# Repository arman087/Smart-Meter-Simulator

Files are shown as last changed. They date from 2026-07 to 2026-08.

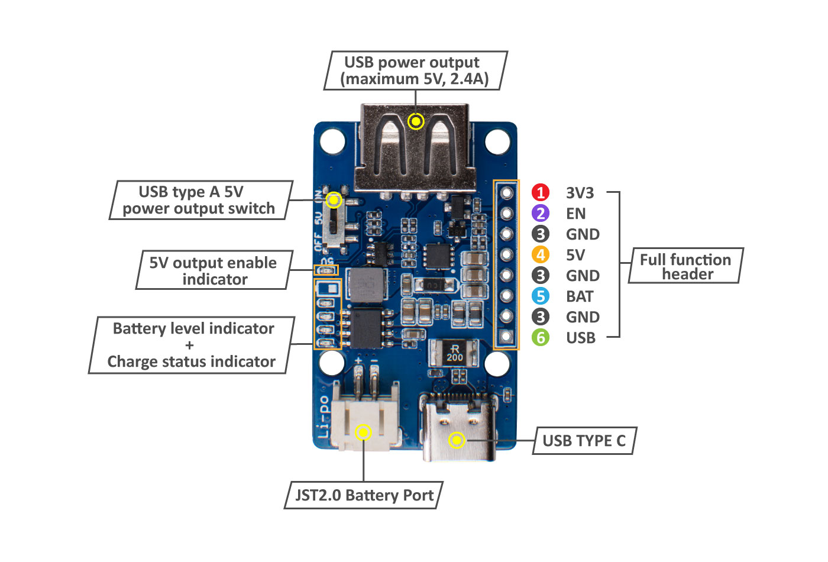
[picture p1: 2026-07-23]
mechanicals/lipo_rider_plus/pinout.jpg

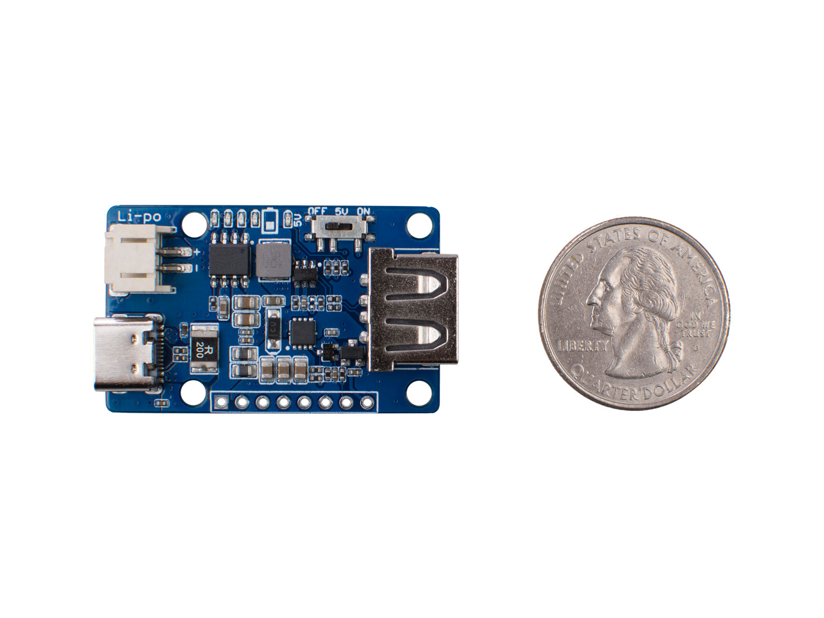
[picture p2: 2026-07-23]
mechanicals/lipo_rider_plus/front.jpg

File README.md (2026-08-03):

# Smart Meter Simulator

Portable lab board that **acts like a Dutch/Belgian DSMR smart meter P1 port**.  
Park it on battery in a building corner, plug in [P1 Ghost](https://github.com/arman087/P1_ghost), and test Ghost Wi‑Fi range without a real meter.

| This board (meter) | P1 Ghost / OSM (reader) |
|---|---|
| Female RJ12 | Male RJ12 |
| **Supplies** +5 V on pin 1 | Takes +5 V |
| **Senses** Data Request on pin 2 | Drives Request high |
| **Open-collector / opto** Data on pin 5 | Reads Data |

**MCU:** ESP32-C3-MINI-1 (Wi‑Fi on for config / OTA) · **P1 serial:** 115200 8N1 inverted open-drain  
**Telegram store:** microSD · **Build volume:** ~5 boards (JLCPCB)

**Why / how:** **[DESIGN_REPORT.md](DESIGN_REPORT.md)** · **Firmware:** **[FIRMWARE_GUIDE.md](FIRMWARE_GUIDE.md)** · **Pause / next:** **[NEXT_STEPS.md](NEXT_STEPS.md)** · **KiCad:** `my_design/Slimme_meter_Sim/`

---

## Progress (schematic + PCB — Aug 2026)

| Block | Status |
|---|---|
| USB-C → bq25185 → TPS61023 → **SYS_5V** | Drawn (`SCH_1_USB_5volt_sch`) |
| **TPS26625** eFuse → `P1_5V`, caps, green power LED, test points, RJ12 | Drawn |
| **SY8088** buck → **VCC_3V3** | Drawn |
| **ESP32-C3-MINI-1** on 3V3; EN RC; GPIO2/8 pull-ups; USB = GPIO18/19 | Drawn |
| RGB on GPIO10; Schottky-fed LED supply | Drawn |
| **6N137S** Data TX (GPIO21 / `ESP32_TX` → pin 5) + Request (`RJ12_pin2` → `ESP32_enable`) | Drawn |
| PCB placement / routing | In progress (saved in KiCad) |
| Assemble first board (stencil + hot air) | See [NEXT_STEPS.md](NEXT_STEPS.md) |
| Optional: Pi as alternate “brain” (own PSU; board keeps P1 power path) | Parked in [NEXT_STEPS.md](NEXT_STEPS.md) |
| microSD, ESD polish | Later |

Sheets: `SCH_1_USB_5volt_sch.kicad_sch` · `SCH_2_power_supplies.kicad_sch`

**Firmware pin polarities / UART invert:** see **[FIRMWARE_GUIDE.md](FIRMWARE_GUIDE.md)** (Request = active **LOW**, Data via OC opto).

---

## Locked power architecture

```
USB-C ──► bq25185 ──► VSYS / V+ (≈3.0–4.5 V) ──► TPS61023 ──► SYS_5V (+5 V)
              │                                      │
           LiPo (2-wire)              ┌──────────────┴──────────────┐
                                      ▼                             ▼
                               SY8088 → 3.3 V              TPS26625 (hiccup)
                                      ▼                             ▼
                                  VCC_3V3                        P1_5V → RJ12 pin1
                                  ESP32 / SD
```

| Net | What it is |
|-----|---|
| `VSYS` / `V+` | bq25185 system rail — **not** 5 V |
| `SYS_5V` | TPS61023 boost |
| `VCC_3V3` | SY8088 from `SYS_5V` |
| `P1_5V` | TPS26625 out (~250 mA DSMR-like) |

---

## What’s left: Request + Data optos (important)

**Do not** wire ESP32 UART TX (3.3 V push-pull) straight to RJ12 pin 5.

There are **two domains**:

1. **MCU side = 3.3 V** — ESP32 GPIO / UART only talks to the **LED** of each opto.  
2. **P1 side = 5 V** — RJ12 pins 1/2/5 live here (`P1_5V`, Request, Data). Opto **transistor** open-collector sits on this side.

### A) Data Request (pin 2 → GPIO) — “Ghost says start sending”

```
RJ12 pin2 (P1_REQ, ~5 V when active)
    │
    R_LED ──►| opto LED |── GND          ← 5 V / P1 side
                   ║
              opto transistor
                   ║
VCC_3V3 ── Rpu ── collector ──► ESP32 GPIO   ← 3.3 V side
                   emitter ── GND
```

- You **never drive** pin 2 from the MCU.  
- Use a **fast** opto (TLP2361 / 6N137 class — not slow PC817).  
- Firmware: GPIO high/low (document polarity) → start/stop telegram TX.

### B) Data out (GPIO TX → pin 5) — open-collector / opto

```
ESP32 TX (3.3 V) ── R_LED ──►| opto LED |── GND     ← 3.3 V side only
                                  ║
                             opto transistor
                                  ║
RJ12 pin5 (P1_DATA) ── collector     (open collector)
                         emitter ── GND
                         optional: 4.7 kΩ to P1_5V for bench without Ghost
```

- **UART pin stays at 3.3 V** — it only lights the opto LED.  
- **Pin 5 is the 5 V / OC world** — transistor pulls Data low; Ghost’s pull-up (or your 4.7 kΩ) makes high.  
- 115200 baud → **fast** opto.  
- Detail notes: `circuits/07_data_request_sense/` · `circuits/08_open_collector_data/`

---

## Subcircuits

| Folder | Status |
|---|---|
| [circuits/01_usb_c_input](circuits/01_usb_c_input) | USB data → ESP32 |
| [circuits/02_battery_and_power_mux](circuits/02_battery_and_power_mux) | bq25185 + TPS61023 |
| [circuits/03_5v_to_3v3](circuits/03_5v_to_3v3) | **SY8088** → 3.3 V |
| [circuits/04_p1_5v_current_limit](circuits/04_p1_5v_current_limit) | **TPS26625** + RILIM calc |
| [circuits/05_esp32_c3_mini](circuits/05_esp32_c3_mini) | ESP32-C3-MINI-1 |
| [circuits/06_rj12_connector](circuits/06_rj12_connector) | RJ12 meter jack |
| [circuits/07_data_request_sense](circuits/07_data_request_sense) | Pin 2 → opto → GPIO **← do next** |
| [circuits/08_open_collector_data](circuits/08_open_collector_data) | TX → opto OC → pin 5 **← do next** |
| [circuits/09_esd_protection](circuits/09_esd_protection) | USB + RJ12 ESD |
| [circuits/10_ui_led_button](circuits/10_ui_led_button) | RGB + optional button |
| [circuits/11_optional_isolation](circuits/11_optional_isolation) | Optos + optional iso DC-DC |
| [circuits/12_microsd](circuits/12_microsd) | microSD |

## References

- [P1 Companion Standard 5.0.2](https://www.netbeheernederland.nl/sites/default/files/2024-02/dsmr_5.0.2_p1_companion_standard.pdf)
- [TI slvaf94 — TPS2662](https://www.ti.com/lit/pdf/slvaf94)
- [TI bq25185](https://www.ti.com/product/BQ25185) · [TI TPS61023](https://www.ti.com/product/TPS61023)
- [arman087/P1_ghost](https://github.com/arman087/P1_ghost)

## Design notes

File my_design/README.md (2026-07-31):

# my_design

Working KiCad for the Smart Meter Simulator:

```
my_design/
  Slimme_meter_Sim/          ← product project (start here)
    SCH_1_USB_5volt_sch…     USB-C → bq25185 → TPS61023 → SYS_5V
```

## Power nets

```
USB-C → bq25185 → V+ / VSYS (3.0–4.5 V) → TPS61023 → +5V (SYS_5V)
```

- **bq25185** system rail = `VSYS` (schematic `V+`) — **not** 5 V  
- **TPS61023** is **required** — do not feed P1 or the 3.3 V regulator from `V+` alone  

## Docs

- [DESIGN_REPORT.md](../DESIGN_REPORT.md) — why / how so far  
- [DESIGN_GUIDE.md](../DESIGN_GUIDE.md) — architecture checklist  
- [PARTS_CHECKLIST.md](../PARTS_CHECKLIST.md)  

## Silicon refs

- https://www.ti.com/product/BQ25185  
- https://www.ti.com/product/TPS61023  
- https://www.ti.com/lit/pdf/slvaf94 (P1 foldback / TPS2662)

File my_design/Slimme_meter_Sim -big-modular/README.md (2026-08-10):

# Slimme meter Sim — big modular (hand-build)

**Active path:** this folder only.  
Parent `DESIGN_GUIDE.md` / root README are **not** source of truth for this build.

Portable **DSMR P1 meter-side** simulator: battery in a corner, Ghost on RJ12, Wi‑Fi range tests without a real meter.

---

## Locked modular plan (return-to-work)

| Piece | How it is built |
|---|---|
| **ESP32-S3** | **Module:** Espressif **ESP32-S3-DevKitC-1-N32R16V** (**WROOM-2**, 32 MB flash + 16 MB PSRAM) — same 2×22 headers, onboard 5 V→3.3 V LDO. Alt: **N16R8V** |
| **USB-C (charge)** | **Breakout module** → soldered/wired to main PCB (not a tiny USB-C footprint on your board) |
| **microSD** | **Breakout module** → SPI wires to DevKit (not onboard SD slot) |
| **Charger IC** | On **main PCB** — hand-solder (bigger package preferred) |
| **5 V boost** | On **main PCB** — hand-solder (**bigger package** preferred) |
| **eFuse / current limit** | On **main PCB** — **both** TPS2662 + TPS2553, select with jumper / 0 Ω |
| **Optos + RJ12** | On **main PCB** — **6N137 DIP-8** ×2, RJ12, ESD |

**Not on main PCB:** DevKit MCU, USB-C receptacle soldering challenge, SD cage soldering challenge.

---

## Power rules (do not loop-charge)

```
Main USB-C breakout ──► charger ──► LiPo / VSYS ──► boost ──► 5V_SYS
                                                              ├── eFuse → RJ12 pin 1
                                                              └── [SW] ──|>|──► DevKit "5V"

DevKit USB ──► program / first flash ONLY
               NEVER wired into the charger
```

| Rule | Why |
|---|-----|
| **Only main USB-C charges** | Avoids boost → DevKit 5V → charger fake-charge loop |
| **`[SW]` between 5V_SYS and DevKit `5V`** | Open while programming on DevKit USB; closed for normal run |
| **Diode on 5V_SYS → DevKit** | Extra reverse protection when switch is closed and habits slip |
| **After first flash** | Prefer Wi‑Fi / OTA; leave DevKit USB unused |

### Switch habit

| Mode | Switch `5V_SYS → DevKit` | USB |
|---|---|-----|
| First flash / recovery | **OPEN** | DevKit USB only |
| Field / normal | **CLOSED** | Main USB-C charge (or battery); talk over Wi‑Fi |

---

## Hand-solder focus (your three ICs)

1. **Charger** (e.g. path like bq25185-class / Adafruit #6106 as reference)  
2. **Boost** — bigger package / module-friendly footprint  
3. **eFuse** — see decision below  

Everything else painful (USB-C, SD) = **bought breakouts**.

---

## eFuse: populate **both**, select one

Put **TPS2662** (foldback / rich) **and** **TPS2553** (bigger / easy) on the same PCB. Only one path to RJ12 pin 1 is live.

```
5V_SYS ──┬──► TPS2662 ──┐
         │              ├── [jumper / 0 Ω / SW] ──► RJ12 pin1
         └──► TPS2553 ──┘
```

| Select | When |
|---|---|
| **TPS2662 path** | Reflow succeeded — use the “amazing” part |
| **TPS2553 path** | Tiny IC bridged / dead / skipped — still ship the board |

**Select hardware (pick one style in KiCad):**
- Two **0 Ω** positions (fit only one), or  
- **2.54 mm jumper** ( clearest for bring-up), or  
- SPDT switch (handy, slightly more drop/noise — fine for P1)

**Do not** leave both outputs paralleled with no select — fight / odd current paths.

Try the tiny IC with paste + hot plate; if it fails, open that path and close TPS2553. No board respin required.

---

## Tomorrow checklist

1. KiCad: power sheet — charger → VSYS → boost → `5V_SYS`  
2. KiCad: DevKit header footprint + **SW + diode** to DevKit `5V`  
3. KiCad: USB-C **breakout** connector footprint / pin header (VBUS, GND, maybe CC if needed)  
4. KiCad: SD **breakout** header (SPI + 3V3 + GND)  
5. KiCad: **both** eFuse footprints + **select jumper/0 Ω** → RJ12  
6. KiCad: 6N137 ×2 + ESD  

Detail: [ARCHITECTURE.md](ARCHITECTURE.md) · [PARTS_CHECKLIST.md](PARTS_CHECKLIST.md)

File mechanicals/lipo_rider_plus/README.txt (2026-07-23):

LIPO RIDER PLUS — DAUGHTERBOARD (CHOSEN POWER)
==============================================

Product
-------
Seeed Studio Lipo Rider Plus (SKU 106990290)
Wiki: https://wiki.seeedstudio.com/Lipo-Rider-Plus/
Buy:  Seeed / distributors — search "Lipo Rider Plus"

This is the project power solution: MCU charger/booster as a daughterboard.
Draw your own footprint if you prefer; files below are a reference.

Mounting on YOUR PCB
--------------------
Files in this folder:

1) Seeed_Lipo_Rider_Plus.kicad_mod
   KiCad footprint for the main board:
   - Board outline (~40.9 × 28.0 mm) from official Eagle .brd
   - 4× M3 clearance holes (3.2 mm) at official positions
   - 1×8 2.54 mm header pads matching J3

   How to use in KiCad:
   - Preferences → Manage Footprint Libraries → add this folder
     (or copy .kicad_mod into your project .pretty)
   - Place footprint; wire pads:
       1 USB   (sense only / optional)
       2 GND
       3 BAT   (optional monitor)
       4 GND
       5 5V    → SYS_5V
       6 GND
       7 EN    (pull to GND to cut 5V; leave open for ON)
       8 3V3   → VCC_3V3

   Stacking tip: solder a male 1×8 header on the Lipo Rider bottom,
   female 1×8 on the main PCB (or wire pads with short jumpers).
   Use M3 standoffs in the four holes.

2) Lipo_Rider_Plus_box.wrl
   Crude 3D placeholder box for KiCad 3D view (not accurate connectors).

3) sch_pcb/Lipo Rider Plus.brd + .sch
   Official Seeed Eagle design (source of outline / holes / header).

4) pinout.jpg / size.jpg / front.jpg
   Official photos from SeeedDocument/Lipo-Rider-Plus on GitHub.

Official / community 3D
-----------------------
- Official mechanical source: Eagle .brd in sch_pcb/ (best for holes).
- Community STEP (used by Printables case authors): search GrabCAD for
  "Lipo Rider Plus" (Joel vL). GrabCAD needs a free account to download.
- 3D-print case reference (mentions that STEP):
  https://www.printables.com/model/569285-seeed-lipo-rider-plus-case

There is NO official Seeed STEP in the public zip we found.
Use GrabCAD STEP for enclosure; use our .kicad_mod for PCB mounting.

Dimensions (from Eagle)
-----------------------
Board outline: 0 … 40.877 mm (X), 2.5 … 27.98 mm (Y) ≈ 41 × 25.5 mm body
Seeed marketing size: 2.5 cm × 4.1 cm

Mounting holes (drill 3.0 mm on module):
  (10.778, 5.04), (10.778, 25.567), (38.337, 5.04), (38.337, 25.567)

Header J3 centre: (23.114, 3.937), 8 pins @ 2.54 mm along X

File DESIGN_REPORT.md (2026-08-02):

# Smart Meter Simulator — Design report

**Status:** Power path through **TPS61023 → SYS_5V** is drawn in KiCad.  
**Working project:** `my_design/Slimme_meter_Sim/` (sheet `SCH_1_USB_5volt_sch`)  
**Date of this milestone:** July 2026

This note records **why** the board exists, **what** was decided, and **how** the first power sheet was built — so the design can be reviewed without guessing from the schematic alone.

---

## 1. Why this board exists

[P1 Ghost](https://github.com/arman087/P1_ghost) is a DSMR **P1 reader**. Developing and field-testing it against real doorstep meters is awkward: access, permission, and fixed locations.

The Smart Meter Simulator is the **meter side** of the RJ12 link:

| Role | Device |
|---|---|
| This board | Meter: female RJ12, **sources** +5 V, **senses** Data Request, **drives** Data |
| P1 Ghost / OSM | Reader: male RJ12, takes +5 V, drives Request, reads Data |

Typical use: battery-powered simulator in a building corner → Ghost on the cable → develop Ghost Wi‑Fi / range elsewhere. Telegrams come from **microSD**, not from a live meter.

Official behaviour follows the [DSMR P1 Companion Standard](https://www.netbeheernederland.nl/sites/default/files/2024-02/dsmr_5.0.2_p1_companion_standard.pdf) (115200 8N1, Request / Data / +5 V pin map, ~250 mA continuous on pin 1 with foldback on overload).

---

## 2. What we need from the power system

Three consumers share one portable board:

1. **ESP32-C3 + microSD (± OLED)** — need a solid **3.3 V**, ≥ **500 mA** headroom for Wi‑Fi bursts.  
2. **P1 port (RJ12 pin 1)** — must look like a real meter: regulated **~5 V**, current-limited with **foldback** (~250 mA continuous).  
3. **1S LiPo** — charge from USB when docked; run from battery in the field.

That forces a clear rail hierarchy:

```
USB-C ──► charger / power-path ──► VSYS (cell or ~4.5 V) ──► boost ──► SYS_5V (+5 V)
                                        │                              │
                                     LiPo                   ┌──────────┴──────────┐
                                                            ▼                     ▼
                                                     5 V → 3.3 V            eFuse / foldback
                                                            ▼                     ▼
                                                       VCC_3V3                 P1_5V → RJ12
```

**SYS_5V is the hub.** Both the MCU regulator and the P1 path take power from the boosted 5 V rail — not from the raw system / battery node.

---

## 3. Decisions that shaped the architecture

### 3.1 One PCB, not a power daughterboard

An early idea was a commercial USB / LiPo “rider” board stacked under the simulator. That was dropped:

- Extra connectors and mechanical stack for only ~5 boards  
- Harder to own the exact rails (true 5 V for P1, ≥500 mA for 3.3 V)  
- Charge / boost / MCU USB data want to live on **one** layout we control  

So charge, boost, MCU, SD, and RJ12 all go on the **main PCB**.

### 3.2 Charger: TI bq25185

Chosen for a compact **1S** design with:

- USB charge input and power-path so the board can run while charging  
- Battery undervoltage lockout (2-wire LiPo is enough)  
- Practical charge / input current around **1 A** — enough for ~250 mA P1 load plus a realistic 3.3 V budget  

**Important:** charger system pin **VSYS** (net `V+` in the schematic) is **not** 5 V. With USB it sits near ~4.5 V; on battery it tracks the cell (~3.0–4.2 V). That rail is only an intermediate supply for the boost.

### 3.3 Boost: TI TPS61023 → SYS_5V

Required, not optional:

| If we skip the boost… | What breaks |
|---|---|
| Feed RJ12 from VSYS | Ghost sees ~3–4 V on battery — not a DSMR-like P1 supply |
| Run a 3.3 V LDO from VSYS alone | No headroom when the cell is low → brown-out under Wi‑Fi |

TPS61023 takes VSYS and makes a fixed **+5 V** (`SYS_5V`). Feedback resistors were picked for 5.0 V (FB stack **732 kΩ / 100 kΩ**). Inductor **1 µH** class for this boost; bulk ceramics next to charger and boost per TI layout practice.

### 3.4 P1 current limit: TI TPS2662 (next sheet)

DSMR expects pin 1 to supply ~**250 mA** continuously and then **fold back** on overload — not only a hard trip. TI documents this use case for smart-meter user ports ([slvaf94](https://www.ti.com/lit/pdf/slvaf94)). That block sits **after** SYS_5V and is not drawn yet on the first sheet.

### 3.5 MCU and storage

| Choice | Reason |
|---|---|
| **ESP32-C3-MINI-1** | Small module, native USB, Wi‑Fi for config / OTA |
| **microSD** | Primary telegram library (Wi‑Fi is not the main store) |
| **No LoRa on simulator** | Out of scope; Ghost carries the radio story |

### 3.6 USB-C

Charge / power USB-C on the first sheet: JLCPCB / LCSC **C165948** (TYPE-C-31-M-12), 5.1 kΩ on CC for sink, D+/D− reserved for ESP32 GPIO18/19 when the MCU sheet lands. Charge current is set with ISET; a small slide switch parallels a second ISET resistor so the board can select ~**500 mA** or ~**1 A** charge without resoldering.

---

## 4. How the first sheet was built

KiCad project: **`my_design/Slimme_meter_Sim/`**  
Sheet: **`SCH_1_USB_5volt_sch.kicad_sch`**

### Done on this milestone

1. USB-C receptacle, CC resistors, input path into **bq25185**  
2. Battery **JST-PH** (S2B-PH-SM4-TB style), charge / status LEDs (CHG / FAULT / 5 V present)  
3. VSET / ILIM and ISET resistor network (including charge-current switch)  
4. **TPS61023** boost with inductor, FB divider, input/output ceramics  
5. Net **SYS_5V** as the feed for the next two supplies (3.3 V regulator + P1 eFuse)

Parts were chosen for **JLCPCB / LCSC** assembly where possible (0402/0603/0805/1206 passives, EasyEDA-exported footprints and 3D models under the project).

### Intentionally not on this sheet yet

- 5 V → 3.3 V regulator (`VCC_3V3`)  
- TPS2662 → `P1_5V` → RJ12  
- ESP32-C3, microSD, Request / Data optos, ESD, UI  

That matches the planned order: finish a measurable **5 V hub**, then hang MCU and P1 off it.

### Quick bring-up targets for sheet 1

1. USB plugged in → battery charges; CHG behaviour sane  
2. `V+` / VSYS present (~4.5 V on USB, tracks cell on battery)  
3. `SYS_5V` ≈ **5.0 V** on USB **and** on battery-only  

---

## 5. Power budget (design intent)

| Rail | Source | Intent |
|---|---|---|
| VSYS / `V+` | bq25185 | Intermediate only |
| `SYS_5V` | TPS61023 | Board 5 V hub (~1 A class IC; real load ≪ that) |
| `P1_5V` | TPS2662 from SYS_5V | ~250 mA continuous, foldback on fault |
| `VCC_3V3` | 5→3.3 from SYS_5V | ≥500 mA for Wi‑Fi |

Ghost on a 250 mA P1 budget: LoRa-only TX is comfortable; Wi‑Fi-only is tight; Wi‑Fi + LoRa TX together may need battery assist or mutually exclusive TX — that is a Ghost firmware constraint, not a reason to raise the meter pin above DSMR.

---

## 6. What “done so far” means

| Area | State |
|---|---|
| Problem / product role | Locked |
| Rail architecture (VSYS → SYS_5V → 3V3 + P1) | Locked |
| KiCad: USB → charge → boost → **SYS_5V** | **Drawn** (sheet 1) |
| KiCad: **TPS26625**, RJ12, caps, P1 LED, test points | **Drawn** (sheet 2) |
| KiCad: **SY8088** → 3.3 V, **ESP32-C3**, USB D+/D−, RGB LED | **Drawn** |
| PCB: components placed, not routed | In progress |
| KiCad: Request + Data **6N137S** optos | **Drawn** |
| Firmware pin / polarity notes | **[FIRMWARE_GUIDE.md](FIRMWARE_GUIDE.md)** |
| microSD / ESD polish / firmware app | Later |

Architecture checklist and KiCad order: [DESIGN_GUIDE.md](DESIGN_GUIDE.md) · Parts: [PARTS_CHECKLIST.md](PARTS_CHECKLIST.md) · Firmware: [FIRMWARE_GUIDE.md](FIRMWARE_GUIDE.md)

---

## 7. References (normative / silicon)

1. [DSMR P1 Companion Standard 5.0.2](https://www.netbeheernederland.nl/sites/default/files/2024-02/dsmr_5.0.2_p1_companion_standard.pdf) — Netbeheer Nederland  
2. [TI bq25185 datasheet](https://www.ti.com/product/BQ25185) — charge + power path  
3. [TI TPS61023 datasheet](https://www.ti.com/product/TPS61023) — VSYS → 5 V boost  
4. [TI slvaf94](https://www.ti.com/lit/pdf/slvaf94) — foldback on smart-meter user ports (TPS2662)  
5. [arman087/P1_ghost](https://github.com/arman087/P1_ghost) — reader under test  
6. [FIRMWARE_GUIDE.md](FIRMWARE_GUIDE.md) — pins, opto polarity, UART

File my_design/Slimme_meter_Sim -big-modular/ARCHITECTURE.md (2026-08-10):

# Architecture — big modular hand-build

## Goal

Battery-powered **P1 meter simulator**: replay telegrams, power Ghost (~250 mA @ 5 V), Wi‑Fi for config/OTA. No LoRa. No power-bank dependence.

## Module map

```
┌─────────────────────────────────────────────────────────────┐
│ MAIN PCB (you solder hard bits + through-hole)              │
│  USB-C breakout ──► charger IC ──► LiPo                     │
│                    └─► VSYS ──► boost IC ──► 5V_SYS         │
│  5V_SYS ──► TPS2662 ─┬─ [SEL jumper/0Ω] ──► RJ12 pin1       │
│           ──► TPS2553┘                                      │
│  5V_SYS ── [SW] ──|>|──► header to DevKit "5V"              │
│  6N137×2 · RJ12 · ESD · (opt INA)                           │
│  headers → SD breakout · headers → DevKit GPIO/UART         │
└─────────────────────────────────────────────────────────────┘
         │                         │
         ▼                         ▼
   ESP32-S3-DevKitC-1-N32R16V  microSD breakout
   (WROOM-2 MCU module)        (SPI module)
```

## Locked MCU module

**ESP32-S3-DevKitC-1-N32R16V** = **ESP32-S3-WROOM-2-N32R16V**  
(alt: **N16R8V** = WROOM-2 16 MB flash + 8 MB PSRAM)

| Need | How DevKit provides it |
|---|---|
| Pin access | Dual 2.54 mm headers (same as N8R8) |
| Memory | More flash/PSRAM than WROOM-1 — good for telegrams / buffers |
| 5 V → 3.3 V | Onboard LDO from `5V` pin **or** DevKit USB |
| Programming | DevKit USB (**switch OPEN**, not tied to charger) |
| Field power | Main `5V_SYS` via **switch + diode** into DevKit `5V` |

**WROOM-2 caveat:** **GPIO35, GPIO36, GPIO37** are used by Octal flash/PSRAM — **do not use** on the carrier (headers may still show them; leave unconnected).

Rejected for this path: CoreS3-as-brain, Thing Plus (no battery→5 V), Feather USB pin as VIN.

## Power path (correct)

```
[Main USB-C breakout] ──► charger VIN ──► battery / VSYS
                                              │
                                              ▼
                                           boost
                                              │
                                              ▼
                                           5V_SYS
                              ┌─────────────┼─────────────┐
                              ▼             ▼             ▼
                          TPS2662       TPS2553     [SW]─|>|─► DevKit 5V
                              │             │
                              └─────[SEL]───┘──► P1 / RJ12 pin1
```

`SEL` = jumper, 0 Ω, or switch — **exactly one** eFuse output connected to RJ12.

### Forbidden loop

Do **not** OR DevKit `5V` / DevKit USB VBUS into charger VIN while also feeding DevKit from `5V_SYS`. That makes:

`battery → boost → “fake USB” → charger → battery`

### Programming vs run

| State | `5V_SYS→DevKit` switch | Who powers ESP |
|---|---|---|
| Flash / serial recovery | OPEN | DevKit USB |
| Battery or main USB charge | CLOSED | `5V_SYS` → diode → DevKit LDO |

After bring-up: charge only on main USB-C; talk over Wi‑Fi.

## What stays modular (avoid tiny soldering)

| Function | Form |
|---|---|
| ESP32-S3 | DevKitC module |
| USB-C receptacle | Breakout → wire/header to charger VBUS/GND |
| microSD | Breakout → SPI to DevKit |

## What you hand-solder on main

| Block | Notes |
|---|---|
| Charger IC | Bigger package if available |
| Boost IC | Bigger package / generous pads |
| eFuse ×2 | **TPS2662** + **TPS2553**; jumper/0 Ω selects one path to RJ12 |
| Passives for those three | 0603/0805 preferred |
| 6N137 DIP | Socket or solder DIP |
| RJ12, ESD, switch, diode, headers | Through-hole friendly where possible |

## P1 / Ghost

| RJ12 | Role |
|---|---|
| Pin 1 | +5 V via eFuse (~250–300 mA limit) |
| Pin 2 | Request → opto → GPIO |
| Pin 5 | Data ← opto OC from UART TX |
| GND | Shared with system for v1 (full float = later / optional iso DC-DC) |

## eFuse dual footprint (locked)

| Path | Part | Role |
|---|---|---|
| A | **TPS2662** | Foldback / preferred if solder OK |
| B | **TPS2553** | Fallback current limit if A fails or is DNP |

Bring-up: attempt A → if good, `SEL` = A. If bridges/shorts/skip, `SEL` = B.

Ghost works on either; foldback is nicer, not mandatory.

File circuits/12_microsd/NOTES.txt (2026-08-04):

12 — microSD (TELEGRAM STORE)
=============================

WHAT THIS BLOCK IS
------------------
Primary offline library of DSMR P1 telegrams for field replay.
Not SDRAM/PSRAM — those are volatile and the wrong tool.

Field flow:
  1. At home: copy .txt telegrams onto the card (or upload via Wi-Fi UI).
  2. In building: ESP32 reads file → plays on P1 when Request is active.

PART
----
Hirose DM3AT-SF-PEJM5 (Card1). SPI only. VCC_3V3 only (never 5 V).

LOCKED SPI MAP (see FIRMWARE_GUIDE.md)
--------------------------------------
  SD_SCK  → GPIO0  → connector CLK  (pin 5)
  SD_MOSI → GPIO1  → connector CMD  (pin 3)
  SD_MISO → GPIO3  → connector DAT0 (pin 7)
  SD_CS   → GPIO6  → connector DAT3 (pin 2)

  VDD pin4 → VCC_3V3 + 10 µF + 100 nF
  VSS pin6 + shell pins → GND
  DAT1/DAT2 → NC (or 10 kΩ to 3V3)
  SW_A / SW_B → unused for v1 (no SD_CD GPIO)

Optional 33–47 Ω series on SPI lines.

FIRMWARE
--------
- FatFS, folder e.g. /telegrams/*.txt
- Detect card via SD.begin() / mount errors (no CD switch)
- MODE (GPIO9) or Wi-Fi UI selects file

KICAD
-----
Away from ESP32 antenna keep-out. Short SPI traces; GND under connector.

TEST
----
Mount card → list files over USB serial.
Select telegram → with Request active, Ghost receives valid frame.

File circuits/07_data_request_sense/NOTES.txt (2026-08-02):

07 — DATA REQUEST SENSE (pin 2 → MCU)
=====================================

WHAT THIS BLOCK IS
------------------
When Ghost / OSM wants telegrams, it drives RJ12 pin 2 HIGH (~4–5.5 V).
MCU must DETECT that and start UART TX. When pin 2 goes high‑Z, stop.

You NEVER drive pin 2 from the MCU.

TWO VOLTAGE DOMAINS (this is the whole point of the opto)
----------------------------------------------------------
  P1 / RJ12 side     ≈ 5 V   (Request comes from Ghost)
  MCU side           = 3.3 V (ESP32 GPIO only)

The opto LED sits on the 5 V Request path.
The opto transistor sits on the 3.3 V GPIO path.
They only couple by light — GPIO never sees 5 V.

EXAMPLE WIRING
--------------
  RJ12 pin2 (P1_REQ)
       │
      Rser (size for ~5–10 mA LED; start ~470 Ω–1 kΩ, check CTR)
       │
       ▼
    opto LED anode
    opto LED cathode ── GND

    opto collector ──┬── Rpu (10 kΩ) ── VCC_3V3
                     └── ESP32 GPIO (e.g. free input)
    opto emitter ── GND

Polarity: document whether GPIO is HIGH or LOW when Request is active
(depends on transistor wiring). Firmware gates TX on that level.

PARTS
-----
**Locked pick (same type for Request + Data): high-speed logic opto with open-collector output**

| Qty | Part | Brand | Why |
|-----|---|---|-----|
| **2** | **6N137** (SMD: e.g. **6N137SDM**) | **onsemi** (or Vishay / Broadcom HCPL-2611) | **10 MBd**, open-collector VO — correct for pin 5 Data; Request uses VO + pull-up to 3.3 V |
| 1 | Optional dual | **Vishay VO2630** / Broadcom **HCPL-2631** | Same speed, **two channels in one IC** |

Search LCSC: `6N137SDM` or `6N137` SOIC-8. Prefer **onsemi / Vishay / Broadcom** — not no-name.

**Premium modern SMD (Toshiba)** — great for Request, **not** alone on pin 5:
  Toshiba **TLP2361** — LCSC **[C123773](https://www.lcsc.com/product-detail/C123773.html)** — 15 Mbps, 2.7–5.5 V VCC.
  Output is **totem-pole (inverted)** → fine into a GPIO; for Data add **BSS138** (drain → pin5) so you stay open-drain.

Do **not** use PC817 / EL817 for Data @ 115200.

Always put **100 nF** between VCC and GND of each 6N137 / TLP2361, right at the package.

KICAD
-----
Nets: P1_REQ, P1_REQ_MCU.
Place near RJ12. Silk: REQ.

TEST
----
Float pin2 → MCU idle (no TX).
Apply ~5 V on pin2 → MCU sees Request → start send. Remove → stop.

FIRMWARE
--------
See ../../FIRMWARE_GUIDE.md
Locked nets: RJ12_pin2 → 330 Ω → U9 → ESP32_enable (10 kΩ to 3V3).
Request active = ESP32_enable LOW. Tie that net to a free GPIO and record it in FIRMWARE_GUIDE.md.

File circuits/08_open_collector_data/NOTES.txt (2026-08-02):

08 — OPEN-COLLECTOR / OPTO DATA (MCU TX → pin 5)
================================================

WHAT THIS BLOCK IS
------------------
DSMR Data (RJ12 pin 5) is open-collector:
  - Meter / simulator only PULLS LOW
  - Ghost / OSM pull-up (1–10 kΩ to ~5 V) makes HIGH
Real meters use an optocoupler on this path.

5 V vs 3.3 V — ANSWER
---------------------
ESP32 UART TX stays on **3.3 V**. It does NOT drive pin 5 directly.

  • 3.3 V domain: ESP32 TX → series R → opto LED → GND
  • 5 V / P1 domain: opto transistor collector → RJ12 pin 5 (OC)
                     emitter → GND
                     optional 4.7 kΩ pin5 → P1_5V for bench without Ghost

So: “Data uses 5 V” means the **RJ12 wire** is in the 5 V OC world.
Your MCU pin never becomes a 5 V output.

EXAMPLE WIRING
--------------
  ESP32 TX (GPIO, 3.3 V UART)
       │
      R_LED (~220–470 Ω; set LED current for CTR + speed)
       │
       ▼
    opto LED ── GND

    RJ12 pin5 (P1_DATA) ── collector (open collector)
    emitter ── GND
    optional: 4.7 kΩ from pin5 to P1_5V

Idle: TX such that LED is OFF → transistor OFF → pin5 pulled high by Ghost.
Mark: TX such that LED ON → transistor ON → pin5 LOW.

Firmware: inverted UART is common on P1 — if gibberish, toggle invert.
Send only while Request (circuit 07) is active.

PARTS
-----
**Same as Request — open-collector high-speed opto:**

| Qty | Part | Brand | LCSC search |
|-----|---|---|---|
| 1 (of 2 total) | **6N137SDM** (or 6N137) | **onsemi** | `6N137SDM` |
| alt dual | VO2630 / HCPL-2631 | Vishay / Broadcom | one IC for Req+Data |

6N137 VO is **open collector** → wire collector to RJ12 pin5 (and optional 4.7k to P1_5V). Perfect DSMR match.

Toshiba **TLP2361** ([C123773](https://www.lcsc.com/product-detail/C123773.html)) is faster/nicer SMD but **totem-pole** — do **not** tie VO to pin5; use TLP2361 → BSS138 → pin5 instead.

Bypass: **100 nF** on opto VCC–GND.
Do NOT use slow PC817 for Data.

MOSFET bring-up fallback (no opto):
  ESP32 TX → gate; source → GND; drain → pin5 (+ 4.7k to P1_5V)
  BSS138 / 2N7002

KICAD
-----
Nets: MCU_P1_TX, P1_DATA.
Place near RJ12. Never route ESP32 TX copper onto pin5.

TEST
----
4.7k to P1_5V on pin5, scope: idle HIGH; "U" stream → clean edges.
Ghost + Request high → valid telegram.

FIRMWARE
--------
See ../../FIRMWARE_GUIDE.md
Locked nets: ESP32_TX (GPIO21 / TXD0) → 220 Ω → U8 → RJ12_Tx_pin5.
UART 115200 8N1; likely TX invert. Gate on Request (ESP32_enable LOW).

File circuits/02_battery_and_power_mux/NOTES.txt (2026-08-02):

02 — POWER: bq25185 + TPS61023 (MAIN PCB)
==========================================

CHOSEN SOLUTION
---------------
Integrate TI **bq25185** (charge + power path) and TI **TPS61023**
(VSYS → fixed +5 V) on the main simulator PCB.

Working schematic: ../../my_design/Slimme_meter_Sim/SCH_1_USB_5volt_sch.kicad_sch

Two ICs — **keep both**:

  1) bq25185  — USB charge, power path, battery BUVLO, VSYS out
  2) TPS61023 — boost VSYS → fixed +5 V (SYS_5V)

Do **not** omit the boost. Do **not** use a stacked LiPo “rider” board
as the primary power design.

NETS (IMPORTANT)
----------------
  VBUS / VIN   USB-C (and optional DC pads — omit if unused)
  VBAT         1S LiPo (2-wire OK; IC has charge terminate + BUVLO)
  VSYS / V+    bq25185 system rail
                 • ~4.5 V with USB
                 • ~3.0–4.2 V on battery only
                 • THIS IS NOT 5 V
  SYS_5V       TPS61023 output — regulated +5 V → rest of board
  EN           boost enable (pull-up to V+; can GPIO later)

POWER FLOW
----------
    USB-C ──► bq25185 ──► V+ / VSYS ──► TPS61023 ──► SYS_5V
                   │                         │
                LiPo                    ┌────┴────┐
                                        ▼         ▼
                                   circuit 03  circuit 04
                                   VCC_3V3     TPS2662 → P1_5V

WHY KEEP TPS61023
-----------------
- RJ12 / Ghost need ~5 V on battery (V+ alone is often 3.3–4.2 V).
- 5→3.3 LDO needs headroom; from a near-empty cell V+ cannot make 3.3 V.

INCLUDE / OMIT
--------------
Include: USB-C charge, JST/battery, bq25185, TPS61023, input protection,
         ISET/VSET, boost inductor + FB resistors, status LEDs as needed.
Omit: unused solar/DC terminal; green 5 V terminal block (use nets).
Layout: keep inductor and charger ceramics tight to the ICs (TI guidance).

SELECTABLE CHARGE CURRENT (ISET)
--------------------------------
Wanted: 250 / 500 / 1000 mA — only one at a time.
ICHG ≈ 300 / RISET → 1.20 kΩ / 604 Ω / 301 Ω.

**One SP3T slide (3 channels, mutually exclusive):**
  SHOU HAN MSK13C02 — LCSC C2681567
  https://www.lcsc.com/product-detail/C2681567.html
  COM→ISET; each throw→one RISET→GND.

**Or 1×3 header + one jumper** (same exclusive idea).

Not three separate switches. Not 2×5. Not ILIM/VSET.

MAIN PCB ALSO HAS
-----------------
- Separate (or carefully shared) USB-C for ESP32 D+/D− (circuit 01)
- 5→3.3 (circuit 03), TPS2662 (circuit 04), etc.

TEST
----
USB charge: CHG LED; VBAT rises to ~4.2 V.
Battery only: SYS_5V still ≈ 5 V; V+ tracks cell.
Fault / empty: boost or load drops cleanly (BUVLO) — no silent deep discharge mess.
Ghost on RJ12 gets ~5 V via TPS2662.

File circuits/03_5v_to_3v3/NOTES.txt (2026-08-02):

03 — 5 V → 3.3 V REGULATOR (MCU RAIL)
=====================================

WHY THIS EXISTS
---------------
ESP32-C3 with Wi-Fi needs a solid **≥500 mA** 3.3 V rail.

Take **SYS_5V** from the **TPS61023** boost (circuit 02) — not from
bq25185 `V+`/`VSYS` (that rail is only 3.0–4.5 V and collapses near
empty battery, so a 3.3 V LDO from V+ will brown out).

FLOW
----
    SYS_5V (+5 V from TPS61023)
         ──► SY8088 (or other ≥500 mA buck) ──► VCC_3V3 ──► ESP32, microSD, logic

NECESSARY PIECES
----------------
1. Regulator IC — **SY8088** locked on Slimme_meter_Sim sheet 2.
2. Input ceramic near VIN (e.g. 10 µF).
3. Output ceramic + bulk near VOUT (e.g. 10 µF + 100 nF).
4. Extra 100 nF at ESP32 VDD pins (circuit 05).

CANDIDATE PARTS (pick one family and lock PN)
---------------------------------------------
**Chosen:** SY8088A-AC (or project MPN on sheet 2) — 5→3.3 buck.

Alternatives if restuffing:
  - AP2112K-3.3 LDO (simpler, more heat)
  - Other ≥500 mA bucks with JLCPCB stock

KICAD
-----
Nets: SYS_5V → VIN; VCC_3V3 → ESP32 / SD / UI.
Keep switcher inductors away from antenna keep-out if using a buck.
Thermal relief / copper for LDO if used.

TEST
----
SYS_5V ≈ 5 V → VCC_3V3 ≈ 3.3 V.
Enable Wi-Fi + SD read: rail stays ≥ 3.2 V (scope/multimeter).
No reset loops under TX peaks.

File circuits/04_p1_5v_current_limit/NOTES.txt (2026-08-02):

04 — P1 +5 V WITH FOLDBACK (DSMR-ALIGNED)
=========================================

WHAT THIS IS
------------
RJ12 pin 1 must SOURCE +5 V like a Dutch P1 meter:

  Continuous     IL_CONT ≈ 250 mA
  Overload trip  ≈ 260–300 mA window (DSMR)
  Foldback       on sustained fault / short → ISC ≤ 50 mA
  Then recover when the fault is gone

Official rules: Netbeheer Nederland P1 Companion Standard v5.0.2 §5.3
(power supply + foldback). Signal side (Request / Data) uses optocouplers
and open-collector Data — that is separate (circuits 07 / 08).

Do **not** cite random GitHub “simulators”. Use the standard + TI’s
P1 protection design.

THE PART THAT MATCHES THIS
--------------------------
**TI TPS2662** eFuse (adjustable ~25 mA … 880 mA)

TI wrote this **for smart-meter P1 +5 V**:

  App note (PDF): https://www.ti.com/lit/pdf/slvaf94
  Title: Fold Back Current Limiting on User Ports of Smart Meters
         (TPS2662; ILIM near DSMR continuous; foldback ~tens of mA on fault).

  Product: https://www.ti.com/product/TPS2662

Buy DigiKey / Mouser: search **TPS2662**.
Optional: TPS2662 EVM to learn, then copy onto the simulator PCB.

HOW IT FITS YOUR BOARD
----------------------
  TPS61023 → SYS_5V (+5 V)   ← circuit 02 (after bq25185 V+)
       │
       ├─► 5→3.3 (circuit 03) → MCU
       │
       ▼
  TPS2662 eFuse  (ILIM ≈ 250–300 mA, foldback path per slvaf94)
       │
       ▼
  P1_5V ──► (± isolated DC-DC, circuit 11) ──► RJ12 pin 1
  (+ bulk ceramic near the jack for OSM inrush)

Do NOT feed TPS2662 from V+/VSYS — that is not a stable 5 V rail.

TI’s note also shows a brief “boost ILIM at startup” trick with an MCU
GPIO so Ghost can charge its caps without sitting forever in foldback.
Optional but smart if Ghost has large bulk caps.

OTHER OPTIONS (WEAKER MATCH)
----------------------------
- Generic 5 V eFuse (TPS2595, STEF05): current **limit**, often not true
  DSMR foldback to ≤50 mA. OK for crude lab, not “as in the standard”.
- Classic LM317 foldback resistor network: educational, not preferred.

KICAD
-----
Place TPS2662 on SYS_5V → P1_5V. Follow slvaf94 schematic (RILIM, soft-start,
FLT, optional MCU ILIM boost). Thick P1_5V / GND to RJ12.

OPTIONAL: JUMPER-SELECT RILIM (LAB)
----------------------------------
IOL ≈ 6.636 / RILIM_kΩ  (amps). Exclusive jumper — one resistor only:

  250 mA → 26.7 kΩ   ← default / DSMR-like
  500 mA → 13.3 kΩ
 1000 mA → 6.65 kΩ

UVLO=4 V / OVP=9 V divider (not EVM 18/30 V values):
  R1=158 kΩ, R2=37.4 kΩ, R3=30.1 kΩ
  Calculator: calc_tps2662_resistors.py

See PARTS_CHECKLIST § B6. Production: hard-wire 26.7 kΩ, no header.

TEST
----
Open: P1_5V ≈ 5 V.
~200 mA load: stays ≥ ~4.9 V.
Hard short pin1–pin6: current collapses into foldback (~tens of mA),
not stuck at 250 mA heating forever; recovers when short removed.

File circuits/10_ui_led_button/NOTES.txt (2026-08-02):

10 — UI: LED + BUTTON (± OLED)
==============================

WHAT THIS BLOCK IS
------------------
Field feedback without a laptop: Request active, sending, SD error,
which telegram / profile, battery/charger status (if sensed).

NECESSARY PIECES
----------------
1. At least one LED + series resistor from GPIO.
2. One tactile button to GND + pull-up (profile select / next file).
3. Avoid boot-strapping pins for the button.

OPTIONAL (RECOMMENDED FOR FIELD USE)
------------------------------------
4. 0.96" OLED SSD1306 I2C — show profile name, REQ, SD OK.
   Power from VCC_3V3; SDA/SCL to free GPIOs.
5. 2×5 2.54 mm male pin header for debug / jumpers / ribbon
   (PEC05DAAN class — see PARTS_CHECKLIST § F5).

RECOMMENDED PARTS
-----------------
- 0603 LED + 1k–3.3k
- 6×6 mm tactile switch
- Optional: SSD1306 0.96" module or bare panel + footprint
- Debug header: any LCSC 2×5P 2.54 mm vertical male pin header
  (BOOMELE / XFCN / Wcon). Do not buy Sullins PEC05DAAN for JLCPCB —
  same footprint, higher price. Search "2x5P 2.54mm" Pin Headers;
  confirm open Dupont pins (not IDC shroud, not R/A, not female).

KICAD
-----
Silk labels for LED meaning. OLED away from antenna if possible.

2×5 debug header (built-in libs, no custom download):
  Symbol:     Connector_Generic:Conn_02x05_Odd_Even
  Footprint:  Connector_PinHeader_2.54mm:PinHeader_2x05_P2.54mm_Vertical

TEST
----
LED toggles; button logged; OLED shows selected telegram name.

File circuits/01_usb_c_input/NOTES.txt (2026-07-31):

01 — USB-C INPUT (ESP32 DATA / FLASH)
====================================

WHAT THIS BLOCK IS
------------------
Board USB-C for **D+/D−** (flash + serial to ESP32-C3).
System 5V / 3.3V / battery charging come from **circuit 02**
(bq25185 + TPS61023 → SYS_5V) — not from a separate power board.

You may share one USB-C carefully with charge, or use a second
receptacle for data-only; do not fight the SYS_5V rail.

NECESSARY PIECES
----------------
1. USB-C receptacle (16-pin mid-mount is fine; 6-pin power-only is NOT enough
   if you want USB data).
2. CC1 / CC2 pulldowns 5.1 kΩ to GND (tells charger / host we are a UFP sink).
3. VBUS → fuse or polyfuse (optional but good) → USB_5V net.
4. ESD diode array on D+ / D- (and preferably VBUS).
5. Series resistors ~22–27 Ω on D+/D- (Espressif reference style) optional.
6. Decoupling: 10 µF + 100 nF on USB_5V near the connector.

RECOMMENDED PARTS (lab / module-friendly)
-----------------------------------------
- Connector: TYPE-C-31-M-12 or Molex/Amphenol 16-pin SMD (reuse Ghost footprint).
- ESD: USBLC6-2SC6 (same as P1 Ghost) or TPD2E001 / PESD5V0x1Bx.
- Optional ready module for bring-up: any USB-C breakout with CC 5.1 kΩ
  pulldowns wired to a breadboard first.

DO NOT FORGET
-------------
ESP32-C3 USB mapping is fixed:
  D- = GPIO18
  D+ = GPIO19
(Wrong pins = no USB device.)

HUMAN / SIMILAR REFERENCES
--------------------------
- Espressif ESP32-C3 hardware design guidelines (USB section):
  https://docs.espressif.com/projects/esp-hardware-design-guidelines/
- Your own P1 Ghost sheet: USB-C + USBLC6 (last check report 02_USB_C_input).
- USB-C breakout guides (CC = 5.1k to GND for sink).

KICAD
-----
- Symbol/footprint: reuse EasyEDA import from P1 Ghost USB-C.
- Official Espressif KiCad libs (for later MCU sheet):
  https://github.com/espressif/kicad-libraries

TEST
----
Plug cable → USB_5V ≈ 5.0 V. Host should enumerate only after MCU is powered
and USB pins are wired correctly.

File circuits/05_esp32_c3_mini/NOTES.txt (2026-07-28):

05 — ESP32-C3-MINI-1 (MCU CORE)
===============================

WHAT THIS BLOCK IS
------------------
Brain: replay telegrams from microSD on P1, Wi-Fi for config/OTA,
USB for first flash/logs, GPIO for Request, UART into Data opto.

NECESSARY PIECES
----------------
1. ESP32-C3-MINI-1 module (N4 / N4U — built-in antenna).
2. VDD decoupling per datasheet (100 nF + bulk near pins) from VCC_3V3.
3. EN pin: RC reset (e.g. 10 kΩ pull-up + 1 µF to GND).
4. Native USB: GPIO18 = D-, GPIO19 = D+ (circuit 01).
5. Antenna keep-out: no ground pour under antenna area.
6. Strap awareness (GPIO8, GPIO9, etc.).

POWER
-----
VCC_3V3 from circuit 03 (from SYS_5V / TPS61023) — never from bq25185 V+/VSYS alone.

PIN PLAN (starter)
------------------
- USB D-/D+     : IO18 / IO19
- UART TX       : → Data opto (circuit 08/11)
- Request sense : GPIO IN ← Request opto (circuit 07/11)
- SPI           : microSD (circuit 12)
- I2C optional  : OLED (circuit 10)
- LED / button  : free GPIOs (circuit 10)

RECOMMENDED PARTS
-----------------
- ESP32-C3-MINI-1-N4 (or N4U)
- Do NOT invent chip-down for v1

REFERENCES
----------
- Espressif ESP32-C3-MINI-1 datasheet + HW guidelines
- https://github.com/espressif/kicad-libraries
- P1 Ghost MCU sheet — reuse keep-out / EN RC

KICAD
-----
Import Espressif footprint. Silk: antenna end clear of metal.

TEST
----
USB enumerates → blink → Wi-Fi STA joins → SD file list → P1 replay.

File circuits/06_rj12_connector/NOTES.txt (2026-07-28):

06 — RJ12 CONNECTOR (P1 METER JACK)
===================================

WHAT THIS BLOCK IS
------------------
Physical DSMR P1 port. On the METER / simulator you use a FEMALE 6P6C
(RJ12) jack. OSM (Ghost) plugs in with a male RJ12 cable.

PINOUT (DSMR) — meter side
--------------------------
 1  +5V         SOURCE via TPS2662 foldback (SYS_5V → P1_5V)
 2  Data Request  INPUT sense (circuit 07)
 3  Data GND    → system GND
 4  n.c.        leave open
 5  Data        open-collector OUT (circuit 08)
 6  Power GND   → system GND

NECESSARY PIECES
----------------
1. RJ12 / 6P6C PCB jack (same family as Ghost is ideal for cable compatibility).
2. Silk labels 1…6 matching the standard (check datasheet pin 1 orientation —
   easy to mirror!).
3. Short fat traces for pins 1 and 6; star GND to digital section if noisy.
4. Optional: shroud / panel cutout note for enclosure.

RECOMMENDED PARTS
-----------------
- KH-PCB-6P6C or equivalent 6P6C vertical / right-angle (Ghost used KH-PCB-6P6C)
- Ready breakout for bench: TinyTronics "RJ12 to Dupont" adapters
  https://www.tinytronics.nl (search RJ12)

REFERENCES
----------
- P1 Companion Standard 5.0.2 — Table 5-1 pin assignment + §5.3 power / foldback
- P1 Ghost last check report 07_USB_sense_RJ12.txt (reader view — invert roles)

KICAD
-----
Reuse Ghost RJ12 footprint from EasyEDA import if pin numbers match
the datasheet. Double-check pin 1 with continuity on a scrap jack.

TEST
----
Continuity: PCB net P1_5V ↔ jack pin 1, etc.
Cable into Ghost: Ghost sees 5 V on its pin 1 when simulator powered.

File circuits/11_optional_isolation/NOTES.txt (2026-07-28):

11 — P1 ISOLATION (OPTOS — IN SCOPE)
===================================

STATUS
------
For this build, optocouplers on Request + Data are **in scope**
(DSMR-like meter behaviour). Full floating P1 ground needs an
isolated 5V DC-DC as well.

THE CORE RULE ABOUT USB DATA
----------------------------
USB D+ / D− need a **shared ground** with the PC when using board USB.
You cannot float USB GND without a USB isolator and still flash.

So: MCU/USB domain can stay common; isolate **RJ12** if you want
protection / realism.

SIGNAL ISOLATION (REQUIRED FOR THIS BUILD)
------------------------------------------
1. Opto / digital isolator: RJ12 pin2 (Request) → ESP32 GPIO
2. Opto / digital isolator + OC: ESP32 TX → RJ12 pin5 (Data)

Parts — **115200 baud needs speed**:
  Prefer: TLP2361, 6N137, Si86xx, ADuM1201-class
  Avoid for Data: PC817 (often too slow)

TRUE GALVANIC ISOLATION (OPTIONAL EXTRA)
----------------------------------------
3. Isolated 5V DC-DC: SYS_5V or P1 path → P1_5V_ISO (≥300 mA; 1W modules
   are often only ~200 mA — check current; may need 2W / higher)
4. Separate GND vs GND_ISO pours; RJ12 pins 3/6 on GND_ISO
5. PCB slot / keep-out under barrier

If you skip (3): shared ground + optos = DSMR-like signals, **not**
full isolation.

USB ISOLATION (SEPARATE TOPIC)
------------------------------
Only if you want PC GND ≠ board GND while using USB data:
  ADuM3160 / ISOUSB211 / external USB isolator dongle.
Not required for v1.

KICAD
-----
Label domains clearly. Place optos near RJ12.
If iso DC-DC: barrier, creepage, silk GND vs GND_ISO.

TEST
----
Request 5V → MCU GPIO toggles through opto.
Data streaming → Ghost valid telegram at 115200.
If iso claimed: ohmmeter USB GND open from RJ12 GND.

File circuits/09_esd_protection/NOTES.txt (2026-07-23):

09 — ESD PROTECTION (USB + RJ12)
================================

WHAT THIS BLOCK IS
------------------
Lab cables get plugged a lot. ESD kills USB PHYs and MOSFET gates.
Cheap insurance: TVS / ESD arrays on exposed connectors.

NECESSARY PIECES
----------------
1. USB: dedicated ESD on D+ / D- (and optionally VBUS).
2. RJ12: clamp pins 1, 2, 5 (power + signals). Pins 3/6 are GND.
3. Short path from TVS to connector GND pad (low inductance).

RECOMMENDED PARTS
-----------------
USB:
  - USBLC6-2SC6 (used on P1 Ghost) — perfect reuse
  - or TPD2E2U06 / PESD5V0x1UL

RJ12 / general:
  - PESD5V0L2BT / PESD5V0S1UL on P1_REQ and P1_DATA
  - SMAJ5.0A or similar on P1_5V if you want beefier power clamp
  - Multi-channel ESD arrays (e.g. TPD4E05U06) if you like one chip

Modules: not really needed — discrete TVS are tiny and cheap.
If you want zero thinking: "USB ESD protector breakout" for USB only.

HUMAN / SIMILAR REFERENCES
--------------------------
- IEC 61000-4-2 mentions in DSMR P1 safety section (context).
- TI / ST ESD app notes for USB 2.0 high-speed routing.
- P1 Ghost schematic: USBLC6 next to USB-C.

KICAD
-----
Place ESD within a few mm of the connector. Via to GND plane under TVS.

TEST
----
No easy home test for ESD rating. Continuity: TVS not shorted;
signal edges still clean at 115200 on Data.

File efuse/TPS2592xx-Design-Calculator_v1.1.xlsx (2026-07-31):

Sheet: Calculation Sheet
TPS2592xx Design Calculation Tool
Constants Cells | Input/SelectCells | Calculation Cells |  |  | Recommended Value
 | Calculated, but can be over-ridden by user
Parameter | Description | Value | Units | Tolerance |  |  |  |  | Version | VOVC (V) | Max Rdson (mΩ) @ 25 degC | Max Rdson (mΩ) @ 125 degC
12V or 5V version | Select among TPS25923x/4x/5x/6x for Over Voltage Clamp | TPS25923 |  |  | 6.1 |  |  |  | TPS25923 | 6.1 | 37 | 48
VIN (max) | Maximum system input voltage (magnitude) | 5.00 | V | % |  |  |  |  | TPS25924 | 15 | 37 | 48
UVset | Power Failure Detection Threshold (VIN Falling) | 4.00 | V |  |  |  |  |  | TPS25925 | 6.1 | 39 | 50
Cout | Load Capacitance | 10.0 | uF | 10.0% |  |  |  |  | TPS25926 | 15 | 39 | 50
Rlstart | Load at start-up (assumed to be resistive) | 4.0 | Ohm |  | 5.7 |  |  |  | TPS25927 | No Clamp | 37 | 48
Imax | Maximum continuous load current (magnitude) | 0.8 | A
Ilimit | Current Limit, 20% higher than maximum continuous load current | 0.96 | A
UVLO set point calculations
R1: Pullup at UVLO Pin | Select a value > 100K to keep I_R12 low | 1000.0 | kOhm | 1.0% |  |  |  | 1000
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

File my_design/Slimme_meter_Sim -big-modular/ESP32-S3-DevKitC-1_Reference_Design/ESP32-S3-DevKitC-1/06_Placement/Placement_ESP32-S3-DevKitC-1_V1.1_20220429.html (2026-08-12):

Create in 2022/4/29 上午 10:58:12 Total components = 48 component(s)

Component Report
NO. | RefDes | PartDecal | Pins | Layer | Orient | PositionX | PositionY | IsSMD
1 | C1 | C0603 | 2 | Top | 90 | 6.528 | 39.675 | Yes
2 | C2 | C0402 | 2 | Top | 270 | 7.036 | 35.611 | Yes
3 | C3 | C0603 | 2 | Top | 0 | 12.725 | 13.059 | Yes
4 | C6 | C0402 | 2 | Top | 0 | 12.497 | 40.437 | Yes
5 | C7 | C0603 | 2 | Top | 180 | 7.290 | 33.833 | Yes
6 | C8 | C0402 | 2 | Top | 90 | 8.306 | 35.611 | Yes
7 | C9 | C0402 | 2 | Top | 270 | 6.147 | 35.611 | Yes
8 | C10 | C0603 | 2 | Top | 180 | 7.290 | 37.389 | Yes
9 | C11 | C0603 | 2 | Top | 180 | 7.239 | 22.428 | Yes
10 | C12 | C0402 | 2 | Top | 270 | 8.255 | 20.523 | Yes
11 | C13 | C0402 | 2 | Top | 0 | 6.248 | 11.459 | Yes
12 | C14 | C0402 | 2 | Top | 180 | 19.075 | 11.459 | Yes
13 | C15 | C0603 | 2 | Top | 0 | 12.725 | 14.834 | Yes
14 | D1 | SOD123 | 2 | Top | 180 | 10.439 | 8.950 | Yes
15 | D2 | SOD523 | 2 | Top | 270 | 4.590 | 9.000 | Yes
16 | D3 | SOD523 | 2 | Top | 270 | 5.994 | 9.000 | Yes
17 | D4 | SOD523 | 2 | Top | 270 | 7.010 | 9.000 | Yes
18 | D5 | LED0603 | 2 | Top | 270 | 19.101 | 34.976 | Yes
19 | D6 | LED3535B | 4 | Top | 270 | 7.493 | 29.083 | Yes
20 | D7 | SOD123 | 2 | Top | 0 | 14.884 | 8.950 | Yes
21 | D8 | SOD523 | 2 | Top | 270 | 17.550 | 9.000 | Yes
22 | D9 | SOD523 | 2 | Top | 270 | 19.070 | 9.000 | Yes
23 | D10 | SOD523 | 2 | Top | 270 | 20.090 | 9.000 | Yes
24 | J1 | CON22X1_2P54_OBLATE | 22 | Bottom | 270 | 1.270 | 61.300 | No
25 | J2 | USB_5P_MICRO_F_ML | 11 | Top | 90 | 6.000 | 4.967 | Yes
26 | J3 | CON22X1_2P54_OBLATE | 22 | Bottom | 270 | 24.130 | 61.300 | No
27 | J4 | USB_5P_MICRO_F_ML | 11 | Top | 90 | 19.400 | 4.967 | Yes
28 | Q1 | SOT23-3 | 3 | Top | 90 | 17.780 | 29.083 | Yes
29 | Q2 | SOT23-3 | 3 | Top | 90 | 12.573 | 29.083 | Yes
30 | R5 | R0402 | 2 | Top | 180 | 10.465 | 40.437 | Yes
31 | R7 | R0402 | 2 | Top | 0 | 18.669 | 21.031 | Yes
32 | R8 | R0402 | 2 | Top | 180 | 13.970 | 25.781 | Yes
33 | R9 | R0402 | 2 | Top | 0 | 18.669 | 19.761 | Yes
34 | R10 | R0402 | 2 | Top | 0 | 16.383 | 25.781 | Yes
35 | R11 | R0402 | 2 | Top | 270 | 19.101 | 38.405 | Yes
36 | R12 | R0402 | 2 | Top | 180 | 18.669 | 25.781 | Yes
37 | R13 | R0402 | 2 | Top | 180 | 11.684 | 25.781 | Yes
38 | R14 | R0402 | 2 | Top | 180 | 6.731 | 17.856 | Yes
39 | R16 | R0402 | 2 | Top | 180 | 6.731 | 18.745 | Yes
40 | R17 | R0402 | 2 | Top | 180 | 8.890 | 25.781 | Yes
41 | R18 | R0402 | 2 | Top | 180 | 6.731 | 21.031 | Yes
42 | R19 | R0402 | 2 | Top | 0 | 6.731 | 20.015 | Yes
43 | R24 | R0603 | 2 | Top | 90 | 8.179 | 39.675 | Yes
44 | SW1 | SW4-4P2X3P2X2P5-SMT | 4 | Top | 180 | 7.525 | 13.959 | Yes
45 | SW2 | SW4-4P2X3P2X2P5-SMT | 4 | Top | 180 | 17.905 | 13.959 | Yes
46 | U2 | SOT223 | 4 | Top | 270 | 10.338 | 36.373 | Yes
47 | U3 | QFN28_0P5_5 | 29 | Top | 270 | 13.589 | 20.142 | Yes
48 | U4 | ESP32-S3-WROOM_NEW | 41 | Top | 0 | 3.750 | 61.650 | Yes

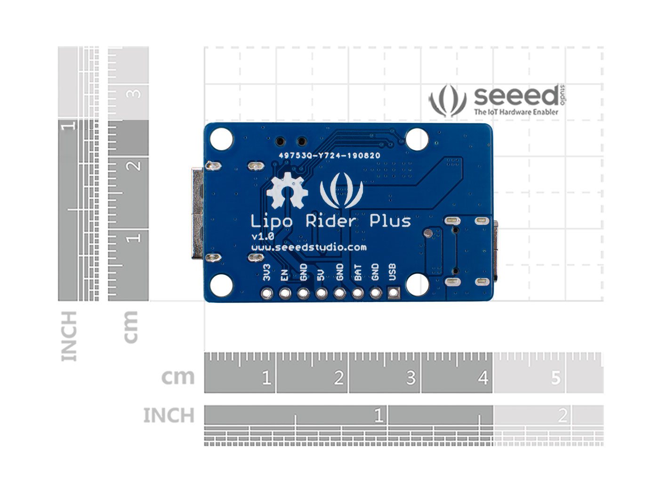
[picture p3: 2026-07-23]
mechanicals/lipo_rider_plus/size.jpg

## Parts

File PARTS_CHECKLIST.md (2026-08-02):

# Parts checklist — choose in KiCad / DigiKey / JLCPCB

Use this while picking footprints and filling the schematic.  
Architecture is locked in [DESIGN_GUIDE.md](DESIGN_GUIDE.md) and [README.md](README.md).

**Legend:** ✅ buy / pick now · 🔧 design on PCB · ○ optional · ✗ skip

---

## A. Power (integrate on main PCB)

| # | Item | Example | Notes | Status |
|---|---|---|---|---|
| A1 | Charger IC | **bq25185** | USB charge, power path, BUVLO | 🔧 |
| A2 | 5 V boost | **TPS61023** + 1 µH + FB | Boosts `V+`/`VSYS` → `SYS_5V`. **Do not omit** | 🔧 |
| A3 | Charge USB-C | e.g. LCSC C165948 | CC 5.1 kΩ; optional share data with ESP32 | 🔧 |
| A4 | Battery connector | JST-PH or pads for 2-wire LiPo | bq25185 manages charge + UVLO | ✅ |
| A5 | 1S LiPo | 1000–3000 mAh | 2-wire OK | ✅ |
| A6 | microSD card | 8–32 GB, FAT32 | Telegram library | ✅ |

Working schematic: `my_design/Slimme_meter_Sim/` · Story: [DESIGN_REPORT.md](DESIGN_REPORT.md)

**Nets:** `VBUS` → bq25185 → `V+`/`VSYS` (3.0–4.5 V) → TPS61023 → `SYS_5V` (+5 V)

### A7 — Selectable charge current (bq25185 ISET)

**You want:** **250 / 500 / 1000 mA**, only **one** path on at a time.  
That means **one** 3-channel selector (SP3T) or **one** jumper — not three switches.

Formula: **ICHG ≈ 300 / RISET**. Use **±1%** resistors.

| Target ICHG | RISET | Part (1%) | LCSC |
|---|---|---|---|
| **250 mA** | **1.20 kΩ** | 1200 Ω | search `1200R 1% 0603` |
| **500 mA** | **604 Ω** | 604 Ω | [C32183](https://www.lcsc.com/product-detail/C32183.html) |
| **1000 mA** | **301 Ω** | 301 Ω | search `301R 1% 0603` |

#### Option A — one SP3T slide (recommended)

**One** switch, three throws, hardware guarantees only one channel:

| Part | LCSC |
|---|---|
| **SHOU HAN MSK13C02** (SP3T) | **[C2681567](https://www.lcsc.com/product-detail/C2681567.html)** |

```
                    ┌── throw1 ── 1.20 kΩ ── GND   → 250 mA
  ISET ── COM ──────┼── throw2 ── 604 Ω   ── GND   → 500 mA
                    └── throw3 ── 301 Ω   ── GND   → 1000 mA
```

Silk: `0.25A / 0.5A / 1A`.

#### Option B — 1×3 header + one Dupont jumper

Same idea as a jumper block: common = ISET; move **one** jumper to pick the current.

KiCad: `Conn_01x03` + `PinHeader_1x03_P2.54mm_Vertical`  
LCSC: search `2.54mm 1x3P` male pin header.

Do **not** change ILIM/VSET (13 kΩ) — that is not ICHG.

---

## B. Rails after SYS_5V

| # | Block | Candidate parts | Pick criteria | Circuit |
|---|---|---|---|---|
| B1 | **5 V → 3.3 V** | AP2112K-3.3, or buck ≥500 mA | From **`SYS_5V`**, not from `V+` | `03` |
| B2 | Bulk / ceramics on 3V3 | 10 µF + 100 nF near ESP32 | Espressif guidelines | `03`/`05` |
| B3 | **TPS2662** P1 eFuse | **TPS2662x** | [slvaf94](https://www.ti.com/lit/pdf/slvaf94) ILIM ≈ 250–300 mA | `04` |
| B4 | TPS2662 support | RILIM, soft-start C, FLT, ceramics | Per datasheet | `04` |
| B5 | P1 bulk near RJ12 | 47–100 µF + 100 nF | Ghost inrush | `04`/`06` |
| B6 | **Selectable P1 ILIM** ○ | Jumper + RILIM set | Lab only — see below | `04` |

### B6 — Selectable P1 current limit (TPS2662 RILIM) — optional

Formula: **IOL ≈ 6.636 / RILIM** with RILIM in **kΩ**, IOL in **A**.  
DSMR continuous target ≈ **250 mA** → RILIM ≈ **26.5 kΩ** (use **26.7 kΩ** 1%).

| Target IOL | RILIM (calc) | Use (E96 1%) |
|---|---|---|
| 100 mA | 66.4 kΩ | **66.5 kΩ** |
| 150 mA | 44.2 kΩ | **44.2 kΩ** |
| 250 mA | 26.5 kΩ | **26.7 kΩ** (default / production) |
| 300 mA | 22.1 kΩ | **22.1 kΩ** |

Same exclusive-jumper pattern as ISET: common = `ILIM` pin, one jumper only.  
Production boards can stuff only **26.7 kΩ** and omit the header.

---

## C. MCU + USB + storage

| # | Block | Candidate parts | Notes | Circuit |
|---|---|---|---|---|
| C1 | MCU | **ESP32-C3-MINI-1-N4** or **N4U** | Module | `05` |
| C2 | EN reset | 10 kΩ + 1 µF | | `05` |
| C3 | Decoupling | 100 nF + bulk | | `05` |
| C4 | Flash USB-C | Receptacle + **2× 5.1 kΩ** CC | May be 2nd connector | `01` |
| C5 | USB ESD | **USBLC6-2SC6** | D+/D− | `01`/`09` |
| C6 | **microSD** | Push-push holder, SPI | | `12` |

**Not needed:** external SDRAM / PSRAM.

---

## D. RJ12 P1 interface

| # | Block | Candidate parts | Notes | Circuit |
|---|---|---|---|---|
| D1 | RJ12 jack | 6P6C **female** | Meter side | `06` |
| D2 | Request opto | TLP2361 / 6N137 / Si86xx | Not PC817 @ 115200 | `07`/`11` |
| D3 | Data opto / OC | Fast opto ± FET | | `08`/`11` |
| D4 | Local Data pull-up | 4.7 kΩ → `P1_5V` | Bench | `08` |
| D5 | RJ12 ESD | Low-cap TVS on 1, 2, 5 | | `09` |

---

## E. Isolation

| # | Item | When | Circuit |
|---|---|---|---|
| E1 | Signal optos | **In scope** | `11` |
| E2 | Isolated 5 V DC-DC | True floating RJ12 GND | `11` ○ |

---

## F. UI / debug

| # | Item | Notes | Circuit |
|---|---|---|---|
| F1 | Status LED | REQ / TX / error | `10` |
| F2 | Button | Profile select | `10` |
| F3 | OLED | Optional | `10` ○ |
| F4 | Test points | `V+`, `SYS_5V`, `P1_5V`, `VCC_3V3`, `P1_REQ`, `P1_DATA` | — |
| F5 | **2×5 pin header** | Debug / jumpers / ribbon — see below | `10` |

### F5 — 2×5 male pin header (PEC05DAAN class)

Classic black “Dupont” style: **10-position (2×5)**, **2.54 mm (0.100")** pitch, dual-row, **vertical through-hole male** pin header. Used on the Smart Meter Simulator for ribbon cable or jumper access (GPIO / rails / bring-up).

You do **not** need the Sullins **PEC05DAAN** brand part (Western premium pricing). Any standard Asian LCSC equivalent that matches the same footprint is fine (usually a few cents).

**Search on LCSC:** `2x5P 2.54mm` or `Pin Header 10 Position 2.54mm Dual Row`  
Filter for **Pin Headers** (open male pins), **straight / vertical**, through-hole — not right-angle, not female sockets, not shrouded IDC box headers unless you specifically want IDC.

Brands that usually stock drop-ins: **BOOMELE**, **XFCN**, **Wcon** (e.g. BOOMELE `2.54-2*5P` in the pin-header category). Confirm photo = open Dupont pins before ordering (many LCSC SKUs share the same MPN string).

**KiCad (built-in — no custom lib):**

| | Library entry |
|--|---|
| Symbol | `Connector_Generic:Conn_02x05_Odd_Even` |
| Footprint | `Connector_PinHeader_2.54mm:PinHeader_2x05_P2.54mm_Vertical` |

That places the exact 2×5 TH grid for a standard ribbon or Dupont jumpers.

---

## G. Explicitly skip

| Item | Why |
|---|-----|
| Omitting **TPS61023** | `V+` is not 5 V; Ghost fails on battery |
| Feeding P1 from `V+` / VSYS | Undervoltage vs DSMR |
| 3.3 V LDO from `V+` only | Browns out when cell ≈ 3.2 V |
| LoRa | Not needed |
| Stacked LiPo rider as primary | Superseded by integrated bq25185 + TPS61023 |
| External SDRAM | Wrong tool |
| Wi‑Fi as primary telegram store | Use microSD |

---

## H. KiCad net names

```
VBUS / VIN     charge USB (and optional DC)
VBAT           LiPo
V+ / VSYS      bq25185 pin 1 (3.0–4.5 V) — not P1 5V
SYS_5V         TPS61023 +5 V
VCC_3V3        from 5→3.3
P1_5V          TPS2662 output
GND / GND_ISO
P1_REQ / P1_REQ_MCU / MCU_P1_TX / P1_DATA
USB_D+ / USB_D-
SD_*
```

---

## I. KiCad order

1. bq25185 + TPS61023 (`02`) — sheet 1 in Slimme_meter_Sim  
2. 5→3.3 (`03`)  
3. TPS2662 (`04`)  
4. USB-C data (`01`)  
5. ESP32 (`05`)  
6. microSD (`12`)  
7. RJ12 + optos (`06`/`11`/`07`/`08`)  
8. ESD + UI (`09`/`10`)  

---

## J. Rough buy / BOM starters

- [ ] bq25185 + TPS61023 + inductor/passives (see Slimme_meter_Sim sheet 1)  
- [ ] 1S LiPo + JST  
- [ ] ESP32-C3-MINI-1-N4(U)  
- [ ] TPS2662  
- [ ] 5→3.3 regulator ≥500 mA  
- [ ] USB-C ×1 or ×2 + USBLC6  
- [ ] RJ12 6P6C female  
- [ ] High-speed optos ×2  
- [ ] microSD holder + card  
- [ ] LED, button, optional OLED  
- [ ] 2×5 2.54 mm male pin header (LCSC pin-header equiv. of PEC05DAAN)  
- [ ] Optional: iso 5V DC-DC  

Detail: `circuits/*/NOTES.txt`

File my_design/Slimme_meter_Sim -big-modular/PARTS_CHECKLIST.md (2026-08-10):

# Parts — big modular hand-build

## Modules (buy assembled)

| Item | Notes |
|---|---|
| **ESP32-S3-DevKitC-1-N32R16V** | DigiKey **1965-ESP32-S3-DEVKITC-1-N32R16V-ND** — WROOM-2; males usually pre-soldered |
| **Male 1×22 header ×2** (spare / if DevKit bare) | Würth **61302211121** or 3M **929647-01-22-EU** — TH, 2.54 mm, vertical |
| **Female 1×22 socket ×2** (on main PCB) | Samtec **SSW-122-01-T-S** or Würth **61302211821** — TH, 2.54 mm; place rows **25.4 mm** apart |
| **USB-C breakout** | VBUS + GND to charger input only (not DevKit charge path) |
| **microSD breakout** | SPI; 3.3 V from DevKit `3V3` |
| LiPo 3.7 V | ≥2000 mAh recommended for multi-hour Ghost + Wi‑Fi |
| Optional: TPS2662 tiny carrier | Only if you keep foldback but refuse QFN on main |

## On main PCB — must hand-solder

| Item | Role | Package preference |
|---|---|---|
| Charger IC (bq25185-class or equiv.) | USB → LiPo / VSYS | Largest available that still fits design |
| Boost IC (TPS61023-class or equiv.) | VSYS → **5V_SYS** | Bigger / hand-friendly |
| **TPS2662** + **TPS2553** | Dual eFuse; select one to RJ12 | Tiny QFN + SOT-23-6 |
| Jumper / 0 Ω / SPDT | Selects which eFuse feeds RJ12 | 2.54 mm jumper clearest |
| Schottky or ideal diode | 5V_SYS → DevKit `5V` | SOD-123 / SMA fine |
| Switch or jumper | Disconnect 5V_SYS from DevKit while flashing | Slide SW or 2.54 mm jumper |
| **6N137** DIP-8 ×2 | Request + Data | DIP / socket |
| RJ12 6P6C female | Meter jack | Through-hole |
| ESD (e.g. USBLC6 / PESD) | RJ12 | Whatever you can solder |
| Headers | DevKit, SD breakout, USB breakout | 2.54 mm |

### eFuse — buy **both** (dual footprint)

| Part | Role |
|---|---|
| **TPS2662** (exact variant + footprint in KiCad) | Primary attempt — foldback |
| **TPS2553DBVR** (SOT-23-6) | Fallback — current limit ~250–300 mA |
| 2.54 mm jumper **or** 0 Ω 0805 ×2 (fit one) **or** SPDT | `SEL` — never parallel both outputs |

Optional reference while PCB evolves: Adafruit **#6106** (charger+boost only).

## Do not put on main PCB (this revision)

- USB-C receptacle footprint (use breakout)
- microSD card cage (use breakout)
- ESP32 module reflow (use DevKitC)

## Do not wire

- DevKit USB VBUS / DevKit `5V` → charger VIN (creates charge loop when boost runs)
- Hard tie `5V_SYS` to DevKit `5V` with no switch (fight when programming)

## Firmware / bring-up order

1. Switch **OPEN** → flash DevKit over its USB  
2. Switch **CLOSED** → run from battery / main USB-C  
3. Enable Wi‑Fi config; stop using DevKit USB day-to-day  
4. SD breakout: load telegrams at home; field = replay only

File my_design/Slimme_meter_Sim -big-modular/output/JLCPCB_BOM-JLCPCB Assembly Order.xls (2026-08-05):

JLCPCB BOM Tool - BOM Matching
BOM name：JLCPCB_BOM-JLCPCB Assembly Order.xlsx |  |  | Download Time：2026-08-06 07:03:47 |  |  |  | * Our matching results are updated in real-time, but stock and prices may change. If it's been over 24 hours, please re-match before placing your order.
PCB Assembled Qty：5 |  |  | Est. Total Price：82.3317
Your BOM |  |  |  |  | Matched Parts |  |  |  |  |  |  | Order Information
Top Designator | Bottom Designator | Comment | Footprint | JLCPCB Part # | Matches | Part # | Manufacturer | Footprint | Description | Category | Warning | JLCPCB Part # | Product link | Lib Type | Qty | Source | Total Price ($)
3V3,RJ12_5V1 |  | RH-5117 | TESTPOINT-TH_BD3.2-D1.6 |  | Unconfirmed | RH-5117 | ronghe | - | 2.5mm Blue Pin Type (Through-Board) - Test Points / Test Rings ROHS | Test Points / Test Rings | 1.There may be multiple types of parts, but one type of part has been matched. Please check.; | C5199807 | https://jlcpcb.com/partdetail/ronghe-RH5117/C5199807 | Extended | 12 | 12 JLCPCB | 0.9864
BATT_POWER_ON_SW1,USB_POWER_ON_SW1 |  | ST-0-102-C04-N008-RS | SW-TH_ST-0-102-C04-N008-RS |  | Unconfirmed | ST-0-102-C04-N008-RS | YUEN FUNG | 弯插,8.3x5.2mm | -25℃~+85℃ 125V 3A 5.2mm 8.3mm Cylinder Lever PC Pin Right Angle SPDT 弯插,8.3x5.2mm Toggle Switches ROHS | Toggle Switches | 1.There may be multiple types of parts, but one type of part has been matched. Please check.; | C1788491 | https://jlcpcb.com/partdetail/YUENFUNG-ST_0_102_C04_N008RS/C1788491 | Extended | 8 | 8 JLCPCB | 6.3512
BT1 |  | BH-18650-B1BA002 | BATTERY-SMD_18650-1S-L77.1-W20.7-1 |  | Select by System | BH-18650-B1BA002 | MYOUNG | SMD | -25~85℃ 18650 Battery holder Gold plating Phosphor bronze - ROHS | Button And Strip Battery Connector |  | C2988620 | https://jlcpcb.com/partdetail/MYOUNG-BH_18650B1BA002/C2988620 | Extended | 0 | 0 JLCPCB | 0
C1,C2,C3,C4,C5,C6,C11,C13,C14,C16,C22,C27,C30 |  | FS31X226M160EPG | C1206 |  | Select by System | FS31X226M160EPG | PSA(Prosperity Dielectrics) | 1206 | 16V 22uF X7R ±20% 1206 Multilayer Ceramic Capacitors MLCC - SMD/SMT ROHS | Multilayer Ceramic Capacitors MLCC - SMD/SMT |  | C3036083 | https://jlcpcb.com/partdetail/3585391-FS31X226M160EPG/C3036083 | Extended | 52 | 52 JLCPCB | 7.8988
C7 |  | C1206C225K3RACTU | C1206 |  | Select by System | C1206C225K3RACTU | KEMET | 1206 | 2.2uF 25V X7R ±10% 1206 Multilayer Ceramic Capacitors MLCC - SMD/SMT ROHS | Multilayer Ceramic Capacitors MLCC - SMD/SMT |  | C2167942 | https://jlcpcb.com/partdetail/KEMET-C1206C225K3RACTU/C2167942 | Extended | 6 | 6 JLCPCB | 0.915
C8 |  | GRM188R71H223KA01D | C0603 |  | Select by System | GRM188R71H223KA01D | Murata Electronics | 0603 | 22nF 50V X7R ±10% 0603 Multilayer Ceramic Capacitors MLCC - SMD/SMT ROHS | Multilayer Ceramic Capacitors MLCC - SMD/SMT |  | C77056 | https://jlcpcb.com/partdetail/MurataElectronics-GRM188R71H223KA01D/C77056 | Extended | 20 | 20 JLCPCB | 0.71
C9,C10 |  | GRM32ER71J106KA12L_C437568 | C1210 |  | Select by System | GRM32ER71J106KA12L | Murata Electronics | 1210 | 10uF 63V X7R ±10% 1210 Multilayer Ceramic Capacitors MLCC - SMD/SMT ROHS | Multilayer Ceramic Capacitors MLCC - SMD/SMT |  | C437568 | https://jlcpcb.com/partdetail/436023-GRM32ER71J106KA12L/C437568 | Extended | 8 | 8 JLCPCB | 7.1904
C12,C17 |  | CL05A105KA5NQNC | C0402 |  | Select by System | CL05A105KA5NQNC | Samsung Electro-Mechanics | 0402 | 1uF 25V X5R ±10% 0402 Multilayer Ceramic Capacitors MLCC - SMD/SMT ROHS | Multilayer Ceramic Capacitors MLCC - SMD/SMT |  | C52923 | https://jlcpcb.com/partdetail/53938-CL05A105KA5NQNC/C52923 | Basic | 20 | 20 JLCPCB | 0.32
C15,C18,C19,C20,C21,C23,C24,C25,C28,C29,C31 |  | CL05B104KO5NNNC | C0402 |  | Select by System | CL05B104KO5NNNC | Samsung Electro-Mechanics | 0402 | 100nF 16V X7R ±10% 0402 Multilayer Ceramic Capacitors MLCC - SMD/SMT ROHS | Multilayer Ceramic Capacitors MLCC - SMD/SMT |  | C1525 | https://jlcpcb.com/partdetail/1877-CL05B104KO5NNNC/C1525 | Basic | 54 | 54 JLCPCB | 0.2916
CARD1 |  | DM3AT-SF-PEJM5 | SD-SMD_DM3AT-SF-PEJM5 |  | Select by System | DM3AT-SF-PEJM5 | HRS(Hirose) | SMD | -25℃~+85℃ 1.68mm Connector and Ejector MicroSD Card (TF Card) No Push-Push SMD SD Card / Memory Card Connector ROHS | SD Card / Memory Card Connector |  | C114218 | https://jlcpcb.com/partdetail/HRS_Hirose-DM3AT_SFPEJM5/C114218 | Extended | 4 | 4 JLCPCB | 5.6928
CN1 | CN2 | S2B-PH-SM4-TB | CONN-SMD_P2.00_S2B-PH-SM4-TB-LF-SN |  | Select by System | S2B-PH-SM4-TB(LF)(SN) | JST | SMD,P=2mm,卧贴 | -25℃~+85℃ 1 100V 1x2P 2 2A 2P 2mm 5.5mm 7.9mm 8.6mm Auxiliary Solder Pin Beige Copper alloy PA PH Surface Mount, Right Angle Tin UL94V-0 SMD,P=2mm,卧贴 Wire To Board Connector ROHS | Wire To Board Connector |  | C295747 | https://jlcpcb.com/partdetail/JST-S2B_PH_SM4_TB_LF_SN/C295747 | Extended | 8 | 8 JLCPCB | 1.708
D1 |  | NSR0320MW2T1G | SOD-323_L1.8-W1.3-LS2.5-RD |  | Select by System | NSR0320MW2T1G | onsemi | SOD-323 | -55℃~+125℃ 1 Independent 1A 20V 500mV@900mA 50uA@15V 5A SOD-323 Schottky Diodes ROHS | Schottky Diodes |  | C48192 | https://jlcpcb.com/partdetail/onsemi-NSR0320MW2T1G/C48192 | Extended | 9 | 9 JLCPCB | 1.1124
D2,D3 |  | SMBJ5.0A-13-F | SMB_L4.6-W3.6-LS5.3-RD |  | Select by System | SMBJ5.0A-13-F | Diodes Incorporated | SMB | -55℃~+150℃ 5V 600W@8.3ms 65.2A 7.23V 800uA 9.2V TVS Unidirectional SMB ESD and Surge Protection (TVS/ESD) ROHS | ESD And Surge Protection (TVS/ESD) |  | C110528 | https://jlcpcb.com/partdetail/DiodesIncorporated-SMBJ5_0A_13F/C110528 | Extended | 10 | 10 JLCPCB | 1.138
D4 |  | B5819W_C8598 | SOD-123_L2.7-W1.6-LS3.7-RD-1 |  | Select by System | B5819W SL | Jiangsu Changjing Electronics Technology Co., Ltd. | SOD-123 | 1A 40V 600mV@1A 9A Independent SOD-123 Schottky Diodes ROHS | Schottky Diodes |  | C8598 | https://jlcpcb.com/partdetail/9093-B5819WSL/C8598 | Basic | 20 | 20 JLCPCB | 0.588
D5 |  | RCLAMP0524P_C907837 | DFN2510-10_L2.5-W1.0-P0.50-BL |  | Select by System | RCLAMP0524P | TECH PUBLIC | DFN2510-10 | -55℃~+125℃ 0.35pF、0.8pF 17V 4.5A 5V 6.8V 80nA ESD Four channels IEC 61000-4-2 Unidirectional DFN2510-10 ESD and Surge Protection (TVS/ESD) ROHS | ESD And Surge Protection (TVS/ESD) |  | C907837 | https://jlcpcb.com/partdetail/TECHPUBLIC-RCLAMP0524P/C907837 | Extended | 8 | 8 JLCPCB | 0.3216
GND1,TP3 |  | RH-5002 | TESTPOINT-TH_BD2.5-D1.2_RH-5002 |  | Unconfirmed | RH-5002 | ronghe | - | 2.5mm Pin Type (Through-Board) White - Test Points / Test Rings ROHS | Pogo Pin Spring Probe Connector | 1.There may be multiple types of parts, but one type of part has been matched. Please check.; | C5199802 | https://jlcpcb.com/partdetail/ronghe-RH5002/C5199802 | Extended | 12 | 12 JLCPCB | 1.0884
L1,L2 |  | MDTA32251B-2R2M | IND-SMD_L3.2-W2.5-BRL3225T100M |  | Select by System | MDTA32251B-2R2M | KOHERelec | 1210 | 2.2uH 3.7A 4.4A 58mΩ Molded Inductor ±20% 1210 Power Inductors ROHS | Power Inductors |  | C22388372 | https://jlcpcb.com/partdetail/KOHERelec-MDTA32251B2R2M/C22388372 | Extended | 8 | 8 JLCPCB | 2.4088
LED1,LED2 |  | 0603Green509-620mcd | LED0603-RD |  | Select by System | KT-0603G | Hubei KENTO Elec | 0603 | -40℃~+85℃ 1.6mm x 0.8mm square LED 100mW 120° 3.1V 430mcd 513nm~528nm 525nm 5mA Discrete Diode Emerald Green Water Clear 0603 LED Indication - Discrete ROHS | LED Indication - Discrete |  | C12624 | https://jlcpcb.com/partdetail/Hubei_KENTOElec-KT0603G/C12624 | Extended | 20 | 20 JLCPCB | 0.242
LED3 |  | DY-S505016/RGBC/6812F-NL-1T | LED-SMD_4P-L5.0-W5.0-BR |  | Select by System | DY-S505016/RGBC/6812F-NL-1T | TONYU | SMD5050-4P | -40℃~+80℃ 1.2kHz 1.6mm 100mcd~300mcd、100mcd~300mcd、900mcd~1200mcd 1mA 2000V 3.7V~5.5V 5.4mm 5mm 800Kbit/s R:620nm~625nm、G:520nm~530nm、B:460nm~470nm SMD5050-4P RGB LEDs(Built-in IC) ROHS | RGB LEDs(Built-In IC) |  | C524052 | https://jlcpcb.com/partdetail/TONYU-DY_S505016_RGBC_6812F_NL1T/C524052 | Extended | 6 | 6 JLCPCB | 0.6954
LED1_RED1 |  | KT-0603R | LED-SMD_L1.6-W0.8-R-RD |  | Select by System | KT-0603R | Hubei KENTO Elec | 0603 | -40℃~+85℃ 1.6mm x 0.8mm square LED 1.8V~2.4V 120° 20mA 300mcd 40mW 615nm~630nm 645nm Discrete Diode Red Water Clear 0603 LED Indication - Discrete ROHS | LED Indication - Discrete |  | C2286 | https://jlcpcb.com/partdetail/Hubei_KENTOElec-KT0603R/C2286 | Basic | 20 | 20 JLCPCB | 0.148
LED3_ORANGE1 |  | KT-0603O | LED0603-RD |  | Select by System | KT-0603O | Hubei KENTO Elec | 0603 | -40℃~+85℃ 1.6mm x 0.8mm square LED 1.8V~2.4V 120° 175mcd 20mA 40mW 598nm~608nm 612nm Discrete Diode Orange Water Clear 0603 LED Indication - Discrete ROHS | LED Indication - Discrete |  | C111340 | https://jlcpcb.com/partdetail/Hubei_KENTOElec-KT0603O/C111340 | Extended | 20 | 20 JLCPCB | 0.232
R1,R2 |  | AR02BTC5101 | R0402 |  | Select by System | AR02BTC5101 | Viking Tech | 0402 | -55℃~+155℃ 25V 5.1kΩ 62.5mW Thin Film Resistor ±0.1% ±25ppm/℃ 0402 Chip Resistor - Surface Mount ROHS | Chip Resistor - Surface Mount |  | C317922 | https://jlcpcb.com/partdetail/VikingTech-AR02BTC5101/C317922 | Extended | 20 | 20 JLCPCB | 0.566
R3,R4,R9,R47 |  | RC0603JR-071KL | R0603 |  | Select by System | RC0603JR-071KL | YAGEO | 0603 | -55℃~+155℃ 100mW 1kΩ 75V Thick Film Resistor ±100ppm/℃ ±5% 0603 Chip Resistor - Surface Mount ROHS | Chip Resistor - Surface Mount |  | C14676 | https://jlcpcb.com/partdetail/YAGEO-RC0603JR071KL/C14676 | Extended | 26 | 26 JLCPCB | 0.1274
R5,R25,R26,R27,R29,R32,R33,R34,R35,R36,R38,R41,R42,R43,R44,R45,R46 |  | AR02BTC1002 | R0402 |  | Select by System | AR02BTC1002 | Viking Tech | 0402 | -55℃~+155℃ 10kΩ 25V 62.5mW Thin Film Resistor ±0.1% ±25ppm/℃ 0402 Chip Resistor - Surface Mount ROHS | Chip Resistor - Surface Mount |  | C317926 | https://jlcpcb.com/partdetail/VikingTech-AR02BTC1002/C317926 | Extended | 76 | 76 JLCPCB | 2.356
R6 |  | 0402WGF1302TCE | R0402 |  | Select by System | 0402WGF1302TCE | UNI-ROYAL(Uniroyal Elec) | 0402 | -55℃~+155℃ 13kΩ 50V 62.5mW Thick Film Resistor ±1% ±100ppm/℃ 0402 Chip Resistor - Surface Mount ROHS | Chip Resistor - Surface Mount |  | C25754 | https://jlcpcb.com/partdetail/26497-0402WGF1302TCE/C25754 | Extended | 20 | 20 JLCPCB | 0.032
R7,R8 |  | 0603WAF6040T5E | R0603 |  | Select by System | 0603WAF6040T5E | UNI-ROYAL(Uniroyal Elec) | 0603 | -55℃~+155℃ 100mW 604Ω 75V Thick Film Resistor ±1% ±100ppm/℃ 0603 Chip Resistor - Surface Mount ROHS | Chip Resistor - Surface Mount |  | C32183 | https://jlcpcb.com/partdetail/33146-0603WAF6040T5E/C32183 | Extended | 20 | 20 JLCPCB | 0.03
R10,R12,R21,R22,R39,R40 |  | 0402WGF1003TCE | R0402 |  | Select by System | 0402WGF1003TCE | UNI-ROYAL(Uniroyal Elec) | 0402 | -55℃~+155℃ 100kΩ 50V 62.5mW Thick Film Resistor ±1% ±100ppm/℃ 0402 Chip Resistor - Surface Mount ROHS | Chip Resistor - Surface Mount |  | C25741 | https://jlcpcb.com/partdetail/26484-0402WGF1003TCE/C25741 | Basic | 34 | 34 JLCPCB | 0.0782
R11 |  | FRC0402F7323TS | R0402 |  | Select by System | FRC0402F7323TS | FOJAN | 0402 | -55℃~+155℃ 50V 62.5mW 732kΩ Thick Film Resistor ±1% ±100ppm/℃ 0402 Chip Resistor - Surface Mount ROHS | Chip Resistor - Surface Mount |  | C5159692 | https://jlcpcb.com/partdetail/FOJAN-FRC0402F7323TS/C5159692 | Extended | 20 | 20 JLCPCB | 0.042
R13 |  | CR0603-FX-3012ELF | R0603 |  | Select by System | CR0603-FX-3012ELF | BOURNS | 0603 | -55℃~+155℃ 100mW 30.1kΩ 50V Thick Film Resistor ±1% ±100ppm/℃ 0603 Chip Resistor - Surface Mount ROHS | Chip Resistor - Surface Mount |  | C203506 | https://jlcpcb.com/partdetail/BOURNS-CR0603_FX3012ELF/C203506 | Extended | 20 | 20 JLCPCB | 0.172
R14 |  | CRCW06037K50FKEA | R0603 |  | Select by System | CRCW06037K50FKEA | Vishay Intertech | 0603 | -55℃~+155℃ 100mW 7.5kΩ 75V Thick Film Resistor ±1% ±100ppm/℃ 0603 Chip Resistor - Surface Mount ROHS | Chip Resistor - Surface Mount |  | C844808 | https://jlcpcb.com/partdetail/VishayIntertech-CRCW06037K50FKEA/C844808 | Extended | 8 | 8 JLCPCB | 0.064
R15 |  | RS-03K1332FT | R0603 |  | Select by System | RS-03K1332FT | FH (Guangdong Fenghua Advanced Tech) | 0603 | -55℃~+155℃ 100mW 13.3kΩ 50V Thick Film Resistor ±1% ±100ppm/℃ 0603 Chip Resistor - Surface Mount ROHS | Chip Resistor - Surface Mount |  | C321713 | https://jlcpcb.com/partdetail/302618-RS03K1332FT/C321713 | Extended | 20 | 20 JLCPCB | 0.064
R16 |  | AR03FTC2672 | R0603 |  | Select by System | AR03FTC2672 | Viking Tech | 0603 | -55℃~+155℃ 26.7kΩ 50V 62.5mW Thin Film Resistor ±1% ±25ppm/℃ 0603 Chip Resistor - Surface Mount ROHS | Chip Resistor - Surface Mount |  | C234417 | https://jlcpcb.com/partdetail/VikingTech-AR03FTC2672/C234417 | Extended | 20 | 20 JLCPCB | 0.218
R17 |  | HRC0603F2673ENTN | R_0603_1608Metric |  | Select by Customer | HRC0603F2673ENTN | HWA CHN | 0603 | 0603 Chip Resistor - Surface Mount ROHS |  |  | C55098397 | https://jlcpcb.com/partdetail/HWACHN-HRC0603F2673ENTN/C55098397 | Extended | 20 | 20 JLCPCB | 0.024
R18 |  | CR0603-FX-3742ELF | R0603 |  | Select by System | CR0603-FX-3742ELF | BOURNS | 0603 | -55℃~+155℃ 100mW 37.4kΩ 50V Thick Film Resistor ±1% ±100ppm/℃ 0603 Chip Resistor - Surface Mount ROHS | Chip Resistor - Surface Mount |  | C203565 | https://jlcpcb.com/partdetail/BOURNS-CR0603_FX3742ELF/C203565 | Extended | 20 | 20 JLCPCB | 0.156
R19 |  | RS-03K1583FT | R0603 |  | Select by System | RS-03K1583FT | FH (Guangdong Fenghua Advanced Tech) | 0603 | -55℃~+155℃ 100mW 158kΩ 50V Thick Film Resistor ±1% ±100ppm/℃ 0603 Chip Resistor - Surface Mount ROHS | Chip Resistor - Surface Mount |  | C321734 | https://jlcpcb.com/partdetail/302639-RS03K1583FT/C321734 | Extended | 20 | 20 JLCPCB | 0.062
R20,R30 |  | ERJP03F3300V | R0603 |  | Select by System | ERJP03F3300V | PANASONIC | 0603 | -55℃~+155℃ 200mW 330Ω Thick Film Resistor ±1% ±200ppm/℃ 0603 Chip Resistor - Surface Mount ROHS | Chip Resistor - Surface Mount |  | C427299 | https://jlcpcb.com/partdetail/PANASONIC-ERJP03F3300V/C427299 | Extended | 12 | 12 JLCPCB | 0.5232
R23 |  | RT0402FRE07309RL | R0402 |  | Select by System | RT0402FRE07309RL | YAGEO | 0402 | -55℃~+155℃ 309Ω 50V 62.5mW Thin Film Resistor ±1% ±50ppm/℃ 0402 Chip Resistor - Surface Mount ROHS | Chip Resistor - Surface Mount |  | C327013 | https://jlcpcb.com/partdetail/YAGEO-RT0402FRE07309RL/C327013 | Extended | 20 | 20 JLCPCB | 0.276
R24 |  | SCR0402F68R1 | R0402 |  | Select by System | SCR0402F68R1 | VO | 0402 | -55℃~+155℃ 50V 62.5mW 68.1Ω Thick Film Resistor ±1% ±100ppm/℃ 0402 Chip Resistor - Surface Mount ROHS | Chip Resistor - Surface Mount |  | C3015640 | https://jlcpcb.com/partdetail/VO-SCR0402F68R1/C3015640 | Extended | 20 | 20 JLCPCB | 0.012
R28 |  | 0402WGF3300TCE | R0402 |  | Select by System | 0402WGF3300TCE | UNI-ROYAL(Uniroyal Elec) | 0402 | -55℃~+155℃ 330Ω 50V 62.5mW Thick Film Resistor ±1% ±100ppm/℃ 0402 Chip Resistor - Surface Mount ROHS | Chip Resistor - Surface Mount |  | C25104 | https://jlcpcb.com/partdetail/25847-0402WGF3300TCE/C25104 | Basic | 20 | 20 JLCPCB | 0.164
R37 |  | 0603WAF2200T5E | R0603 |  | Select by System | 0603WAF2200T5E | UNI-ROYAL(Uniroyal Elec) | 0603 | -55℃~+155℃ 100mW 220Ω 75V Thick Film Resistor ±1% ±100ppm/℃ 0603 Chip Resistor - Surface Mount ROHS | Chip Resistor - Surface Mount |  | C22962 | https://jlcpcb.com/partdetail/23689-0603WAF2200T5E/C22962 | Basic | 20 | 20 JLCPCB | 0.176
RJ1 |  | KH-PCB-6P6C | RJ45-TH_KH-PCB-6P6C |  | Select by System | KH-PCB-6P6C | Shenzhen Kinghelm Elec | 弯插 | -45℃~+85℃ 1 Gold Non-LED Non-PoE Phosphor bronze RJ45 Jack Right Angle Unshielded 弯插 Ethernet Connectors / Modular Connectors (RJ45 RJ11) ROHS | Ethernet Connectors / Modular Connectors (RJ45 RJ11) |  | C2683354 | https://jlcpcb.com/partdetail/Shenzhen_KinghelmElec-KH_PCB6P6C/C2683354 | Extended | 4 | 4 JLCPCB | 0.448
SW1 |  | MSK12C02 | SW-TH_MSK12C02 |  | Select by System | MSK12C02 | SHOU HAN | SMD,8x2.8mm | -20℃~+70℃ 1.4mm 10000 times 12V 2.8mm 50mA 8mm SMD(SMT) Tab SPDT Surface Mount, Right Angle SMD,8x2.8mm Slide Switches ROHS | Slide Switches |  | C431540 | https://jlcpcb.com/partdetail/SHOUHAN-MSK12C02/C431540 | Extended | 8 | 8 JLCPCB | 0.4496
SW2,SW3 |  | TS665CJ | SW-TH_4P-L6.0-W6.0-P4.50-LS6.5 |  | Select by System | TS665CJ | SHOU HAN | 插件-4P,6x6mm | -25℃~+70℃ 12V 2.5N 50,000 cycles 50mA 5mm 6mm 6mm Black No PC Pin Round Button SPST Through Hole Without Bracket 插件-4P,6x6mm Tactile Switches ROHS | Tactile Switches |  | C393938 | https://jlcpcb.com/partdetail/SHOUHAN-TS665CJ/C393938 | Extended | 9 | 9 JLCPCB | 0.1737
SW4 |  | SK-1500-L1? | SW-SMD_6P-P1.50_L2.7-W11.2 |  | Select by System | SK-1500-L1 | XKB Connection | SMD,11.2x2.7mm | -40℃~+85℃ 1.4mm 10000 times 11.2mm 12V 2.7mm 50mA Black Rectangular Columnar SMD(SMT) Tab SP4T Surface Mount, Right Angle SMD,11.2x2.7mm Slide Switches ROHS | Slide Switches |  | C319025 | https://jlcpcb.com/partdetail/XKBConnection-SK_1500L1/C319025 | Extended | 4 | 4 JLCPCB | 1.0896
U1 |  | USBLC6-2SC6-ES | SOT-23-6_L2.9-W1.6-P0.95-LS2.8-BR |  | Select by System | USBLC6-2SC6-ES | ElecSuper | SOT-23-6L | -40℃~+85℃ 0.6pF 15V 1uA 2 4.5A 5V 6V 70W@8/20us ESD IEC 61000-4-2 Unidirectional SOT-23-6L ESD and Surge Protection (TVS/ESD) ROHS | ESD And Surge Protection (TVS/ESD) |  | C5180249 | https://jlcpcb.com/partdetail/ElecSuper-USBLC6_2SC6ES/C5180249 | Extended | 10 | 10 JLCPCB | 0.276
U2 |  | BQ25185DLHR | WSON-10_L2.2-W2.0-P0.40-BL-EP_TI_DLH0010A |  | Select by System | BQ25185DLHR | Texas Instruments | WSON-10-EP(2.2x2) | -40℃~+125℃ 1 1A 2.2V 3V~18V 4.4V 4uA Charging IC Lithium Battery、LiFePO4 Battery Support WSON-10-EP(2.2x2) Battery Management ROHS | Battery Management |  | C19725033 | https://jlcpcb.com/partdetail/TexasInstruments-BQ25185DLHR/C19725033 | Extended | 4 | 4 JLCPCB | 6.4544
U3 |  | TPS61023DRLR | SOT-563_L1.6-W1.2-P0.50-LS1.6-BR |  | Select by System | TPS61023DRLR | Texas Instruments | SOT-563 | -40℃~+125℃@(TJ) 1 1MHz 2.2V~5.5V 3A 3uA 500mV~5.5V Adjustable Boost Boost Built-in Overcurrent Protection、Light load efficient mode、Load disconnect Yes SOT-563 DC-DC Converters ROHS | DC-DC Converters |  | C919459 | https://jlcpcb.com/partdetail/TexasInstruments-TPS61023DRLR/C919459 | Extended | 5 | 5 JLCPCB | 1.279
U4 |  | TPS26625DRCR | VSON-10_L3.0-W3.0-P0.50-TL-EP-1 |  | Select by System | TPS26625DRCR | Texas Instruments | SON-10(3x3) | -40℃~+125℃ 0.9mm 1 3mm 3mm 4.5V~60V 478mΩ Integrated FET Surface Mount SON-10(3x3) Surge Protection Devices (SPDs) ROHS | Surge Protection Devices (SPDs) |  | C2862873 | https://jlcpcb.com/partdetail/TexasInstruments-TPS26625DRCR/C2862873 | Extended | 4 | 4 JLCPCB | 8.9588
U5,U11,U12,U13 |  | C1206C105K3RACAUTO | C1206 |  | Select by System | C1206C105K3RACAUTO | KEMET | 1206 | 1uF 25V X7R ±10% 1206 Multilayer Ceramic Capacitors MLCC - SMD/SMT ROHS | Multilayer Ceramic Capacitors MLCC - SMD/SMT |  | C2167173 | https://jlcpcb.com/partdetail/KEMET-C1206C105K3RACAUTO/C2167173 | Extended | 20 | 20 JLCPCB | 1.98
U6 |  | SY8088AAC | SOT-23-5_L3.0-W1.7-P0.95-LS2.8-BR |  | Select by System | SY8088AAC | Silergy Corp | SOT-23-5 | -40℃~+85℃@(TA)、-40℃~+125℃@(TJ) 1 1.5MHz 1A 2.5V~5.5V 40uA Adjustable Buck Buck Built-in Yes SOT-23-5 DC-DC Converters ROHS | DC-DC Converters |  | C79313 | https://jlcpcb.com/partdetail/SilergyCorp-SY8088AAC/C79313 | Extended | 6 | 6 JLCPCB | 0.5958
U7 |  | ESP32-C3-MINI-1-H4X | WIFIM-SMD_ESP32-C3-MINI-1 |  | Select by System | ESP32-C3-MINI-1-H4X | Espressif Systems | SMD,16.6x13.2mm | -104dBm -40℃~+105℃ 2.4GHz 20.5dBm 350mA 3V~3.6V 82mA ESP32-C3FH4 On-board PCB Antenna UART、SPI、I2C、GPIO、I2S、USB SMD,16.6x13.2mm WiFi Modules ROHS | WiFi Modules |  | C41349510 | https://jlcpcb.com/partdetail/43083447-ESP32_C3_MINI_1H4X/C41349510 | Extended | 4 | 4 JLCPCB | 11.5664
U8,U9,U10 |  | 6N137S_C20612601 | SOP-8_L9.7-W6.5-P2.54-LS10.3-BL |  | Select by System | 6N137S | AOTE | SMD-8P | -40℃~+85℃ 1 1.33V 100ns 100ns 10Mbps 10kV/us 2.7V~5.5V 20mA 50mA 5V 5kV 5mA DC SMD-8P Logic Output Optoisolators ROHS | Logic Output Optoisolators |  | C20612601 | https://jlcpcb.com/partdetail/AOTE-6N137S/C20612601 | Extended | 12 | 12 JLCPCB | 3.1416
USBC1 |  | TYPE-C-31-M-12 | USB-C_SMD-TYPE-C-31-M-12_1 |  | Select by System | TYPE-C-31-M-12 | Korean Hroparts Elec | SMD | -30℃~+80℃ 1 10,000 cycles 16P 20V 5A 7.35mm Female Surface Mount, Right Angle Type-C SMD USB Connectors ROHS | USB Connectors |  | C165948 | https://jlcpcb.com/partdetail/Korean_HropartsElec-TYPE_C_31_M12/C165948 | Extended | 4 | 4 JLCPCB | 0.7372

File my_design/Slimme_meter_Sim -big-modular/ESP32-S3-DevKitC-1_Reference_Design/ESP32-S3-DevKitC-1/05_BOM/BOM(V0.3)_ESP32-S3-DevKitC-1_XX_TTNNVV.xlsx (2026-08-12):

BOM(V0.3)_ESP32-S3-DevKitC-1
Item Number | Quantity | Part Reference | Value | PCB Footprint | Part Type | Description | Manufacturer | Manufacturer Part #
1 | 3 | C2,C8,C9 | 0.1uF/50V(10%) | C0402 | Capacitor | MLCC, X5R, H0.5, -55℃~85℃ | EYANG | C0402X5R104K500NTC
 |  |  |  |  | Capacitor | MLCC, X5R, H0.5, -55℃~85℃ | Sumsang | CL05A104KB5NNNC
 |  |  |  |  | Capacitor | MLCC, X7R, H0.5, -55℃~125℃ | muRata | GRM155R71H104KE14D
2 | 2 | C6,C12 | 1uF/16V(10%) | C0402 | Capacitor | MLCC, X6S, H0.5, -55℃~105℃ | muRata | GRM155C81C105KE11D
3 | 5 | C1,C3,C7,C10,C11 | 10uF/25V(20%) | C0603 | Capacitor | MLCC, X5R, H0.8, -55℃~85℃ | muRata | GRM188R61E106MA73D
4 | 5 | R7,R8,R9,R13,R17 | 0(1%) | R0402 | Resistor | Thick Film Resistors, SMD, 0(1%), 1/16w, H0.35, -55℃~155℃ | UniOhm | 0402WGF0000TCE
 |  |  |  |  | Resistor | Thick Film Resistors, SMD, 0(1%), 1/16w, H0.35, -55℃~155℃ | YAGEO | RC0402FR-070RL
5 | 1 | R24 | 0(1%) | R0603 | Resistor | Thick Film Resistors, SMD, 1, 1/10w, H0.45, -55℃~155℃ | UniOhm | 0603WAF0000T5E
 |  |  |  |  | Resistor | Thick Film Resistors, SMD, , 1/10w, H0.45, -55℃~155℃ | YAGEO | RC0603FR-070RL
6 | 1 | R16 | 1K(1%) | R0402 | Resistor | Thick Film Resistors, SMD, 1K(1%), 1/16w, H0.35, -55℃~155℃ | UniOhm | 0402WGF1001TCE
 |  |  |  |  | Resistor | Thick Film Resistors, SMD, 1K(1%), 1/16w, H0.35, -55℃~155℃ | YAGEO | RC0402FR-071KL
7 | 1 | R11 | 5.1K(1%) | R0402 | Resistor | Thick Film Resistors, SMD, 5.1K(1%), 1/16w, H0.35, -55℃~155℃ | UniOhm | 0402WGF5101TCE
 |  |  |  |  | Resistor | Thick Film Resistors, SMD, 5.1K(1%), 1/16w, H0.35, -55℃~155℃ | YAGEO | RC0402FR-075K1L
8 | 3 | R5,R10,R12 | 10K(1%) | R0402 | Resistor | Thick Film Resistors, SMD, 10K(1%), 1/16w, H0.35, -55℃~155℃ | UniOhm | 0402WGF1002TCE
 | 3 | R5,R10,R12 |  |  | Resistor | Thick Film Resistors, SMD, 10K(1%), 1/16w, H0.35, -55℃~155℃ | YAGEO | RC0402FR-0710KL
9 | 1 | R19 | 22.1K(1%) | R0402 | Resistor | Thick Film Resistors, SMD, 22.1K(1%), 1/16w, H0.35, -55℃~155℃ | UniOhm | 0402WGF2212TCE
 |  |  |  |  | Resistor | Thick Film Resistors, SMD, 22.1K(1%), 1/16w, H0.35, -55℃~155℃ | YAGEO | RC0402FR-0722K1L
10 | 1 | R18 | 47.5K(1%) | R0402 | Resistor | Thick Film Resistors, SMD, 47.5K(1%), 1/16w, H0.35, -55℃~155℃ | UniOhm | 0402WGF4752TCE
 |  |  |  |  | Resistor | Thick Film Resistors, SMD, 47.5K(1%), 1/16w, H0.35, -55℃~155℃ | UniOhm | 0402WGF4752TCE
11 | 2 | D1,D7 | 1N5819HW-7-F | SOD123 | Diode | Schottky Barrier Diodes,Vrms=40V,If=1.0A,Vf=0.45V,Ifsm=25A, H1.35, Tj-65℃~+125℃ | Diodes Incorporated | 1N5819HW-7-F
12 | 6 | D2,D3,D4,D8,D9,D10 | LESD5D5.0CT1G | SOD523 | Diode | ESD,Bidirectional,Vrwm=5.0V,Vbr=7.8V,Cd=15pF, H0.7, -40℃~+125℃ | LRC | LESD5D5.0CT1G
13 | 1 | D5 | RED LED | LED0603 | Diode | Light-Emitting Diode:Red LED, IF=25mA, VR=5V, 65mW, H0.6, -30℃~85℃ | NationStar | FC-DA1608HRK-620D
 |  |  |  |  | Diode | Light-Emitting Diode:Red LED, IF=20mA, VR=5V, 50mW, H0.6, -40℃~85℃ | 贝益达电子 | BD-PT0603R6C-C01-4T
14 | 1 | D6 | SK68XXMINI-HS | LED3535B | Diode | Light-Emitting Diode: 1-wire RGB: Intelligent Control LED Integrated Light Source, 3535, H1.9, -25℃~85℃ | Worldsemi | WS2812B-Mini-V3
15 | 2 | J1,J3 | CON22X1 | CON22X1_2P54 | Connector | Male Pin Header, 单排排针, 22Pins, 间距 2.54mm, 镀金 1U | - | -
16 | 2 | J2,J4 | MICRO USB | USB_5P_MICRO_F_ML | Connector | Micro USB 5P,Female, 4-DipLeg, H3.0, -30℃~+85℃ | 敏乐 | 1110-205001
 |  |  |  |  | Connector | Micro USB 5P,Female, B Type, 插板7.2有柱, 脚长1.1, 四脚全插, 加长0.75（卷边）, H2.61, -30℃~+80℃ | U-wilcome | I42-0531-3121
17 | 2 | Q1,Q2 | L8050QLT1G | SOT23-3 | Transistor | NPN,Ic.max=0.8A,Vbe(sat)=0.5V@Ic=800mA&Ib=80mA, H1.11, Tj-55℃~+150℃ | LRC | L8050QLT1G
18 | 2 | SW1,SW2 | NTC013-AT1J-A160T | SW4-4P2X3P2X2P5-SMT | Tact Switch | Tact Switch: SMT, 4P, operation force 1.57N, Stem Black Color, 4.2x3.2x2.5, SMD, -40℃~85℃ | TAIWAN MISAKI | NTC013-AT1J-A160T
19 | 1 | U2 | SGM2212-3.3XKC3G/TR | SOT223 | Power ICs | LDO,Input.max=20V,Iout.max=800mA,Fixed-Output=3.3V,Vdrop=0.42V@Iout=0.8A,H1.8,-40~+125°C | SG Micro | SGM2212-3.3XKC3G/TR
20 | 1 | U3 | CP2102N-A02-GQFN28 | QFN28_0P5_5 | Interface ICs | USB-TO-UART,USB2.0 full speed,data rate up to 3Mbaud,H0.8, -40°C~+85°C | SiliconLabs | CP2102N-A02-GQFN28
21 | 1 | U4 | ESP32-S3-WROOM-1 | ESP32-S3-WROOM_NEW | Module | 根据客供模组型号进行贴件 | Espressif Systems | ESP32-S3-WROOM-1/ESP32-S3-WROOM-2
22 | 1 | PCB | - | - | - | ESP32-S3-DevKitC-1_V1.1_20220429, 2L, 62.74*25.4*1.6mm, 哑光黑色阻焊, 白色字符, 化学沉金,USB 走线 90R 阻抗管控 | - | -

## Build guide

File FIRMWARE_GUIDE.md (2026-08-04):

# Firmware guide — Smart Meter Simulator

**Audience:** firmware / bring-up for ESP32-C3 on this PCB.  
**Hardware:** `my_design/Slimme_meter_Sim/` · Architecture: [DESIGN_GUIDE.md](DESIGN_GUIDE.md) · Story: [DESIGN_REPORT.md](DESIGN_REPORT.md)  
**Pin map status:** locked for next PCB rev (Aug 2026 design session) — confirm nets in KiCad match this file before coding.

P1 behaviour follows [DSMR P1 Companion Standard 5.0.2](https://www.netbeheernederland.nl/sites/default/files/2024-02/dsmr_5.0.2_p1_companion_standard.pdf): **115200 8N1**, Request-gated TX, **open-collector Data**.

**MCU:** ESP32-C3-MINI-1-H4X (stay on C3 — no S3 / dual MCU for this rev).

---

## 1. Role of this firmware

This board is the **meter**. [P1 Ghost](https://github.com/arman087/P1_ghost) is the **reader**.

| Event | Firmware must… |
|---|---|
| Ghost drives RJ12 **pin 2** Request high | Detect Request → **start** sending telegrams on Data |
| Ghost releases Request | **Stop** TX |
| Sending bits on **pin 5** | Only **pull Data low** for 0; idle/1 = high‑Z (Ghost pull-up) |
| Idle | Do not drive pin 2; do not push 5 V onto pin 5 |

Telegrams: **microSD** (primary). Wi‑Fi / USB CDC = config / OTA / UI (no LCD).

---

## 2. Locked pin / net map (ESP32-C3-MINI-1)

### 2.1 Full GPIO table

| Function | Net label | GPIO | Direction | Notes |
|---|---|---|---|---|
| USB D− | `USB_D-` | **18** | USB | Native USB flash / CDC |
| USB D+ | `USB_D+` | **19** | USB | Same |
| P1 Data TX | `ESP32_TX` | **21** | OUT (UART0 TX) | → 220 Ω → 6N137S (U8) |
| P1 Request in | `ESP32_enable` | **5** | IN | From 6N137S (U9); **active LOW** |
| RGB DIN | `Smart_RGB_LED_DIN` | **10** | OUT | WS-class LED |
| Strap | — | **2** | — | **10 kΩ to VCC_3V3** — do not use for app I/O at boot |
| Strap | — | **8** | — | **10 kΩ to VCC_3V3** — leave alone |
| BOOT / MODE | — | **9** | IN | Button to GND; pull-up. Bootloader if held at reset; **MODE** after boot |
| Chip reset | — | **EN** | — | RC + **RST** button to GND (not a GPIO) |
| SD SCK | `SD_SCK` | **0** | OUT | SPI |
| SD MOSI | `SD_MOSI` | **1** | OUT | SPI |
| SD MISO | `SD_MISO` | **3** | IN | SPI |
| SD CS | `SD_CS` | **6** | OUT | SPI (moved off GPIO4 for ADC) |
| Battery ADC | `BAT_ADC` | **4** | Analog | Divider mid-point (ADC1 only on GPIO0–4) |
| eFuse fault | `ESP32_FLT_Efuse` | **20** | IN | From 6N137S (U10) VO; **active LOW** = fault |
| Spare | — | **7** | — | Free / test pad (optional `SD_CD` later) |

### 2.2 Suggested `#define` block

```c
// USB: GPIO18 / GPIO19 (native) — no defines needed for CDC

#define PIN_P1_TX          21   // ESP32_TX → opto U8
#define PIN_P1_REQUEST     5    // ESP32_enable — active LOW
#define PIN_RGB            10

#define PIN_BOOT_MODE      9    // BOOT at reset; MODE button in app
// EN = hardware RST only

#define PIN_SD_SCK         0
#define PIN_SD_MOSI        1
#define PIN_SD_MISO        3
#define PIN_SD_CS          6

#define PIN_BAT_ADC        4    // ADC1
#define PIN_EFUSE_FLT      20   // ESP32_FLT_Efuse — active LOW

#define PIN_SPARE          7
```

### 2.3 Explicitly not used (do not soft-control)

| Idea | Why not |
|---|---|
| GPIO → main power / boost EN | Chicken-and-egg; use mechanical **BAT** switch |
| GPIO → eFuse SHDN / P1 5 V enable | Ghost needs P1 5 V always available to boot and Request |
| Soft eFuse enable | HW pull-up keeps eFuse on; chip protects itself |
| LCD / shared SPI / 2nd ESP32 | Dropped for this rev |
| SD card-detect GPIO | Optional; poll `SD.begin()` / mount instead |
| Mux of STAT1/STAT2 | LEDs on charger are enough for charge *state* |

USB CDC and UART0 are **independent** on C3: program over USB; P1 Data uses **UART0 TX (GPIO21)** only.

---

## 3. Buttons and strapping

| Button | Connection | Firmware |
|---|---|---|
| **RST** | Momentary EN → GND (+ existing RC POR) | Hardware reset only |
| **BOOT / MODE** | Momentary GPIO9 → GND (+ pull-up to 3V3) | Hold + RST → download; after boot = user MODE |

Straps at reset (must be HIGH for normal boot):

- **GPIO2**, **GPIO8**: fixed 10 kΩ pull-ups — **no switches** on these pins  
- **GPIO9**: HIGH = normal boot; LOW = download  

Do **not** hang loads that pull GPIO2/8/9 low at power-up.

---

## 4. Optocouplers — polarity (critical)

Parts: **AOTE 6N137S** (LCSC C20612601). Open-collector `VO`. Shared board GND.

### 4.1 Data out — U8 (ESP32 → RJ12 pin 5)

```
GPIO21 ── 220 Ω ── LED ── GND
VCC/EN = SYS_5V + 100 nF
VO ──► RJ12 pin 5     ← no pull-up on this PCB (Ghost pulls up)
```

| ESP32 TX | LED | pin 5 |
|---|-----|---|
| LED on | On | **LOW** (0) |
| LED off | Off | Open → Ghost pull-up HIGH |

Firmware: UART0 **115200 8N1** on GPIO21; expect **TX invert** (opto inverts). **TX only while Request active.**

### 4.2 Request in — U9 (RJ12 pin 2 → ESP32)

```
RJ12 pin2 ── 330 Ω ── LED ── GND
VO ──► ESP32_enable ── 10 kΩ to VCC_3V3 ──► GPIO5
```

| Ghost Request | `ESP32_enable` / GPIO5 |
|---|---|
| Idle | **HIGH** |
| Active | **LOW** |

**Request active = GPIO5 LOW.** Start/stop telegram stream on that.

### 4.3 eFuse FLT — U10 (TPS26625 → ESP32)

Keep eFuse `FLT` on **5 V** domain (100 kΩ pull-up to `SYS_5V`). Do **not** wire FLT directly to a GPIO.

```
SYS_5V ── 330 Ω ── 6N137 anode (pin 2)
Efuse_FLT ────────── 6N137 cathode (pin 3)   ← same net as TPS26625 FLT
6N137 VCC/EN = SYS_5V + 100 nF
VO (pin 6) ──► ESP32_FLT_Efuse ── 10 kΩ to VCC_3V3 ──► GPIO20
```

| eFuse | LED | `ESP32_FLT_Efuse` / GPIO20 |
|---|-----|---|
| OK | off | **HIGH** |
| Fault | on | **LOW** |

Firmware: fault = GPIO20 **LOW** → RGB warning / stop TX / log over USB.

---

## 5. microSD (Hirose DM3AT-SF-PEJM5)

Connector: **Card1** / DM3AT-SF-PEJM5. SPI only. Power **VCC_3V3** only.

| Card pin | Name | Net | ESP32 |
|---|---|-----|---|
| 1 | DAT2 | NC (or 10 kΩ to 3V3) | — |
| 2 | CD/DAT3 | `SD_CS` | GPIO6 |
| 3 | CMD | `SD_MOSI` | GPIO1 |
| 4 | VDD | `VCC_3V3` + 10 µF + 100 nF | — |
| 5 | CLK | `SD_SCK` | GPIO0 |
| 6 | VSS | GND | — |
| 7 | DAT0 | `SD_MISO` | GPIO3 |
| 8 | DAT1 | NC (or 10 kΩ to 3V3) | — |
| 9 | SW_B | GND or NC | — |
| 10–14 | shell / SW_A | GND; SW_A unused (no `SD_CD`) | — |

Optional 33–47 Ω series on SCK/MOSI/MISO/CS. Keep away from antenna keep-out.

Firmware:

```c
SPI.begin(PIN_SD_SCK, PIN_SD_MISO, PIN_SD_MOSI, PIN_SD_CS);
SD.begin(PIN_SD_CS);
// FatFS path e.g. /telegrams/*.txt
```

No card-detect GPIO: mount at boot / on demand; fail → RGB / USB message. Hot-plug not required for v1.

---

## 6. Battery voltage (`BAT_ADC`)

**Purpose:** approximate SoC / “charge me” on RGB. Not a fuel gauge.  
STAT1/STAT2 LEDs on bq25185 already show charge *state* — do not mux them into the MCU.

### 6.1 Circuit (place divider next to ESP32)

Sense **after** mechanical BAT power switch (no drain when BAT OFF):

```
Battery(+) ──[SW_BAT]── BAT_SENSE ──► bq25185 BAT
                              │
                              └── 100 kΩ (1%) ──●── BAT_ADC ──► GPIO4
                                                 │
                                                 ├── 100 kΩ (1%) ── GND
                                                 └── 100 nF ────── GND
```

Equal **100 kΩ / 100 kΩ** → \(V_{ADC} = V_{BAT}/2\) → 4.2 V → **2.1 V**.  
**1%** resistors are enough (ADC error dominates; 0.1% not needed).  
Cap is **in parallel with the bottom resistor**, at the ADC pin.

### 6.2 Firmware hints

- Use **ADC1** on GPIO4.  
- Low threshold example: Vbat ≲ 3.5 V → \(V_{ADC}\) ≲ 1.75 V → blink RGB “charge me”.  
- Calibrate once against a DMM if you want better %.

---

## 7. Mechanical power switches (not GPIOs)

| Switch | Net path | Part class |
|---|---|---|
| **SW_BAT** | Cell + → switch → bq25185 **BAT** | Metal mini toggle e.g. ST-0-102 / Dailywell 3 A |
| **SW_USB** | USB-C VBUS → `5V_usb` → switch → `5V_usb_1` → bq25185 **IN** | Same |

Example USB wiring: COM/throw between `5V_usb` and `5V_usb_1`; frame/support pin → **GND**. Do not switch CC or USB D+/D−.

Do **not** use MSK12C02 (50 mA ISET switch) on these paths.

---

## 8. RJ12 meter-side map

| Pin | Net | Firmware |
|-----|-----|---|
| 1 | `P1_5V` | After TPS26625 — no GPIO |
| 2 | `RJ12_pin2` | Request → U9 → GPIO5 |
| 3 | GND | — |
| 4 | NC | — |
| 5 | `RJ12_Tx_pin5` | Data ← U8 ← GPIO21 |
| 6 | GND | — |

---

## 9. Power / eFuse notes

| Rail | Use |
|---|-----|
| `SYS_5V` | Boost 5 V; SY8088, opto VCC, RGB path |
| `VCC_3V3` | ESP32, SD, logic pull-ups, `ESP32_FLT_Efuse` pull-up |
| `P1_5V` | TPS26625 out → RJ12 pin 1 (~250 mA) |

- TPS26625 **SHDN**: hardware enabled (e.g. 100 kΩ to 5 V) — **no MCU pin**.  
- FLT → opto → GPIO20 only (see §4.3).  
- SY8088AAC (~1 A) is enough for C3 + SD + Wi‑Fi for this design.

---

## 10. Suggested bring-up order

1. USB CDC hello (GPIO18/19).  
2. RST + BOOT (GPIO9) work; normal boot with GPIO9 released.  
3. RGB on GPIO10.  
4. GPIO5 Request: active LOW with Ghost or bench 5 V on pin 2.  
5. UART0 TX GPIO21 + invert; gate on Request.  
6. `ESP32_FLT_Efuse` GPIO20 (force fault / overload test).  
7. SD mount + list `/telegrams`.  
8. `BAT_ADC` vs DMM; low-batt RGB.  
9. MODE on GPIO9 (short/long) + Wi‑Fi config UI.

### Quick test without Ghost

- Request: drive RJ12 pin 2 into the opto LED path → GPIO5 LOW.  
- Data: optional bench **4.7 kΩ** pin 5 to `P1_5V`; remove for normal Ghost use.

---

## 11. Checklist for the firmware author

- [ ] Flash via USB (GPIO18/19); BOOT+RST for recovery.  
- [ ] P1 UART **GPIO21**, 115200 8N1, invert as needed.  
- [ ] Request **GPIO5**, active LOW; TX only while LOW.  
- [ ] SD SPI 0/1/3/6; FatFS telegrams.  
- [ ] FLT **GPIO20**, active LOW.  
- [ ] BAT ADC **GPIO4**; low-batt indication.  
- [ ] GPIO9 = MODE in app; never leave low at reset unintentionally.  
- [ ] Never drive GPIO2/8 against strap pull-ups at boot.  
- [ ] No 5 V into any ESP32 GPIO.  
- [ ] No software enable of P1 eFuse or main power.

---

## 12. Related circuit notes

| Topic | File |
|---|---|
| Request sense | [circuits/07_data_request_sense/NOTES.txt](circuits/07_data_request_sense/NOTES.txt) |
| Data OC / opto | [circuits/08_open_collector_data/NOTES.txt](circuits/08_open_collector_data/NOTES.txt) |
| ESP32 | [circuits/05_esp32_c3_mini/NOTES.txt](circuits/05_esp32_c3_mini/NOTES.txt) |
| P1 eFuse | [circuits/04_p1_5v_current_limit/NOTES.txt](circuits/04_p1_5v_current_limit/NOTES.txt) |
| microSD | [circuits/12_microsd/NOTES.txt](circuits/12_microsd/NOTES.txt) |
| Parts | [PARTS_CHECKLIST.md](PARTS_CHECKLIST.md) |

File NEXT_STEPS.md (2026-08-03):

# Next steps (paused Aug 2026)

ESP32-C3 design path is largely locked in docs + KiCad. Come back here when continuing.

---

## Do first (stay on ESP32)

1. Finish PCB routing / DRC in `my_design/Slimme_meter_Sim/`.
2. Lock `ESP32_enable` (Request sense) to a specific GPIO in schematic + [FIRMWARE_GUIDE.md](FIRMWARE_GUIDE.md).
3. Order PCB **with stencil** (JLCPCB or similar).
4. Assemble ~1 board:
   - **Hot air + stencil** for the five ICs (bq25185, TPS61023, TPS26625, SY8088, ESP32-C3 module / QFN-class parts + optos as needed).
   - Iron for connectors, RJ12, through-hole / larger parts.
5. Optional DIY ease: upsize passives **0402 → 0603 / 0805 / 1206** before the next fab spin (not required if stencil + paste are good).
6. Bring-up: USB charge → SYS_5V → 3V3 → UART telegrams on Request → Ghost on RJ12 @ ~250 mA P1 limit.
7. Later: microSD telegrams, ESD polish, Wi‑Fi config/OTA.

**Assembly note:** Stencil + paste + hot air is the realistic path for the power ICs. Full hand-iron on every fine-pitch pad is painful; one focused day with paste and airflow is enough for a first board.

---

## Parked idea: Raspberry Pi as the “brain”

Not replacing the P1 power test bed — only the MCU / software side if ESP32 firmware + SD feel too heavy.

### Architecture (two power domains)

| Side | Power | Role |
|---|---|---|
| **This board** | Battery/USB → **bq25185** → **TPS61023** → **TPS26625** → RJ12 | Real **P1 5 V @ ~250 mA** so Ghost + charger/boost path can be tested |
| **Raspberry Pi 4 or 5** | Own wall PSU **or** Pi UPS HAT (battery) | Runs easy software (Python); drives Request / Data GPIO |

- BQ / boost / eFuse stay. They are **not** for the Pi.
- Pi is **not** fed from `VCC_3V3` or the small boost.
- Connect only **signals + shared GND** (headers / cable): GPIO → Data TX opto LED; Request opto → GPIO.
- Opto VCC still from board **SYS_5V**.
- On a Pi-only spin you can drop ESP32 + possibly SY8088; keep P1 power path.

### Pi battery (EU shops)

Pi itself has no built-in battery. Buy Pi + UPS HAT, e.g.:

- [Kubii — SunFounder PiPower 5](https://www.kubii.com/en/poe-hat-tarjetas-de-expansion/5160-pipower-5-hats-for-raspberry-pi-3272496326866.html) (FR/EU)
- Amazon.nl / Amazon.de — Geekworm X120x UPS for Pi 5
- Kiwi Electronics (NL), BerryBase (DE), Nettigo (PL)

That UPS powers **only the Pi**. Board battery path stays for P1 / Ghost tests.

### When to use this idea

- Lab / desk: want Python + large telegram files, less C++ pain.
- Portable field Ghost range test: prefer **ESP32** on this board (Pi is bulkier and its UPS is a second power system).

Decision later — ESP32 remains the default locked design until explicitly changed.

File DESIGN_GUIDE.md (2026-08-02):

# Smart Meter Simulator — Architecture & Design Guide

**Goal:** Portable **DSMR P1 meter-side** board so you can develop and field-test **P1 Ghost** (Wi‑Fi range, etc.) without asking to use real doorstep meters.

**MCU:** ESP32-C3-MINI-1 (Wi‑Fi **on** for config / OTA / talk-to-device)  
**Power (on main PCB):** **bq25185** (charge + `VSYS`/`V+`) + **TPS61023** (`V+` → **+5 V**) + **on-board 5→3.3 V** (≥500 mA)  
**P1 +5 V:** TI **TPS2662** foldback  
**Store:** **microSD** telegram files  
**Connector:** RJ12 6P6C female (meter side)  
**Signals:** Optocouplers on Request + Data; optional isolated DC-DC for true floating P1  
**Volume:** ~5 boards  
**Skip:** LoRa · feeding RJ12 from `V+` without the boost  

Part picking: **[PARTS_CHECKLIST.md](PARTS_CHECKLIST.md)**  
Design story: **[DESIGN_REPORT.md](DESIGN_REPORT.md)**  
KiCad: `my_design/Slimme_meter_Sim/`

---

## 1. What this board is (and is not)

| Role | Device | RJ12 side |
|---|---|---|
| **This project (Simulator)** | Acts as the **meter** | Female jack, **supplies** +5V, **senses** Data Request, **drives** Data (OC / opto) |
| P1 Ghost / OSM | Acts as the **reader** | Male plug, **takes** +5V, **drives** Data Request high, **reads** Data |

**Field use:** battery + simulator in a building corner → Ghost on RJ12 → you elsewhere checking **Ghost** Wi‑Fi. Simulator replays telegrams from **microSD**.

```
microSD telegrams ──► ESP32-C3 ──► opto / OC UART ──► RJ12 pin5 (Data)
                         ▲                               │
                    Request ◄── opto ◄── RJ12 pin2 ◄── Ghost
                         │
              SYS_5V ── TPS2662 ──► RJ12 pin1 ──► powers Ghost
```

---

## 2. Architecture (locked)

```
┌──────────────────────────────────────────────────────────────────────────┐
│                     SMART METER SIMULATOR PCB (one board)                │
│                                                                          │
│  USB-C ──► bq25185 ──► VSYS/V+ (3.0–4.5 V) ──► TPS61023 ──► SYS_5V     │
│                 │                              │                         │
│              LiPo JST           ┌──────────────┴──────────────┐          │
│                                 ▼                             ▼          │
│                          5V→3.3V (≥500 mA)              TPS2662          │
│                                 ▼                             ▼          │
│                            VCC_3V3 ── ESP32              P1_5V → RJ12    │
│                                   + microSD ± OLED                       │
│                                                                          │
│  Board USB-C (D+/D−) ─────────────────────────────► ESP32 flash         │
│  RJ12 pin2 ──► Request opto ──► GPIO                                     │
│  ESP32 TX ──► Data opto / OC ──► RJ12 pin5                               │
└──────────────────────────────────────────────────────────────────────────┘
```

### Block checklist

| # | Block | Verdict |
|---|---|---|
| 1 | Board USB-C (D+/D− flash) | **Required** |
| 2 | ESP32-C3-MINI-1 + EN / caps | **Required** |
| 3 | **bq25185** charge + power path | **Required** |
| 4 | **TPS61023** `V+` → `SYS_5V` | **Required** — do **not** omit |
| 5 | On-board **5V→3.3V** (≥500 mA) | **Required** |
| 6 | **TPS2662** SYS_5V→P1_5V | **Required** — DSMR foldback |
| 7 | RJ12 6P6C | **Required** |
| 8 | Request + Data optos | **Required** |
| 9 | microSD | **Required** |
| 10 | ESD USB + RJ12 | **Required** |
| 11 | LED + button | **Recommended** |
| 12 | OLED | **Optional** |
| 13 | Isolated 5V DC-DC | **Optional** — true floating P1 |
| 14 | LoRa | **Skip** |
| 15 | Skip TPS61023 / use `V+` as P1 5 V | **Skip — wrong** |

---

## 3. Important rules

### 3.1 What `VSYS` / `V+` is (bq25185 pin 1)

Charger **VSYS** (schematic net `V+`) is **not** a 5 V rail.

| Condition | Typical voltage |
|---|---|
| USB / DC in | ~**4.5 V** regulated |
| Battery only | ~**3.0–4.2 V** (follows cell) |

**TPS61023** boosts `V+` → fixed **+5 V** (`SYS_5V`). Keep it so:

- RJ12 / Ghost always see real ~5 V on battery  
- Your 5→3.3 regulator always has headroom (LDO from a 3.2 V cell cannot make 3.3 V)

### 3.2 Power budgets

| Rail | Source | Budget |
|---|---|---|
| `V+` / VSYS | bq25185 | Intermediate only |
| `SYS_5V` | TPS61023 | ~**1 A** class IC; board load ≪ that |
| `P1_5V` | TPS2662 | ~**250 mA** continuous, foldback on fault |
| `VCC_3V3` | On-board regulator from `SYS_5V` | **≥500 mA** |

### 3.3 P1 +5V foldback

DSMR: ~250 mA continuous, overload ~260–300 mA, then **foldback**.  
**TPS2662** — [slvaf94](https://www.ti.com/lit/pdf/slvaf94).

### 3.4 Data Request / Data

- Pin 2 HIGH (~5 V) → start TX; release high‑Z to stop  
- Pin 5 open-collector / opto; 115200 8N1; use **fast** optos (not PC817)

### 3.5 Isolation

Optos in scope. True floating P1 needs isolated 5 V DC-DC + `GND_ISO`.

### 3.6 Storage & Wi‑Fi

| Path | Role |
|---|---|
| **microSD** | Primary telegram library |
| **Wi‑Fi** | Config / OTA — not primary telegram pipe |
| **USB-C** | First flash + serial |

---

## 4. RJ12 pin map (meter / simulator)

| Pin | Name | Simulator must… |
|-----|---|---|
| 1 | +5V | **Source** 5 V via TPS2662 |
| 2 | Data Request | **Sense** HIGH → enable TX |
| 3 | Data GND | System GND or `GND_ISO` |
| 4 | NC | Leave open |
| 5 | Data | **OC / opto** UART from MCU TX |
| 6 | Power GND | Same as pin 3 |

---

## 5. Reference circuit patterns

### 5.1 Power (main PCB)

```
USB-C ──► bq25185 ──► V+ / VSYS
              │            │
           VBAT/LiPo       └──► TPS61023 ──► SYS_5V
                                              ├─► 5→3.3 ──► VCC_3V3
                                              └─► TPS2662 ──► P1_5V ──► RJ12 pin1
```

Keep **both** charger and boost. Omit unused solar / DC terminal pads if not needed.

### 5.2–5.5

Request opto, Data opto OC, USB-C data (GPIO18/19), microSD SPI — see circuit NOTES and earlier patterns in `circuits/`.

---

## 6. ESP32-C3 pin assignment (locked for firmware)

Full detail: **[FIRMWARE_GUIDE.md](FIRMWARE_GUIDE.md)**

| GPIO / pin | Net | Function |
|---|-----|---|
| 18 / 19 | `USB_D-` / `USB_D+` | Native USB flash / CDC |
| **21 (`TXD0`)** | `ESP32_TX` | P1 Data TX → 6N137S (U8) → RJ12 pin 5 |
| (free input) | `ESP32_enable` | P1 Request from U9 — **active LOW** |
| 10 | `Smart_RGB_LED_DIN` | RGB LED data |
| 2 / 8 | — | Strapping; PCB pull-ups |
| 20 (`RXD0`) | — | Unused for P1 |

**Reminders:** Request LOW = start TX; UART may need **invert**; never 5 V on GPIO; no pull-up on pin 5 on this PCB.

---

## 7. KiCad order

| Step | Subcircuit | Done when… |
|---|---|---|
| 1 | Nets + bq25185 + TPS61023 (`02`) | `V+`, `SYS_5V`, charge, battery — **in progress in Slimme_meter_Sim** |
| 2 | 5→3.3 (`03`) | `VCC_3V3` stable under Wi‑Fi |
| 3 | Board USB-C (`01`) | Flash blink |
| 4 | ESP32 (`05`) | CDC + Wi‑Fi smoke |
| 5 | microSD (`12`) | Read telegram file |
| 6 | TPS2662 (`04`) | P1_5V; short → foldback |
| 7 | RJ12 + optos (`06`/`11`/`07`/`08`) | Ghost gets valid telegram |
| 8 | ESD + UI (`09`/`10`) | Bring-up checklist green |

---

## 8. Bring-up checklist

1. Charge USB → battery charges; `V+` present  
2. `SYS_5V` ≈ 5 V (boost on); battery-only still ≈ 5 V  
3. `VCC_3V3` ≈ 3.3 V; Wi‑Fi without brown-out  
4. Flash via board USB; SD lists files  
5. `P1_5V` ≈ 5 V; short → foldback, recovers  
6. Request → TX; Ghost receives telegram  

---

## 9. Relation to P1 Ghost

| Signal | Ghost | Simulator |
|---|---|---|
| Pin 1 +5V | Input | **Output** (TPS2662) |
| Pin 2 Request | Drives HIGH | **Sense** via opto |
| Pin 5 Data | UART RX path | **OC / opto** from TX |

---

## References

1. [DSMR P1 Companion Standard 5.0.2](https://www.netbeheernederland.nl/sites/default/files/2024-02/dsmr_5.0.2_p1_companion_standard.pdf)  
2. [TI slvaf94 — TPS2662](https://www.ti.com/lit/pdf/slvaf94)  
3. [TI bq25185](https://www.ti.com/product/BQ25185) · [TI TPS61023](https://www.ti.com/product/TPS61023)  
4. [PARTS_CHECKLIST.md](PARTS_CHECKLIST.md) · [DESIGN_REPORT.md](DESIGN_REPORT.md)  
5. [arman087/P1_ghost](https://github.com/arman087/P1_ghost)

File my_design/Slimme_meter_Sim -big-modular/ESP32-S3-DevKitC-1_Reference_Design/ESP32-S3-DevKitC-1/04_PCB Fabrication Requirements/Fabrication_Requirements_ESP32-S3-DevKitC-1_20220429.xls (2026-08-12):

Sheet: PCB Fabrication Requirements
PCB加工工艺要求说明书 PCB Fabrication Requirements |  |  |  |  |  |  |  |  |  |  | I. 板料及叠层可参考如下，板材 FR-4 TG150 无卤。PP 型号如有更换，请邮件通知。防止波纹布显露，选用的 PP 材料的 RC 含量不要低于50%。 Material and Stackup follow the design.FR-4 TG150 Halogen Free, If the PP model is changed, please inform us via email.To avoid texure condition,the resin content of PP material 7628 should not be lower than 50%.
文件名： File Name: |  | PCB_ESP32-S3-DevKitC-1_V1.1_20220429.pcb |  | 版本号： Version: |  | V1.1 | 物料名称： Material: | PCB |  |  | 层数 | 材质 | 钻孔结构 | 基铜厚度(OZ） | 各层厚度(mil)
PCB 加工要求： PCB Processing Requirements:
 |  |  |  |  |  |  |  |  |  |  | CM |  |  |  | 0.4 | 4 | 线宽/线距-距铜
 |  |  |  |  |  |  | 附图 Attachment |  |  |  | L1 | 基铜 |  | 0.33 | 1.18min |  | 9.4/5.6-5.8
 | 1.数 量： Order Quantity： |  | TBD | 块 PCS |  |  | 12.交货日期： Delivery Date:
 | 2.层 数： Number of Layers: |  |  |  |  |  |  |  |  |  |  | 芯板 |  |  | 57.9 | 4.47
 | 3.尺 寸： Dimension： |  | 62.74 |  | mm | 25.4 | mm |  | 详见 Gerber 文件尺寸 Refer to the Gerber file
 | 4.板 厚： Board Thickness： |  |  |  |  |  |  |  |  |  | L2 | 基铜 |  | 0.33 | 1.18min
 | 5.材 料： Material Type： |  |  |  | 其他材料： Other Material： |  |  |  |  |  |  |  |  |  |  | 3.6
 | 6.铜箔厚度： Copper Thickness： |  | 内层 Inner-Layer |  | 外层 Outer-Layer |  | 13.表面涂层： Surface Finishing： |  |  |  | SM |  |  |  | 0.4 | 4
 | 7.阻 焊： Solder Mask: |  |  |  | 颜 色： Color: | 油墨色号见颜色图表 | 14.加工厂商标记： Manufacturer's Marking： |  |  |  | 成品板厚：1.60+/-0.16mm
 | 8.字 符： Silkscreen: |  |  |  | 颜 色： Color: |  | UL 标记 UL Marking
 | 9.过孔处理方式： Through hole processing： |  |  |  |  |  | 制作日期 Manufature Date |  |  |  | II. 下图所示高亮走线需做 90 欧姆阻抗管控。叠层结构可参考右侧所示模型：
 | 10.测 试： Test：
 | 11.设计软件及其版本： Software Version:
 | 15.交货方式： Delivery Type： |  |  | 1 | 单元/片 Unit/PCS | 拼板交货允许报废 Panelization allows scrap |  |  |  | PCS/SET
 | 16.其 他： Others:
 | 17.层次排列： Layer Sequence： |  | L1_TOP, L2_BOTTOM
 | 说明(Notes)：
 | 1.两面盖油的双面塞孔，单面开窗的半塞孔，双面开窗的过孔在芯片背面塞孔。 Double-sided plug hole with oil cover on both sides, half-plug hole with open window on one side，non-plug hole with double-side window.
 | 2.如存在金手指或是 socket，需要进行镀硬金处理。并注意焊接时焊盘不可沾锡。 If there exists gold finger or socket, hard gold plating is needed. Besides, soldering tin should be avoided on the pad.
 | 其他特殊说明：按照 PCB 文件加工，并请注意按照上面的技术要求。
 | Other special specification: please fabricate based on the PCB file and pay attention to the above technical requirements.
 | EQ表 是常见问题总结，可以参考，加工工艺要求如下:
 | A. 沉金厚：金厚：半孔板 min 0.03um，非半孔板 min 0.0254um；镍厚按 min 2.54 um；
 | 测试沉金厚度面积为 2 - 10 平方 mm 的区域，连续测 10 次的平均值！
 | B. PTH 孔：±0.075 mm ；NPTH 孔：±0.05 mm；PTH 槽孔 ±5 mil；
 | C. 孔铜:通孔：15 um (min)；
 | D. 外形公差：±0.10 mm；
 | E. 板曲：≤ 0.75%；
 | F. 板厚公差：1 mm 以下公差： ±0.1 mm ； 1 mm 及以上公差： ±10%；
 | G. 阻焊油墨：10 - 40 um；
 | H. BGA & SMD：公差：±20%； 线宽 ＜ 4 mil 公差: ±1 mil, ≥ 4mil 公差：±20%；
 | I. 孔到边公差：±0.1 mm，孔到孔公差：±0.075 mm；
 | J. 内直角及小于 R 0.5 mm 的内角按 R 0.5 mm 制作；
 | K. 其他标准，按照 IPC-A-600 CLASS II 执行。 |  |  |  |  |  |  |  |  |  | III. Date Code 请填写在方框内，格式为 YYWW. Please fill in the data code in the box in the format of YYWW.

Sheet: Color
乐鑫产品PCB 颜色标准
Model | ESP-WROOM-02，ESP-WROOM-02D，ESP-WROOM-02U等ESP8266EX 系列 | ESP-WROOM-32，ESP32-WROVER，ESP32-WROOM-32U，ESP32-WROOM-32D，ESP32-PICO-KIT，ESP32-DevKitC，ESP32_LyraT，ESP-WROVER-KIT等ESP32系列
颜色 | PMS287 PMS288 PMS294 PMS295 PMS2945 PMS2955 | （哑光黑色）Black/PMS412/PMS419/PMS426/PMS433
色卡对照区域

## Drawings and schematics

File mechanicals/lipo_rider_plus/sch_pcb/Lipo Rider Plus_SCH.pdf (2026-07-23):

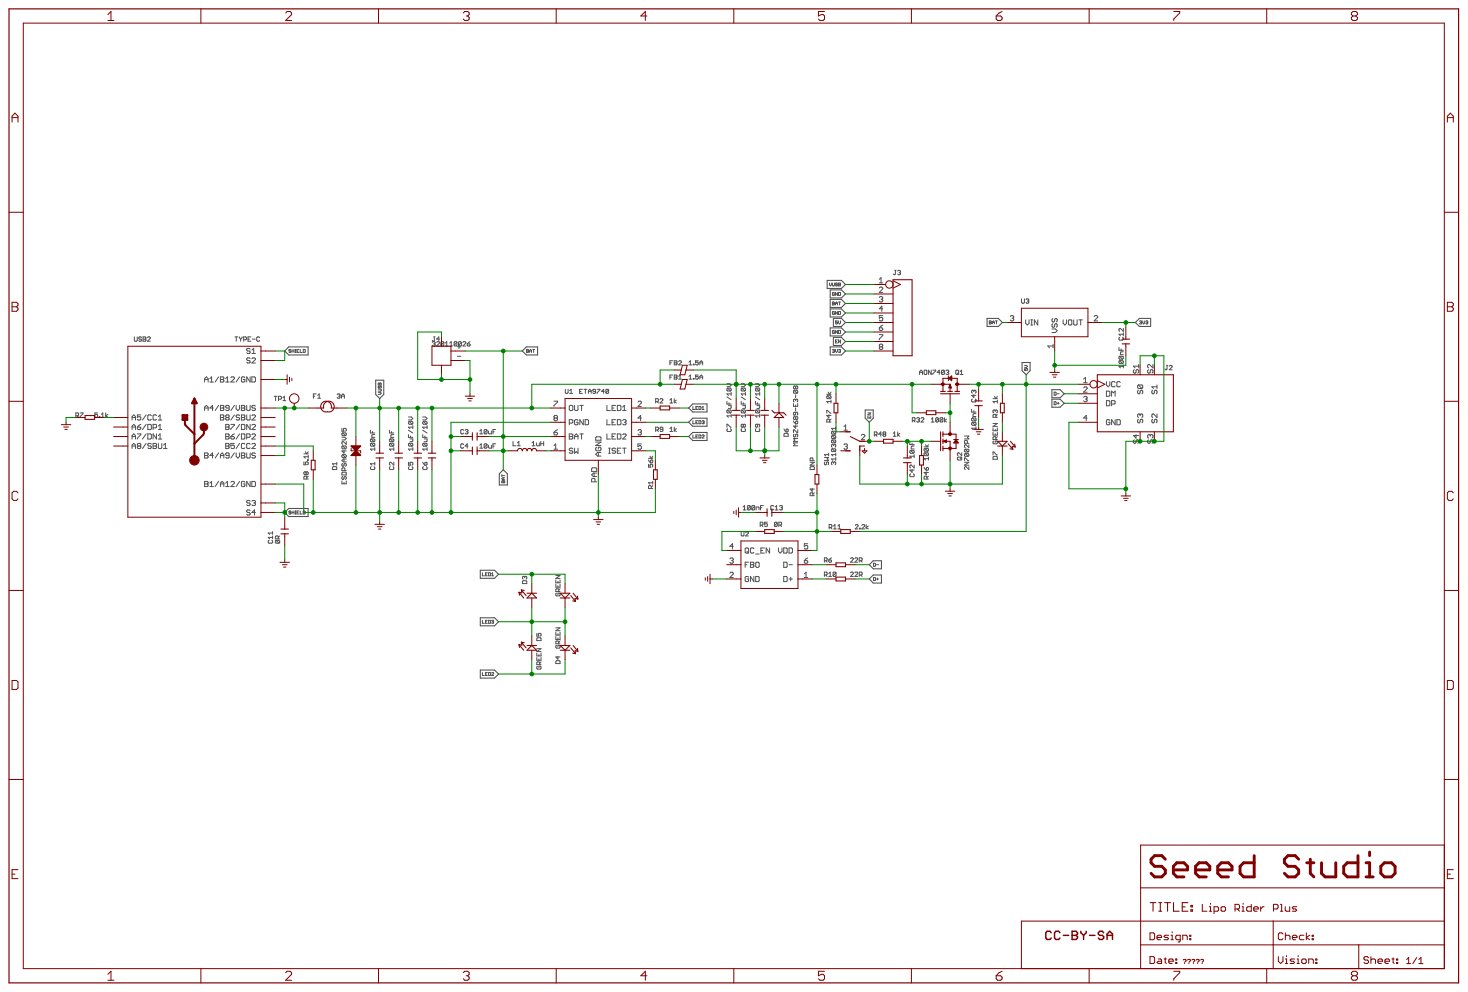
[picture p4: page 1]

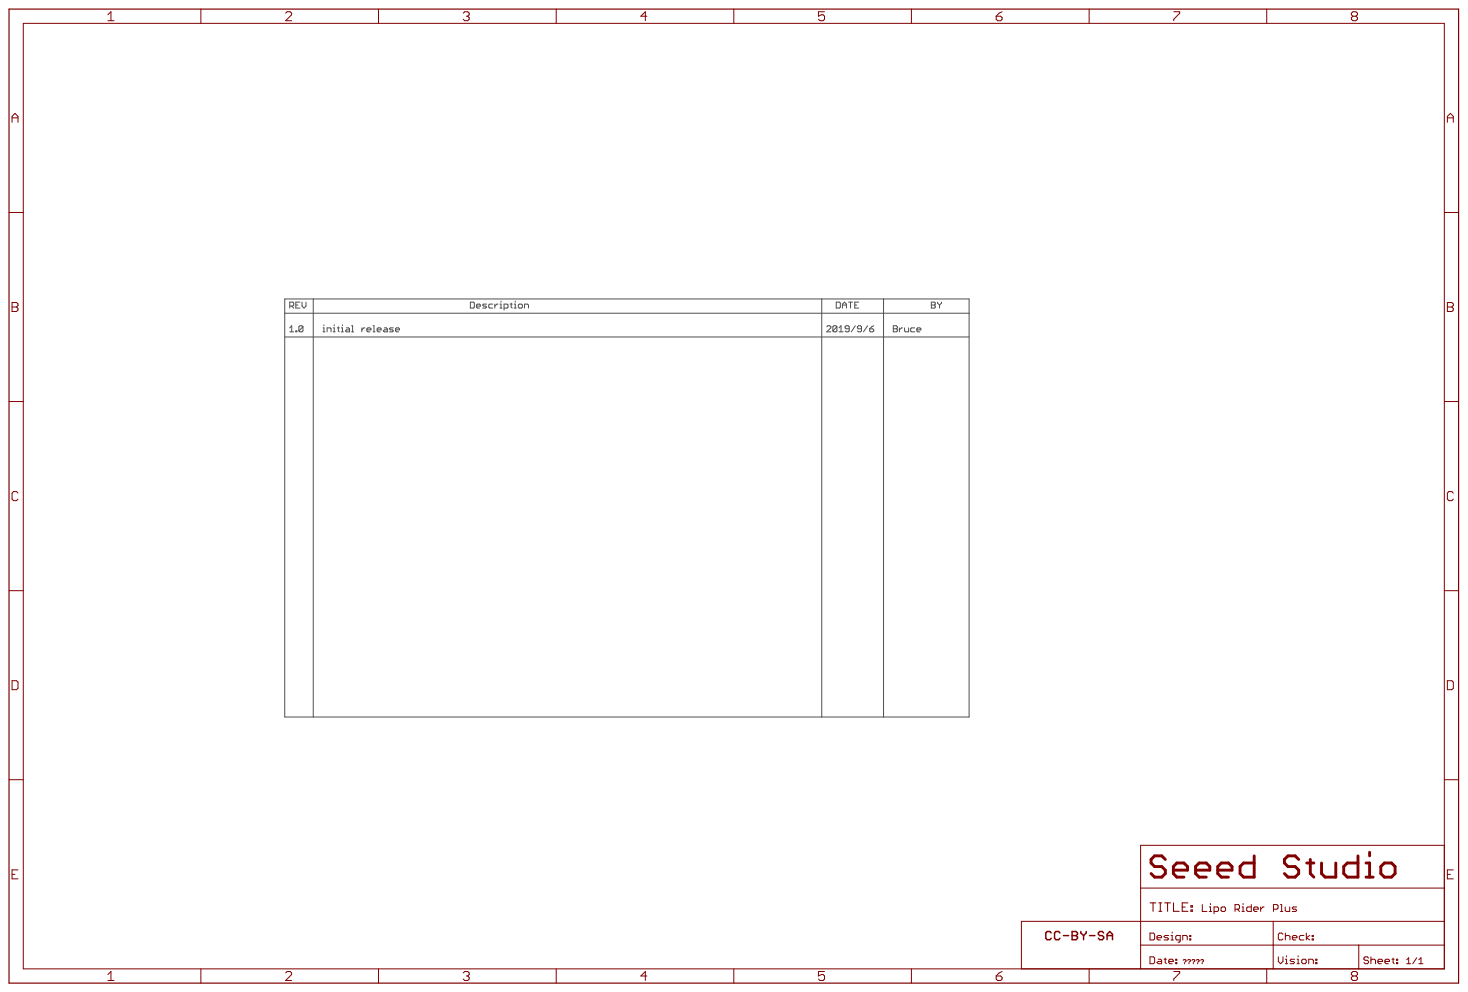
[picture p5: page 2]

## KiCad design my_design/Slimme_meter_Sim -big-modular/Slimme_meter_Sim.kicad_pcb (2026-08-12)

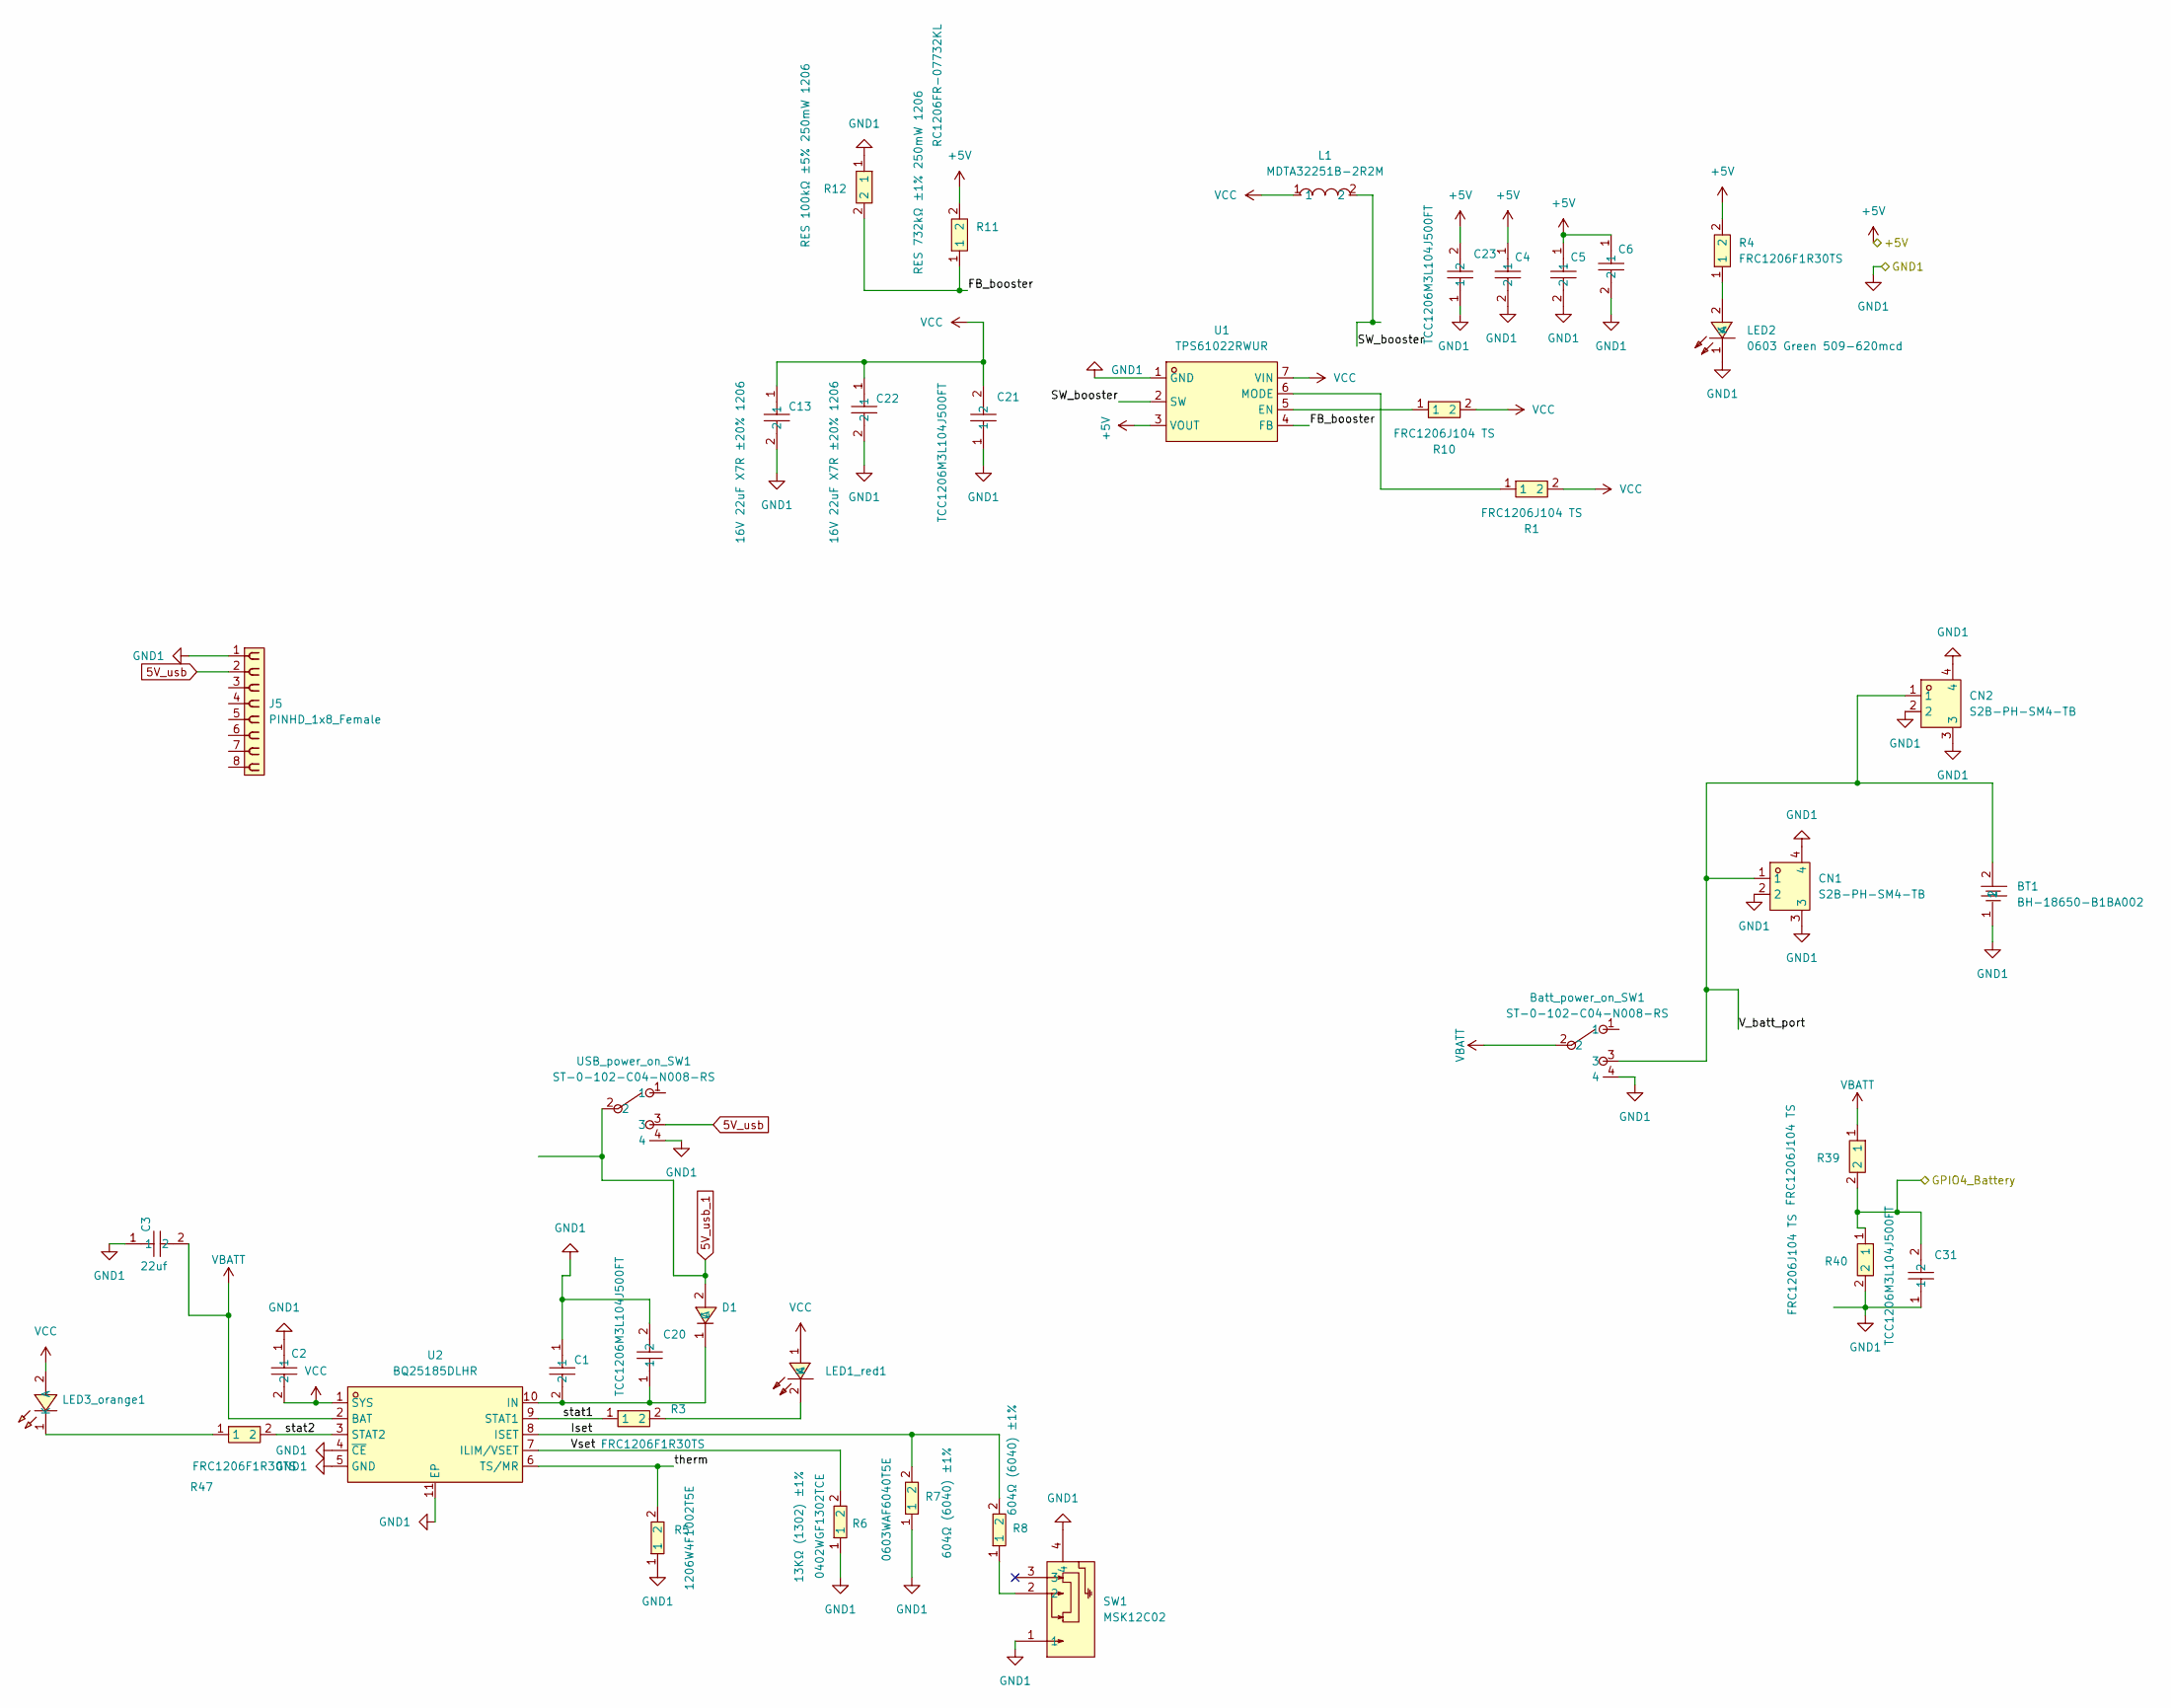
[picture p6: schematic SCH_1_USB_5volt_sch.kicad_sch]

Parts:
BT1: BH-18650-B1BA002; BATTERY-SMD_18650-1S-L77.1-W20.7-1; MPN BH-18650-B1BA002; LCSC Part C2988620
Batt_power_on_SW1: ST-0-102-C04-N008-RS; SW-TH_ST-0-102-C04-N008-RS; MPN ST-0-102-C04-N008-RS; LCSC Part C1788491
C1, C2, C3, C4, C5, C6, C13, C22: FS31X226M160EPG; C1206; MPN FS31X226M160EPG; LCSC Part C3036083
C20, C21, C23, C31: TCC1206M3L104J500FT; C1206; MPN TCC1206M3L104J500FT; LCSC Part C359189
CN1, CN2: S2B-PH-SM4-TB; CONN-SMD_P2.00_S2B-PH-SM4-TB-LF-SN; MPN S2B-PH-SM4-TB(LF)(SN); LCSC Part C295747
D1: NSR0320MW2T1G; SOD-323_L1.8-W1.3-LS2.5-RD; MPN NSR0320MW2T1G; LCSC Part C48192
J5: PINHD_1x8_Female; PinSocket_1x08_P2.54mm_Vertical
L1: MDTA32251B-2R2M; IND-SMD_L3.2-W2.5-BRL3225T100M; MPN MDTA32251B-2R2M; LCSC Part C22388372
LED1_red1: KT-0603R; LED-SMD_L1.6-W0.8-R-RD; MPN KT-0603R; LCSC Part C2286
LED2: 0603 Green 509-620mcd; LED0603-RD; MPN KT-0603G; LCSC Part C12624
LED3_orange1: KT-0603O; LED0603-RD; MPN KT-0603O; LCSC Part C111340
R1, R10, R12, R39, R40: FRC1206J104 TS; R1206; MPN FRC1206J104 TS; LCSC Part C2907421
R3, R4, R47: FRC1206F1R30TS; R1206; MPN FRC1206F1R30TS; LCSC Part C2907365
R5: 1206W4F1002T5E; R1206; MPN 1206W4F1002T5E; LCSC Part C17902
R6: 0402WGF1302TCE; R0402; MPN 0402WGF1302TCE; LCSC Part C25754
R7, R8: 0603WAF6040T5E; R0603; MPN 0603WAF6040T5E; LCSC Part C32183
R11: RC1206FR-07732KL; R1206; MPN RC1206FR-07732KL; LCSC Part C488960
SW1: MSK12C02; SW-TH_MSK12C02; MPN MSK12C02; LCSC Part C431540
U1: TPS61022RWUR; VQFN-7_L2.0-W2.0-P0.55-TL_RWU; MPN TPS61022RWUR; LCSC Part C915088
U2: BQ25185DLHR; WSON-10_L2.2-W2.0-P0.40-BL-EP_TI_DLH0010A; MPN BQ25185DLHR; LCSC Part C19725033
USB_power_on_SW1: ST-0-102-C04-N008-RS; SW-TH_ST-0-102-C04-N008-RS; MPN ST-0-102-C04-N008-RS; LCSC Part C1788491

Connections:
5V_usb: J5.2, USB_power_on_SW1.3
5V_usb_1: D1.2 (A), USB_power_on_SW1.2
+5V: C4.1, C5.1, C6.1, C23.2, R4.2, R11.2, U1.3 (VOUT); also elsewhere on the board
/SCH_1_USB_5volt/GPIO4_Battery: C31.2, R39.2, R40.1; also elsewhere on the board
/SCH_1_USB_5volt/Iset: R7.2, R8.2, U2.8 (ISET)
/SCH_1_USB_5volt/V_batt_port: BT1.2, Batt_power_on_SW1.3, CN1.1, CN2.1
/SCH_1_USB_5volt/Vset: R6.2, U2.7 (ILIM/VSET)
/SCH_1_USB_5volt/stat1: R3.1, U2.9 (STAT1)
/SCH_1_USB_5volt/stat2: R47.2, U2.3 (STAT2)
/SCH_1_USB_5volt/therm: R5.2, U2.6 (TS/MR)
GND: BT1.1, Batt_power_on_SW1.4, C1.1, C2.1, C3.1, C4.2, C5.2, C6.2, C13.2, C20.2, C21.1, C22.2, C23.1, C31.1, CN1.2, CN1.3, CN1.4, CN2.2, CN2.3, CN2.4, J5.1, LED2.1 (K), R5.1, R6.1, R7.1, R12.1, R40.2, SW1.1, SW1.4, U1.1 (GND), U2.4 (~CE), U2.5 (GND), U2.11 (EP), USB_power_on_SW1.4; also elsewhere on the board
unnamed: C1.2, C20.1, D1.1 (C), U2.10 (IN)
unnamed: LED1_red1.2 (K), R3.2
unnamed: LED2.2 (A), R4.1
unnamed: LED3_orange1.1 (K), R47.1
unnamed: R1.1, U1.6 (MODE)
unnamed: R8.1, SW1.2
unnamed 34: R10.1, U1.5 (EN); also elsewhere on the board
unnamed 35: R11.1, R12.2, U1.4 (FB); also elsewhere on the board
unnamed 36: L1.2, U1.2 (SW); also elsewhere on the board
VBATT: Batt_power_on_SW1.2, C3.2, R39.1, U2.2 (BAT)
VCC: C2.2, C13.1, C21.2, C22.1, L1.1, LED1_red1.1 (A), LED3_orange1.2 (A), R1.2, R10.2, U1.7 (VIN), U2.1 (SYS); also elsewhere on the board

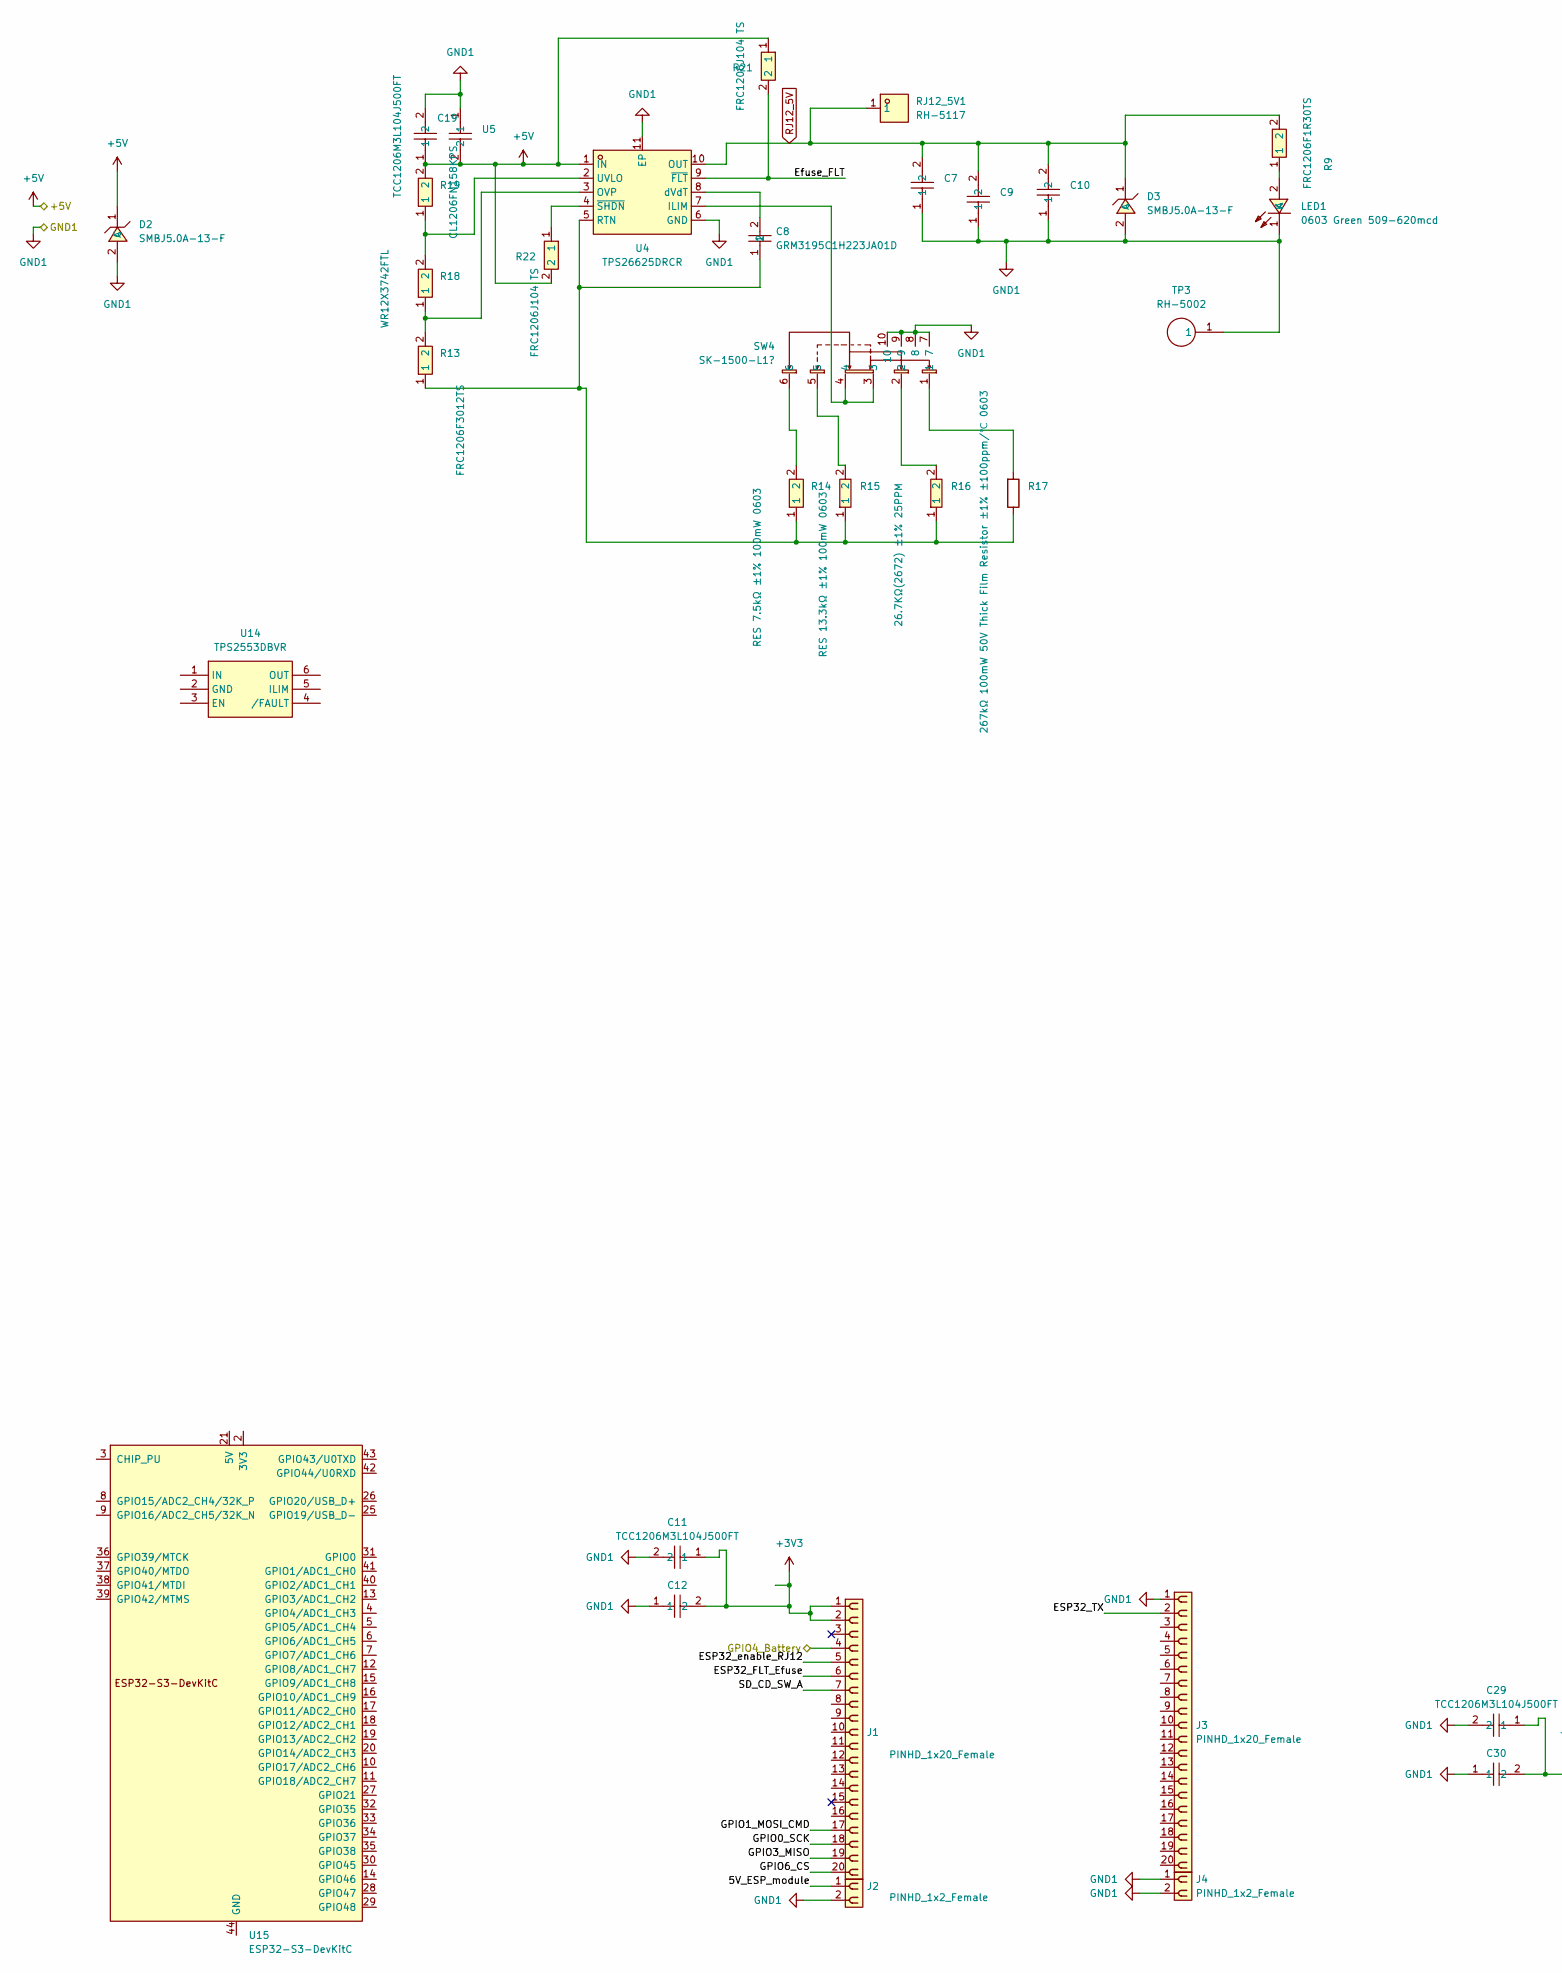
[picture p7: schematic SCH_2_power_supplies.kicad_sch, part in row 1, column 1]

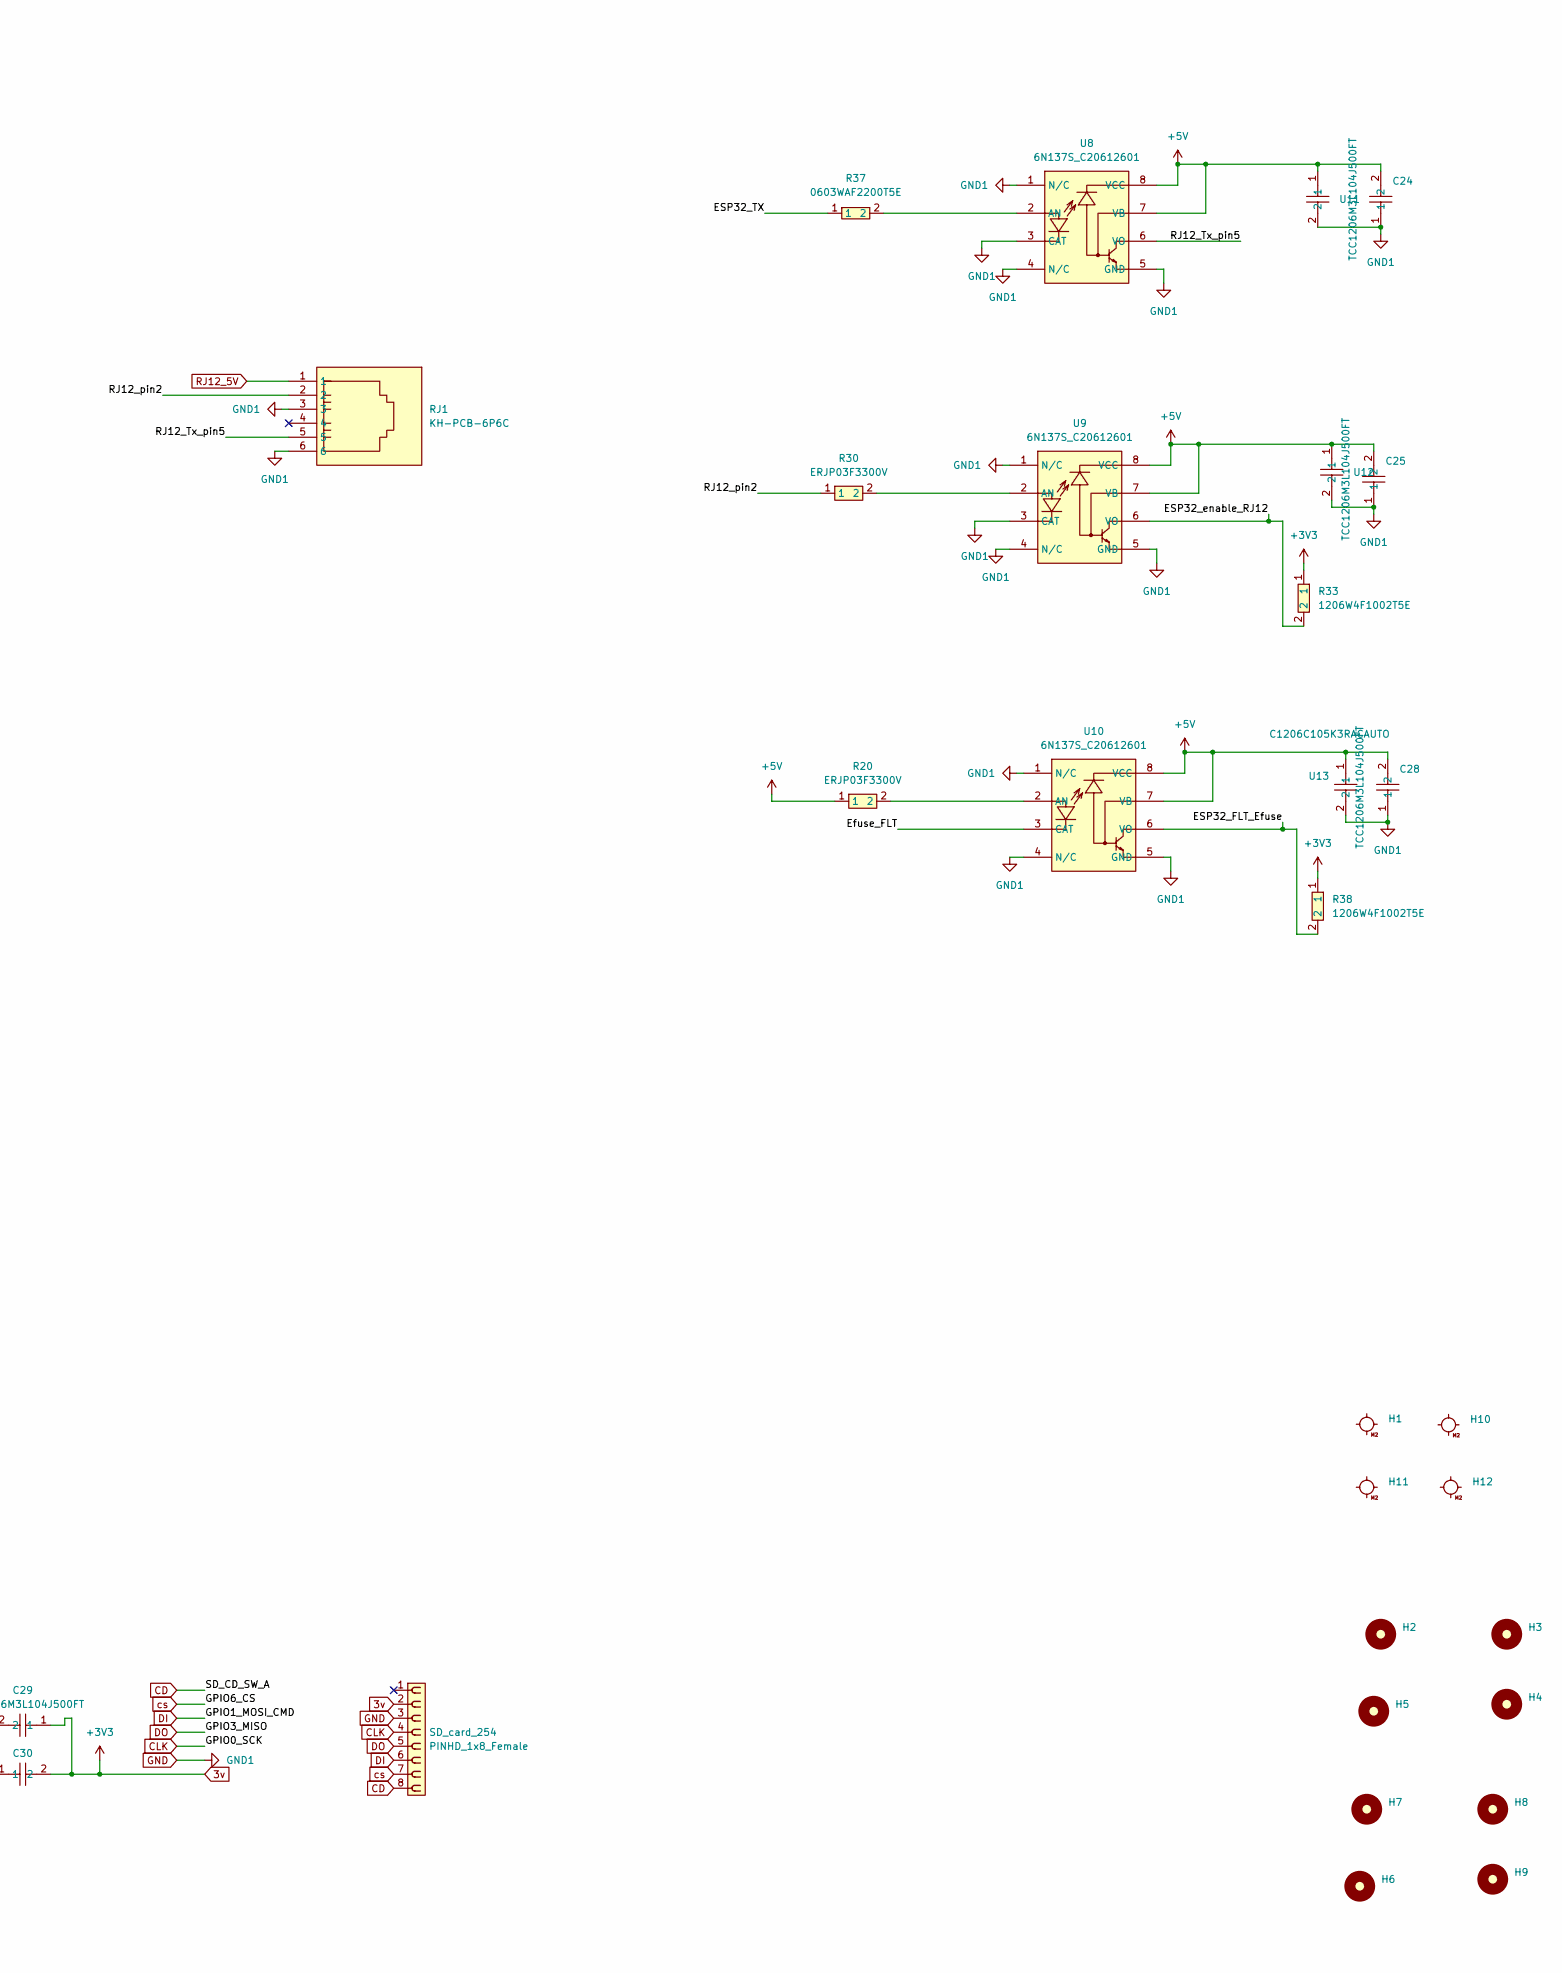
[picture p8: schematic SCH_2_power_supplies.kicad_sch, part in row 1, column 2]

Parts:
C7: C1206C225K3RACTU; C1206; MPN C1206C225K3RACTU; LCSC Part C2167942
C8: GRM3195C1H223JA01D; C1206; MPN GRM3195C1H223JA01D; LCSC Part C97929
C9, C10: GRM32ER71J106KA12L_C437568; C1210; MPN GRM32ER71J106KA12L; LCSC Part C437568
C11, C19, C24, C25, C28, C29: TCC1206M3L104J500FT; C1206; MPN TCC1206M3L104J500FT; LCSC Part C359189
C12, C30: FS31X226M160EPG; C1206; MPN FS31X226M160EPG; LCSC Part C3036083
D2, D3: SMBJ5.0A-13-F; SMB_L4.6-W3.6-LS5.3-RD; MPN SMBJ5.0A-13-F; LCSC Part C110528
H1, H10, H11, H12: MountingHole_M2
H2, H3, H4, H5, H6, H7, H8, H9: MountingHole_3.2mm_M3
J1, J3: PINHD_1x20_Female; PinSocket_1x20_P2.54mm_Vertical
J2, J4: PINHD_1x2_Female; PinSocket_1x02_P2.54mm_Vertical
LED1: 0603 Green 509-620mcd; LED0603-RD; MPN KT-0603G; LCSC Part C12624
R9: FRC1206F1R30TS; R1206; MPN FRC1206F1R30TS; LCSC Part C2907365
R13: FRC1206F3012TS; R1206; MPN FRC1206F3012TS; LCSC Part C48533691
R14: CRCW06037K50FKEA; R0603; MPN CRCW06037K50FKEA; LCSC Part C844808
R15: RS-03K1332FT; R0603; MPN RS-03K1332FT; LCSC Part C321713
R16: AR03FTC2672; R0603; MPN AR03FTC2672; LCSC Part C234417
R17: HRC0603F2673ENTN; R_0603_1608Metric; MPN HRC0603F2673ENTN; LCSC Part C55098397
R18: WR12X3742FTL; R1206; MPN WR12X3742FTL; LCSC Part C908492
R19: CL1206FN158KPS; R1206; MPN CL1206FN158KPS; LCSC Part C53283992
R20, R30: ERJP03F3300V; R0603; MPN ERJP03F3300V; LCSC Part C427299
R21, R22: FRC1206J104 TS; R1206; MPN FRC1206J104 TS; LCSC Part C2907421
R33, R38: 1206W4F1002T5E; R1206; MPN 1206W4F1002T5E; LCSC Part C17902
R37: 0603WAF2200T5E; R0603; MPN 0603WAF2200T5E; LCSC Part C22962
RJ1: KH-PCB-6P6C; RJ45-TH_KH-PCB-6P6C; MPN KH-PCB-6P6C; LCSC Part C2683354
RJ12_5V1: RH-5117; TESTPOINT-TH_BD3.2-D1.6; MPN RH-5117; LCSC Part C5199807
SD_card_254: PINHD_1x8_Female; PinSocket_1x08_P2.54mm_Vertical
SW4: SK-1500-L1?; SW-SMD_6P-P1.50_L2.7-W11.2; MPN SK-1500-L1; LCSC Part C319025
TP3: RH-5002; TESTPOINT-TH_BD2.5-D1.2_RH-5002; MPN RH-5002; LCSC Part C5199802
U4: TPS26625DRCR; VSON-10_L3.0-W3.0-P0.50-TL-EP-1; MPN TPS26625DRCR; LCSC Part C2862873
U5, U11, U12, U13: C1206C105K3RACAUTO; C1206; MPN C1206C105K3RACAUTO; LCSC Part C2167173
U8, U9, U10: 6N137S_C20612601; SOP-8_L9.7-W6.5-P2.54-LS10.3-BL; MPN 6N137S; LCSC Part C20612601
U14: TPS2553DBVR; SOT-23-6_L2.9-W1.6-P0.95-LS2.8-BR; MPN TPS2553DBVR; LCSC Part C55266
U15: ESP32-S3-DevKitC

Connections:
3v: C11.1, C12.2, C29.1, C30.2, J1.1, J1.2, R33.1, R38.1, SD_card_254.2
+5V: C19.1, C24.2, C25.2, C28.2, D2.1 (C), R19.2, R20.1, R21.1, R22.2, U4.1 (IN), U5.2, U8.7 (VB), U8.8 (VCC), U9.7 (VB), U9.8 (VCC), U10.7 (VB), U10.8 (VCC), U11.1, U12.1, U13.1; also elsewhere on the board
/SCH_1_USB_5volt/GPIO4_Battery: J1.4; also elsewhere on the board
/SCH_2_power_supplies/5V_ESP_module: J2.1
/SCH_2_power_supplies/ESP32_FLT_Efuse: J1.6, R38.2, U10.6 (VO)
/SCH_2_power_supplies/ESP32_TX: J3.2, R37.1
/SCH_2_power_supplies/ESP32_enable_RJ12: J1.5, R33.2, U9.6 (VO)
/SCH_2_power_supplies/Efuse_FLT: R21.2, U4.9 (~FLT), U10.3 (CAT)
/SCH_2_power_supplies/RJ12_Tx_pin5: RJ1.5, U8.6 (VO)
/SCH_2_power_supplies/RJ12_pin2: R30.1, RJ1.2
CD: J1.7, SD_card_254.8
CLK: J1.18, SD_card_254.4
DI: J1.17, SD_card_254.6
DO: J1.19, SD_card_254.5
GND: C7.1, C9.1, C10.1, C11.2, C12.1, C19.2, C24.1, C25.1, C28.1, C29.2, C30.1, D2.2 (A), D3.2 (A), J2.2, J3.1, J4.1, J4.2, LED1.1 (K), RJ1.3, RJ1.6, SD_card_254.3, SW4.7, SW4.8, SW4.9, SW4.10, TP3.1, U4.6 (GND), U4.11 (EP), U5.1, U8.1 (N/C), U8.3 (CAT), U8.4 (N/C), U8.5 (GND), U9.1 (N/C), U9.3 (CAT), U9.4 (N/C), U9.5 (GND), U10.1 (N/C), U10.4 (N/C), U10.5 (GND), U11.2, U12.2, U13.2; also elsewhere on the board
unnamed: LED1.2 (A), R9.1
unnamed: R14.2, SW4.6
unnamed: R15.2, SW4.5
unnamed: R16.2, SW4.2
unnamed: R17.1, SW4.1
unnamed: SW4.3, SW4.4, U4.7 (ILIM)
unnamed: R13.2, R18.1, U4.3 (OVP)
unnamed: C8.1, R13.1, R14.1, R15.1, R16.1, R17.2, U4.5 (RTN)
unnamed: R18.2, R19.1, U4.2 (UVLO)
unnamed: C8.2, U4.8 (dVdT)
unnamed: R22.1, U4.4 (~SHDN)
unnamed: R37.2, U8.2 (AN)
unnamed: R30.2, U9.2 (AN)
unnamed: R20.2, U10.2 (AN)
unnamed: U15.1 (3V3), U15.2 (3V3)
unnamed: U15.22 (GND), U15.23 (GND), U15.24 (GND), U15.44 (GND)
RJ12_5V: C7.2, C9.2, C10.2, D3.1 (C), R9.2, RJ1.1, RJ12_5V1.1, U4.10 (OUT)
cs: J1.20, SD_card_254.7

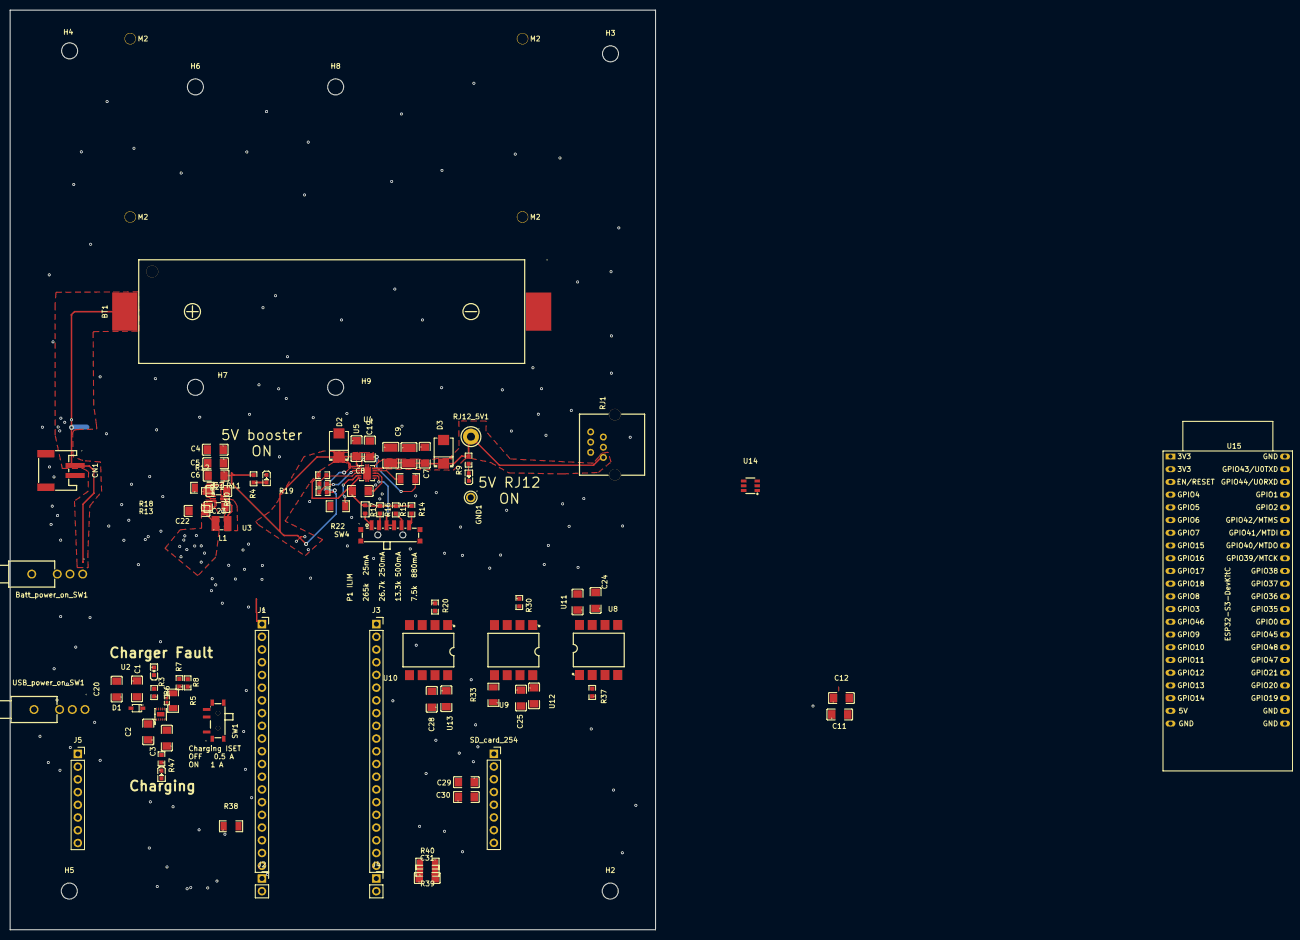
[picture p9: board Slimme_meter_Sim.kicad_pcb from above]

Board: 2 copper layers, 128.9 x 183.6 mm, 98 parts (1 on the bottom side), 50 nets.

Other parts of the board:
U3: TPS61023DRLR; SOT-563_L1.6-W1.2-P0.50-LS1.6-BR

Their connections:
+5V: U3.6 (VOUT); also elsewhere on the board
GND: U3.4 (GND); also elsewhere on the board
unnamed 34: U3.2 (EN); also elsewhere on the board
unnamed 35: U3.1 (FB); also elsewhere on the board
unnamed 36: U3.5 (SW); also elsewhere on the board
VCC: U3.3 (VIN); also elsewhere on the board

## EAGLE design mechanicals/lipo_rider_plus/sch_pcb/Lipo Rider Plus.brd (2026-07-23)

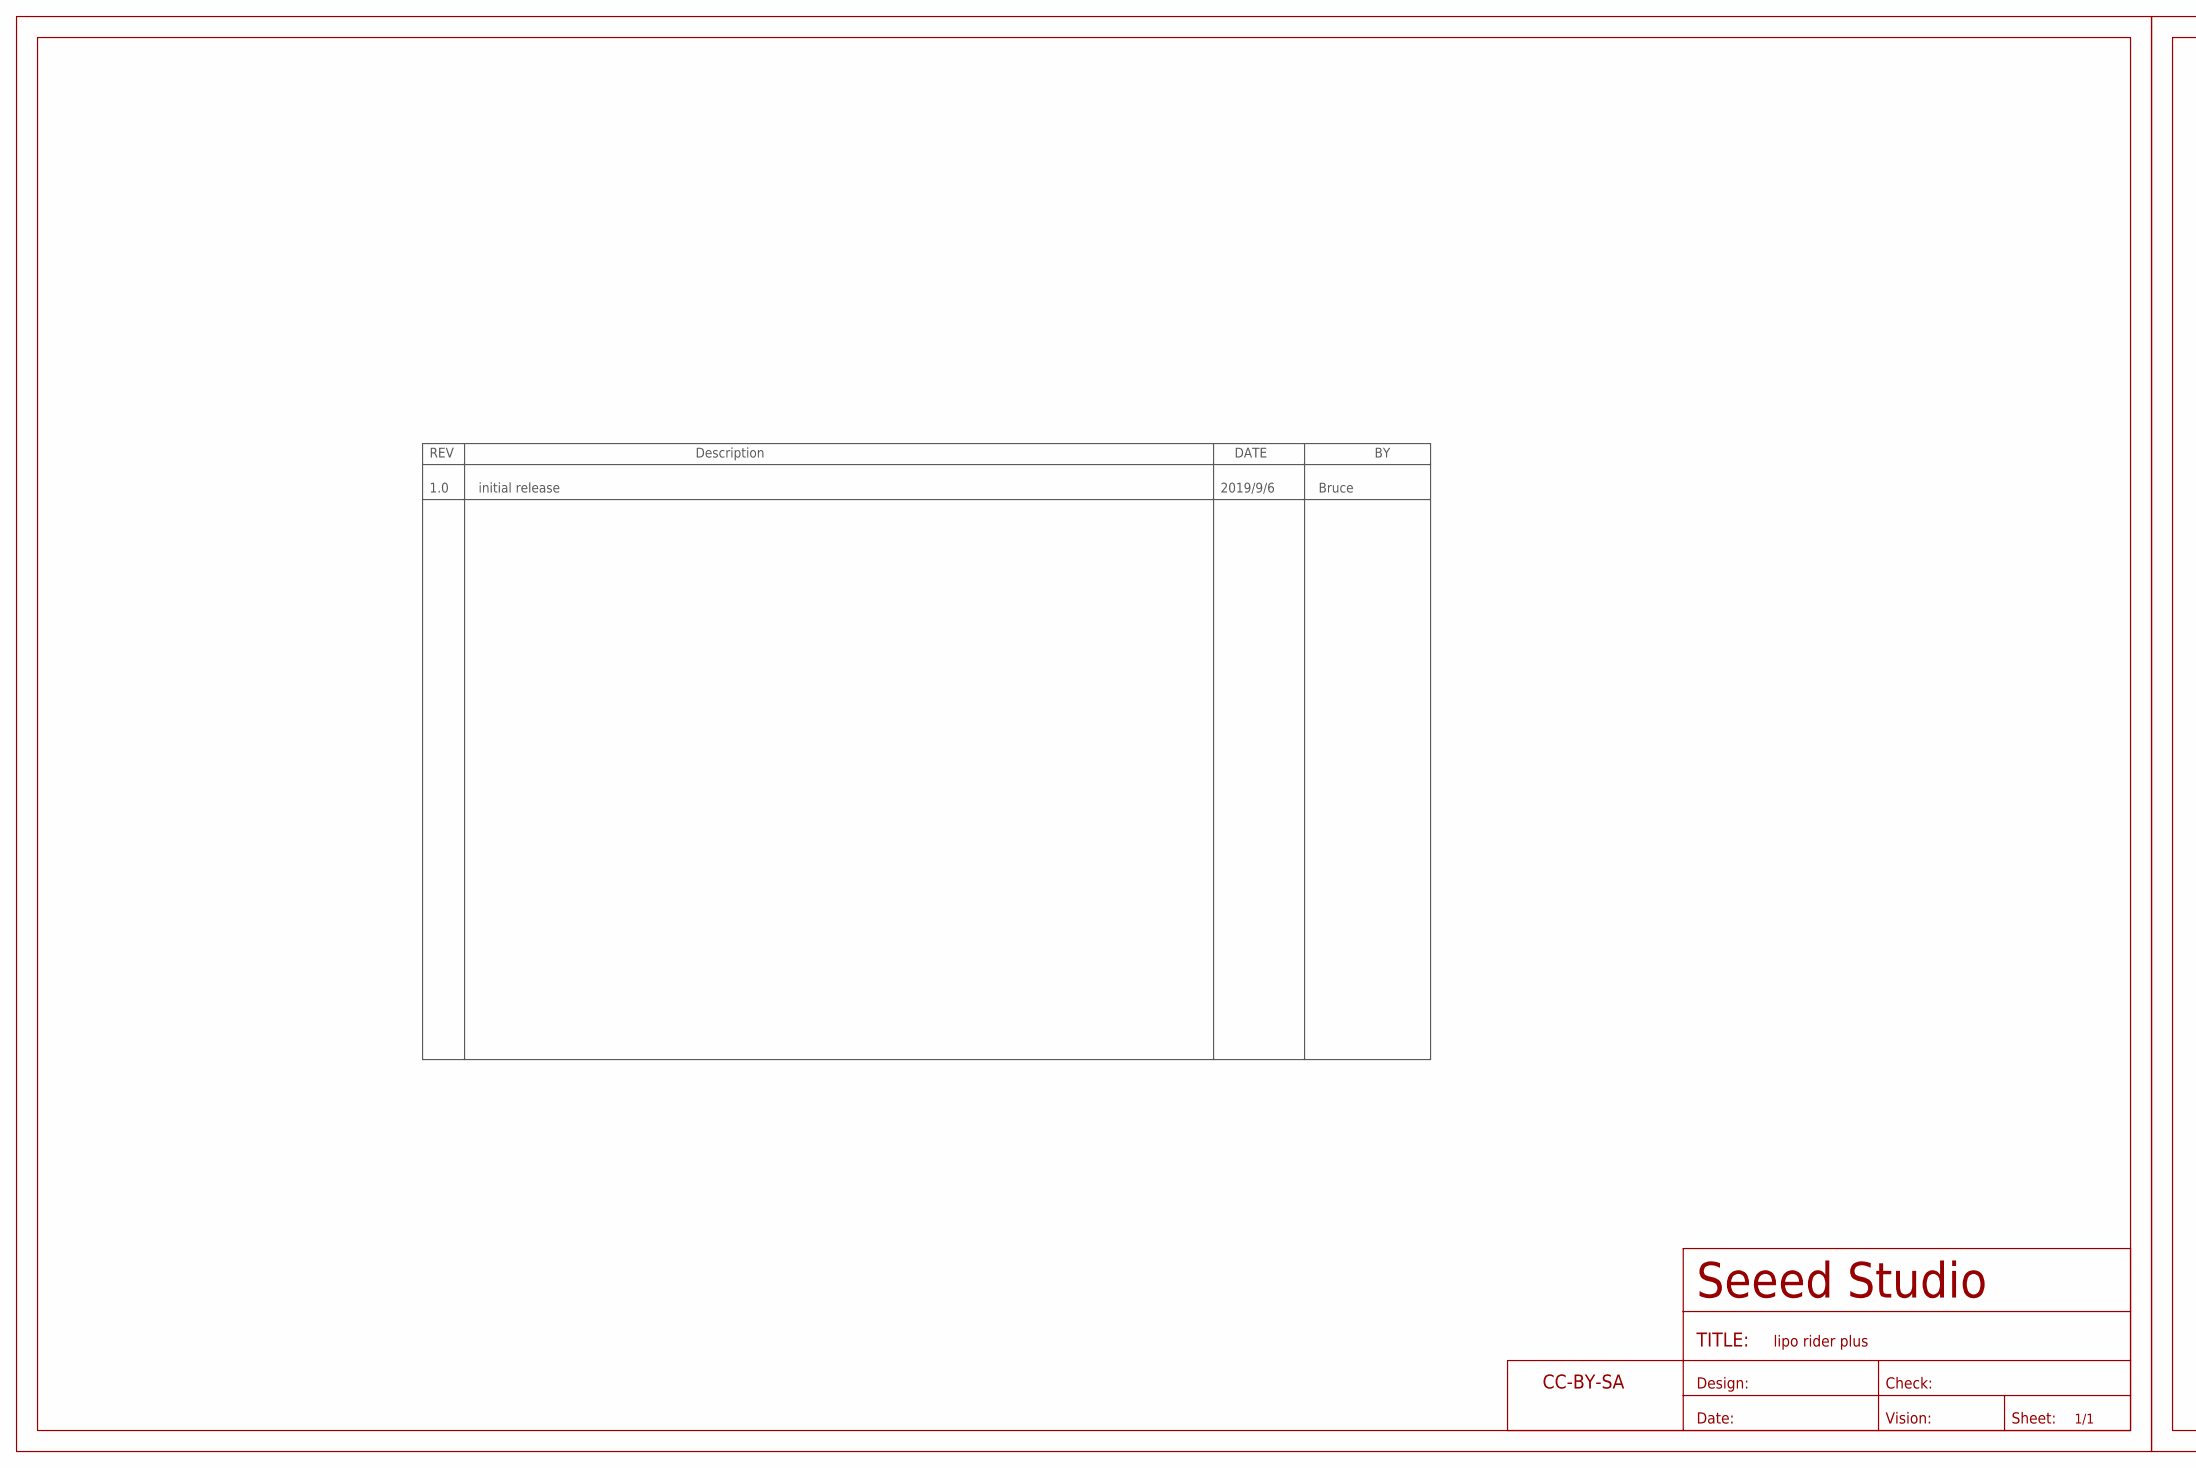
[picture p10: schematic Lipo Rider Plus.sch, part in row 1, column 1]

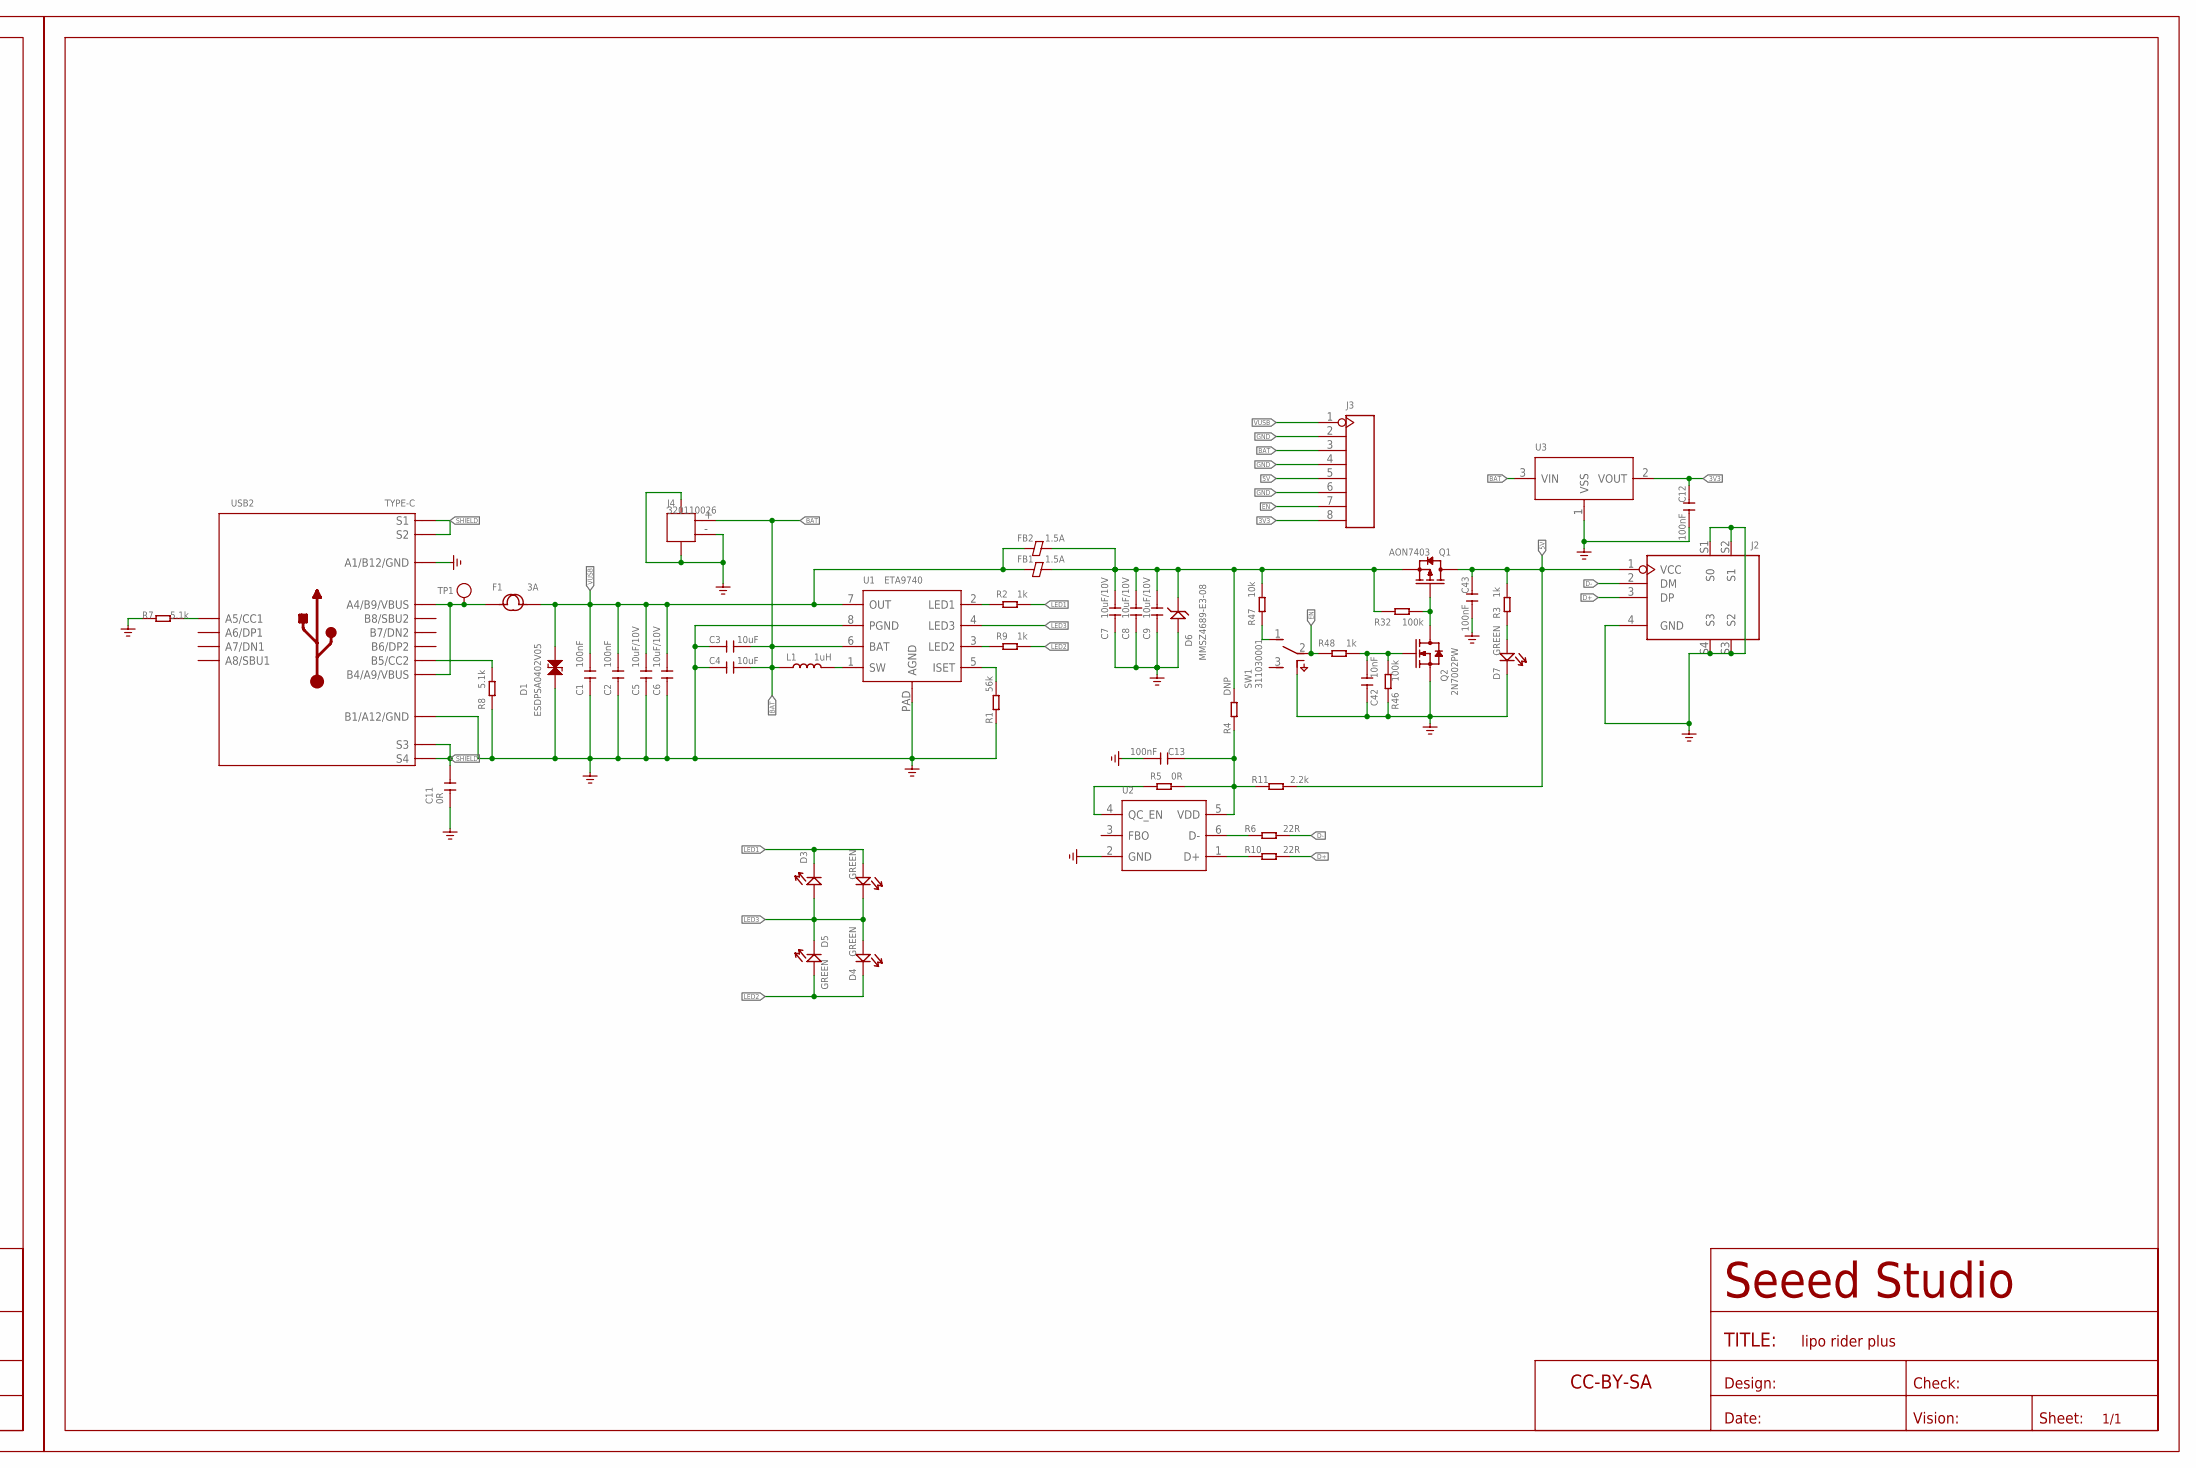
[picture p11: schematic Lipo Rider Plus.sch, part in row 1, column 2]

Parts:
C1, C2, C12, C13, C43: 100nF; C0402
C3, C4: 10uF; C0603
C5, C6, C7, C8, C9: 10uF/10V; C0805
C11: 0R; C0402
C42: 10nF; C0402
D1: ESDPSA0402V05; ESD-0402
D2, D3, D4, D5, D7: GREEN; LED-0402
D6: MMSZ4689-E3-08; SOD-123
F1: 3A; F1812
FB1, FB2: 1.5A; F0805
FR1, FR2: SEEEDSTUDIO-OPEN-SCH-FRAME-BIG; SEEEDSTUDIO-PCB-FRAME
J2: USB4+4P-SMD+DIP; USB4+4P-2.0-14.6X10.6X5.72MM
J3: HEADER-8P-65/35MIL; H8-2.54-C65D35MIL
J4: 320110026; HW2-SMD-2.0-90D
L1: 1uH; L4.4X3.0MM
Q1: AON7403; DFN8P-0.65-3X3X0.8MM
Q2: 2N7002PW; SOT-323
R1: 56k; R0402
R2, R3, R9, R48: 1k; R0402
R4: DNP; R0402
R5: 0R; R0402
R6, R10: 22R; R0402
R7, R8: 5.1k; R0402
R11: 2.2k; R0402
R32, R46: 100k; R0402
R47: 10k; R0402
SW1: 311030001; SW7-SMD-L6.7X2.7X3.2MM
TP1: TEST; TP-D45MIL
U1: ETA9740; ESOP8L-1.27-5X3.9MM
U2: CONTROLLER-FP6601Q; SOT-23-6
U3: PMIC-XC6206PMR; SOT-23
USB2: TYPE-C; USB2.0-TYPE-C

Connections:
3V3: C12.1, J3.8, U3.2 (VOUT)
5V: C43.1, J2.1 (VCC), J3.5, Q1.5 (D), Q1.6 (D), Q1.7 (D), Q1.8 (D), Q1.9 (D), R3.2, R11.2
BAT: C3.1, C4.1, J3.3, J4.+ (1), L1.1, U1.6 (BAT), U3.3 (VIN)
D+: J2.3 (DP), R10.2
D-: J2.2 (DM), R6.2
EN: J3.7, R48.1, SW1.2 (COM)
GND: C1.2, C2.2, C3.2, C4.2, C5.1, C6.1, C7.1, C8.1, C9.1, C11.2, C12.2, C13.2, C42.2, C43.2, D1.1, D6.+, D7.-, J2.4 (GND), J2.S1 (S0), J2.S2 (S1), J2.S3 (S2), J2.S4 (S3), J3.2, J3.4, J3.6, J4.3, J4.4, J4.- (2), Q2.2 (S), R1.1, R7.1, R8.2, R46.1, SW1.SS1 (SS2), SW1.SS2, SW1.SS3 (SS2), SW1.SS4 (SS2), U1.8 (PGND), U1.PAD (AGND), U2.2 (GND), U3.1 (VSS), USB2.A1_B12 (A1/B12/GND), USB2.B1_A12 (B1/A12/GND)
LED1: D2.+, D3.-, R2.2
LED2: D4.-, D5.+, R9.2
LED3: D2.-, D3.+, D4.+, D5.-, U1.4 (LED3)
unnamed: R7.2, USB2.A5 (A5/CC1)
unnamed: R8.1, USB2.B5 (B5/CC2)
unnamed: R47.1, SW1.1 (A)
unnamed: F1.1, TP1.T, USB2.A4_B9 (A4/B9/VBUS), USB2.B4_A9 (B4/A9/VBUS)
unnamed: D7.+, R3.1
unnamed: R1.2, U1.5 (ISET)
unnamed: L1.2, U1.1 (SW)
unnamed: R9.1, U1.3 (LED2)
unnamed: R5.1, U2.4 (QC_EN)
unnamed: C13.1, R4.1, R5.2, R11.1, U2.5 (VDD)
unnamed: R2.1, U1.2 (LED1)
unnamed: R6.1, U2.6 (D-)
unnamed: R10.1, U2.1 (D+)
unnamed: Q1.4 (G), Q2.3 (D), R32.2
unnamed: C42.1, Q2.1 (G), R46.2, R48.2
SHIELD: C11.1, USB2.S1, USB2.S2, USB2.S3, USB2.S4, USB2.S5 (S1), USB2.S6 (S2)
VCC_5V: C7.2, C8.2, C9.2, D6.-, FB1.2, FB2.2, Q1.1 (S), Q1.2 (S), Q1.3 (S), R4.2, R32.1, R47.2
VUSB: C1.1, C2.1, C5.2, C6.2, D1.2, F1.2, FB1.1, FB2.1, J3.1, U1.7 (OUT)

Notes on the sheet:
1.0
initial release
2019/9/6
Bruce

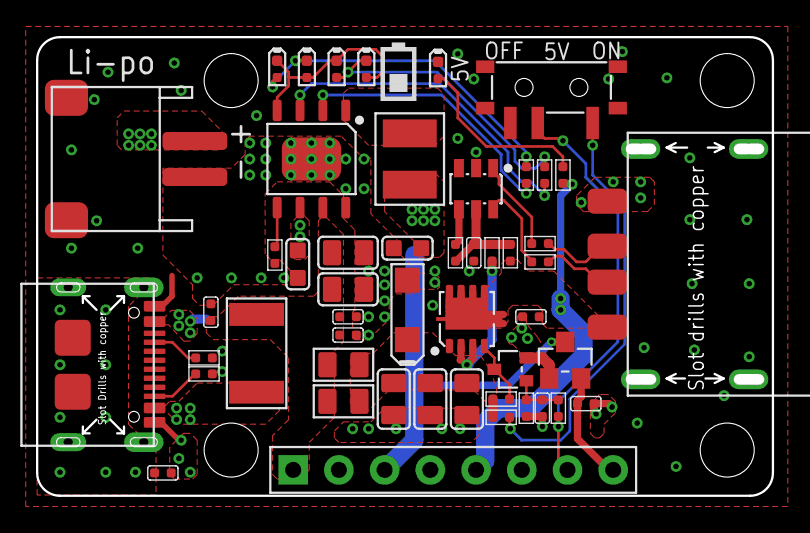
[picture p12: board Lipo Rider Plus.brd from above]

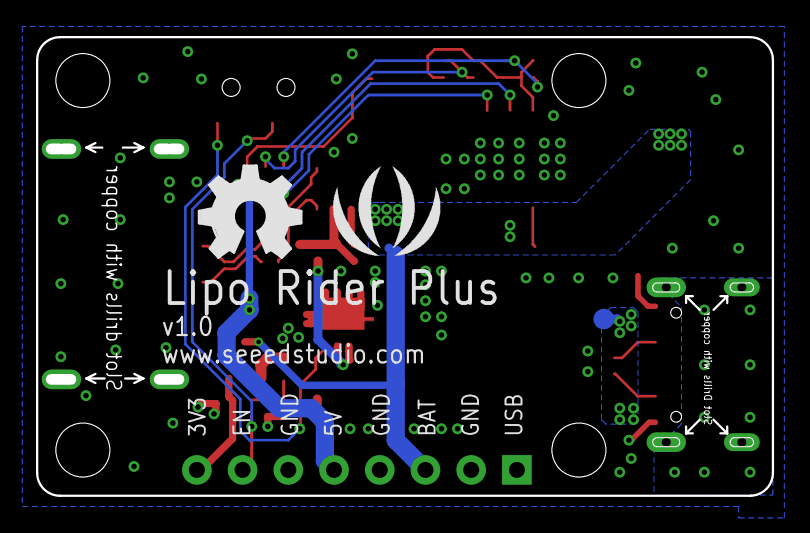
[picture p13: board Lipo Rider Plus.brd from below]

Board: 2 copper layers, 40.9 x 25.5 mm, 55 parts (3 on the bottom side), 28 nets.

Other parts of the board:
U$1: SEEED-SILK-TNAME-280*268MIL
U$2: OSHW_FILLX200_NOTEXT_TNAME

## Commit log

2026-07-23 Add DSMR P1 smart meter simulator design guide.
    Documents architecture, missing blocks, and a day-by-day PCB subcircuit plan.
2026-07-23 Update power notes to Lipo Rider Plus; clarify USB isolation options.
    Replace rejected power-path guidance with a buy-ready USB-C module (5V+3.3V) and document USB data vs charge.
2026-07-23 Adopt Lipo Rider Plus as power module; add KiCad mount footprint.
    Update README/DESIGN_GUIDE/circuit notes. Add mechanicals from Seeed Eagle (outline, holes, header) plus placeholder 3D.
    [Lipo Rider Plus.brd, Lipo Rider Plus.sch]
2026-07-23 Lock power on Seeed Lipo Rider Plus daughterboard; clean docs.
    Drop discrete charger / current-limit / extra 3V3 paths. Align README, DESIGN_GUIDE, and circuit notes.
2026-07-28 Lock portable simulator architecture and add Adafruit bq25185 reference.
    Document onboard 5V-to-3.3V, microSD store, opto P1 paths, and import Adafruit #6106 Eagle/KiCad files under my_design/libraries for integration.
2026-07-28 Lock integrated bq25185 + TPS61023 power path and clarify VSYS.
    Document that V+/VSYS is not 5V, keep the boost for P1 and 3.3V headroom, and retire Lipo Rider as the primary power design.
2026-07-31 Add Slimme_meter_Sim KiCad project through TPS61023 SYS_5V.
    Schematic sheet covers USB-C, bq25185 charge path, and boost to 5 V for the downstream 3V3 and P1 supplies.
    [SCH_1_USB_5volt_sch.kicad_sch, Slimme_meter_Sim.kicad_pcb, Slimme_meter_Sim.kicad_sch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]
2026-07-31 Document design rationale through SYS_5V and drop third-party power refs.
    Adds DESIGN_REPORT on why/how the simulator power path was chosen, points docs at Slimme_meter_Sim, and removes the external bq25185 boost reference tree from the repo.
2026-08-02 Add sheet-2 power/MCU schematic progress and document P1 opto domains.
    Captures TPS26625, SY8088 3V3, ESP32-C3, RJ12 placement, and README guidance that Request/Data optos keep UART on 3.3 V while pin 5 stays open-collector on the 5 V P1 side.
    [SCH_1_USB_5volt_sch.kicad_sch, SCH_2_power_supplies.kicad_sch, Slimme_meter_Sim.kicad_pcb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]
2026-08-02 Add FIRMWARE_GUIDE with pin map, opto polarities, and UART reminders.
    Documents Request active-low, Data OC TX on GPIO21, resistor choices, and links from README / design docs / circuit notes.
2026-08-03 Save KiCad schematic/PCB progress and park Pi next-step ideas.
    Document assembly (stencil + hot air) and the dual-domain Pi brain option so the ESP32 path can be resumed cleanly tomorrow.
    [SCH_1_USB_5volt_sch.kicad_sch, SCH_2_power_supplies.kicad_sch, Slimme_meter_Sim.csv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]
2026-08-04 Save Slimme_meter_Sim KiCad progress: PCB/schematic, footprints, and firmware pin map.
    [SCH_1_USB_5volt_sch.kicad_sch, SCH_2_power_supplies.kicad_sch, Slimme_meter_Sim.csv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]
2026-08-05 Save production-ready Slimme_meter_Sim Gerbers, JLCPCB BOM/CPL, and finished PCB.
    [JLCPCB_BOM-JLCPCB Assembly Order.xls, JLCPCB_BOM.csv, JLCPCB_BOM.xlsx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]
2026-08-07 checkpoint before checking out cursor/lock-simulator-architecture-bq25185
    [JLCPCB_BOM-JLCPCB Assembly Order.xls, JLCPCB_BOM.csv, JLCPCB_BOM.xlsx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]
2026-08-07 Start slimme big-modular hand-build path as active design.
    Document on-PCB power/P1/optos with modular USB-C data, microSD, and ESP32 only; leave parent simulator docs unchanged.
2026-08-07 Retarget big-modular path to S3 DevKit brain plus slim P1 carrier.
    Use SparkFun Thing Plus ESP32-S3 for USB-C, SD, LiPo and 3.3V; carrier takes V_USB for TPS2553, INA and optos.
2026-08-07 Replace Thing Plus with CoreS3 for real battery-to-5V output.
    Document AXP2101 Grove 5V path so the slim P1 board can run from JST/internal battery without a power bank.
2026-08-10 Lock big-modular plan on DevKitC WROOM-2 with dual eFuse and safe 5V powering.
    Document diode/switch power rules, USB-C/SD breakouts, N32R16V MCU module, and continue KiCad power sheets for the hand-build carrier.
    [SCH_1_USB_5volt_sch.kicad_sch, SCH_2_power_supplies.kicad_sch, Slimme_meter_Sim.kicad_pcb]
2026-08-12 Checkpoint big-modular KiCad and FP6276B tooling before deeper power modularization.
    Save DevKitC reference assets, USB-C breakout zip, boost datasheet/designer, and current schematic/PCB/library progress on the hand-build path.
    [BOM(V0.3)_ESP32-S3-DevKitC-1_XX_TTNNVV.xlsx, Fabrication_Requirements_ESP32-S3-DevKitC-1_20220429.xls, SCH_1_USB_5volt_sch.kicad_sch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]

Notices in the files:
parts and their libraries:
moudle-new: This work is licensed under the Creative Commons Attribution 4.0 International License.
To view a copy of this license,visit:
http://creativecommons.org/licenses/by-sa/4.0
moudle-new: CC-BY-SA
